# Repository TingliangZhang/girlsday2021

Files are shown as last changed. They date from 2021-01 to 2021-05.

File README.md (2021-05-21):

# Girl's Day of 2021 Presents Design
2021年交叉班女生节礼物——名片 设计

智能名片交互hhh

赛博朋克区块链

## 功能

Tagmo - 制作自己的Amiibo

[Popl - Your digital business card](https://popl.co/)

卡里面只有一个ID和我们服务器网址信息，具体这张名片能传达多少社交信息就由用户在网页端或者客户端配置了。以及最好加密一下，防止被轻易拿去干别的，比如友商出个教程，我们的卡就都变成他们的了

[The Blue Smart Card](https://blue.social/) - Reinventing the Name Tag. Create your virtual identity and be social again.

[Mobilo - The Smart Business Card](https://www.mobilocard.com/)

[Fuze Card, 0.84mm innovative electronic card technology.](https://fuzecard.com/)

KickStarter页面 [Fuze Card](https://www.indiegogo.com/projects/fuze-card-your-whole-wallet-in-one-card--3#/): Your Whole Wallet in One Card

[Unbox Therapy](https://www.youtube.com/channel/UCsTcErHg8oDvUnTzoqsYeNw)评测视频：[Your Whole Wallet In One Card](https://www.youtube.com/watch?v=7SPOVJi3H6g)

[Find Your Keys, Wallet & Phone with Tile's App and Bluetooth](https://www.thetileapp.com/en-us/)

[2.13寸 无源NFC 墨水屏 e-paper ESL电子货架标签 无线供电/刷新](https://item.taobao.com/item.htm?id=613699970326)

微雪NFC墨水屏标签

[小米碰碰贴2](https://item.jd.com/100014996634.html) nfc感应开关 全能投屏音乐接力碰触连网一碰连接米家智能场景

## 可参考项目

[PCB Business Card With NFC](https://www.instructables.com/PCB-Business-Card-With-NFC/) - 能存网址的名片

[THE NFC KEY](https://n-o-d-e.net/nfckey.html) - 存储密钥的带物理按键NFC

[Digital Business Card With NFC](https://www.instructables.com/Digital-Business-Card-With-NFC/) - 只是把NFCTag扔进两张纸之间去了。

[StyloCard](https://mitxela.com/projects/stylocard) - 乐器名片

[L-ink_Card](https://github.com/peng-zhihui/L-ink_Card) - 带墨水屏的NFC Tag

## 问题

手机的NFC功能可能默认关闭，而且NFC线圈位置不固定：苹果在正面顶部，安卓手机大多在背面。

## 进度追踪

2020/12 提出想法，女生节送智能名片

2021/1/27 开始设计

2021/1/28-29 元件选型和天线参数计算

2021/1/30-2/2 天线python脚本生成编写

2021/2/2 第一版测试板交付嘉立创打样，同时采购了元件，同时着手买NFC和RFID读取器

2021/2/4 V2交付打样，使用白色阻焊，尝试效果

2021/2/7 V1V2打样完成，焊接测试完成，功能完好

2021/2/8 开始规划网站服务，并学习React框架

2021/2/9 M24LR-discovery到货，验证了M24能用3.3V驱动STM32L系列单片机和一个液晶数位屏

2021/2/10 诚驰大哥加入，换用VUE框架，小菜鸡我同步开始学Vue

2021/2/11 除夕，依然干活，微雪的2.7inch NFC e-paper到货，测试尝试复现，并用电纸屏送上新年祝福

2021/2/12 大年初一，选取UX和UI设计工具，开始学习Figma

2021/2/13 开工画UX，画了一上午画出来一个登录界面，UX设计师真不容易，决定先用iPad的Procreate来画草图。

2021/2/15 用户体验设计碰头会，根据建议大改了交互流程，继续画了卡片管理界面，同时注册域名

2021/2/16 交给诚驰写网站，开始头大的Ruby和Jekyll开发环境配置

2021/2/17 搞网站备案，头大，Ruby和Jekyll开发环境还是没配好

2021/2/18 为了拿备案服务号，购买了阿里云一年的主机，并且配置Ubuntu环境和VS Code网页版，终于提交管局审核。把一大箱硬件开发的东西寄回清华。

2021/2/19 把Ruby和Jekyll开发环境配置好，其实就放弃了动态构建，只用build吧，研究Jekyll主题的使用

2021/2/20 返校，使用Ubuntu环境跑Jekyll

2021/2/21 - 22 组装服务器并给服务器装系统，走了很多弯路

2021/2/23 装好了Debian KDE 图形化系统，开始探索如何装虚拟化环境、网站部署

2021/2/24 开始部署Proxmox VE虚拟化服务，遇到了网关和DNS一系列问题

2021/2/25 两网站备案成功，但是服务器还是没跑起来，考虑回退回Debian Buster单系统，继续部署网站。

2021/2/26 开始第二个版本的PCB，准备采用黑色Silkskin，银色Paste，背面参考PCB尺子的设计。同时写社交模式。

2021年2月26日22点前后，人生中第一台自己搭出来的服务器和虚拟化子系统开始运行，快乐！

2021/2/27 确定正反面的形式，找到PCB Ruler参考

2021/2/28 传媒研究，定义碰一碰陌生人社交

2021/3/1 绘制V3样板

2021/3/2 交付打样，一共18个订单

2021/3/3 - 3/7 等待到货，同时在阿里云上部署服务，已部署主页和博客俩服务

2021/3/8 在女生节后一天，卡片到货了总共用了一周，嘉立创产能emmm。开始写文档梳理整件事情

2021/3/9 - 10 继续写

2021/3/11-12 要做发布会视频，24h速成blender

2021/3/13 焊芯片+做发布会PPT+建模

## To Do List

- [x] 云服务器配置
- [x] 本地服务器搭建（Dell R720）
- [x] 域名注册
- [x] 域名备案
- [x] SSL证书（上https）
- [x] 网站搭建
- [x] PCB外观设计
- [x] 自动生成PCB脚本编写（集成bitmap2component）
- [x] 硬件原理调试
- [x] UX和UI设计
- [x] 用户体验测试（大雾）
- [x] SD卡大小Tag设计和测试，特别是V槽拼版
- [ ] 加入墨水屏

## 工具

[KiCAD](http://www.kicad.org/)及其插件

[Interactive HTML BOM plugin for KiCad](https://github.com/openscopeproject/InteractiveHtmlBom)

[AutoCAD](https://www.autodesk.com/products/autocad/overview) 2021 Edu Edition

Linux下软件：

[Krita | Digital Painting. Creative Freedom.](https://krita.org/) 绘画软件

[Draw Freely | Inkscape](https://inkscape.org/) 矢量图编辑器

## 外形设计Outline

依据身份证等使用的ISO 7810-2003国际标准中的ID-1：ID-1的规定尺寸为85.60×53.98毫米（3.370×2.125英寸），常用于身份证、银行卡（如提款卡、信用卡）、驾照、个人名片，以及商店发出的忠实顾客卡等。其长宽比与黄金分割（1.618:1）接近。

ISO 7813规范ID-1塑胶银行卡的附加特性，包括0.76毫米厚度，及3.18毫米半径的圆角。

所以设计为

85.60×53.98毫米

3.18毫米半径的圆角

0.76毫米厚度（做0.8mmPCB板）

横向排版

或者用ID-3画成小的钥匙链

## Tile大小版本设计

Tile Pro：42mm x 42mm x 6.5mm  孔7mm直径

Tile Mate：35mm x 35mm x 6.2mm 孔6.5mm

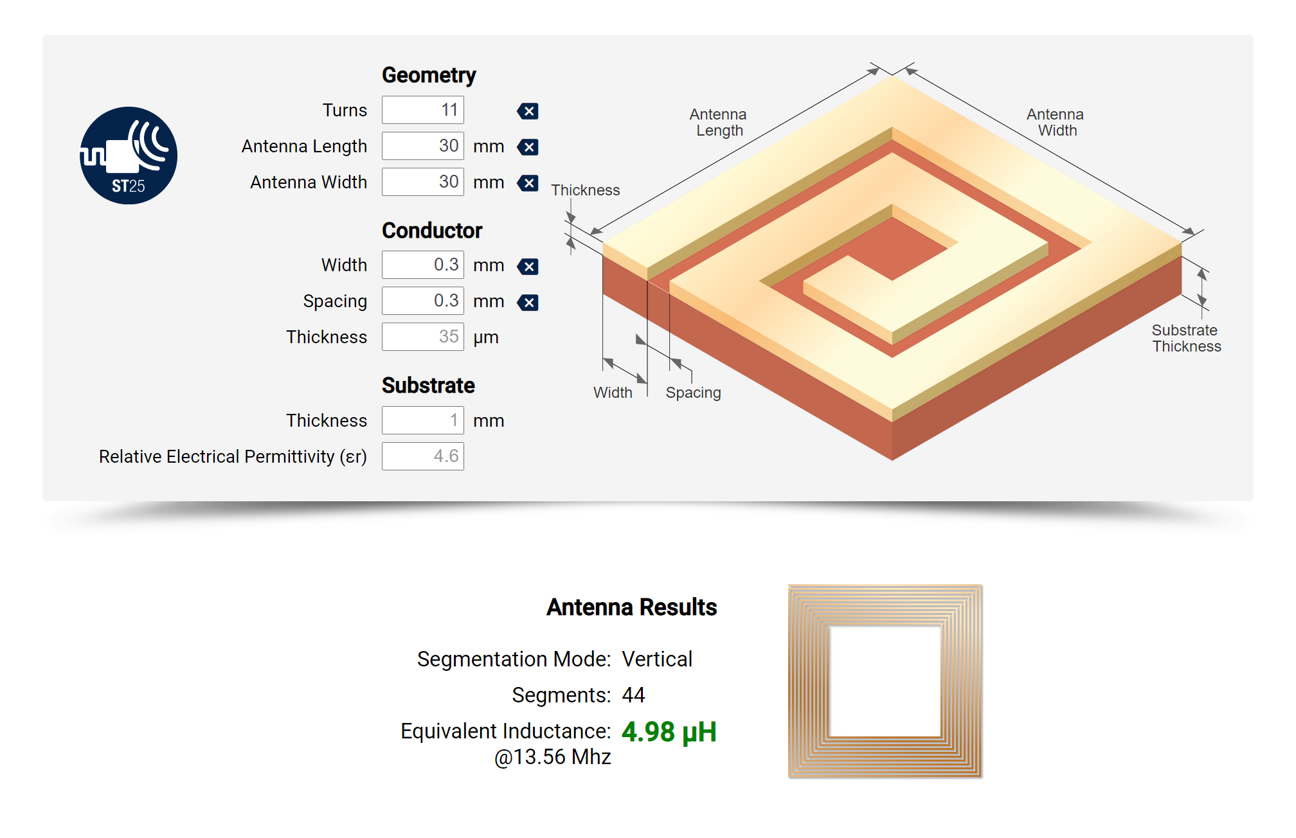
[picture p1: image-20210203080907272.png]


初步设计为 40mm x 40mm x 1.6mm 孔6mm直径 倒角5mm直径圆

天线尺寸为30x30mm 0.3x0.3mm 11圈，电感4.98uH(@13.56Mhz)

天线封装焊盘为 0.3 x 0.5mm圆形通孔（嘉立创双面板最小过孔内径0.3mm,最小外径0.5mm）和 0.3 x 0.5mm矩形贴片焊盘

[嘉立创教学系列之：各软件拼板作业指引](http://club.szlcsc.com/article/details_468_1.html)

嘉立创拼版V割出货：走线和焊盘距板边距离≥0.4mm，否则可能涉及到板内的线路及焊盘，如果是拼版，则线离边必须要有0.4mm间距，否则v割会伤到线路。如果是单片出货，则需要帮≥0.2mm的间距。

VCUT(V割)板边离线的距离不小于0.4MM，CNC（锣边）正常是版边离线的距离不小于0.3MM，内槽离走线离线的最小距离不得小于0.3MM

V-CUT（V割工艺）：

（1）V割的拼板，板与板相连处不留间隙，也就是两块板外形线重叠放置，但是要注意，板子内的导线离V割线距离不小于0.4mm，以免切割时伤到走线。

（2）一般V割后残留的深度为1/3板厚，产品手动掰开后由于玻璃纤维丝有被拉松的现象，尺寸会略有超差，个别产品会偏大以上。

（3）V-CUT刀只能走直线，不能走曲线和折线。

（4）拼板尺寸在8cm以上才能做V-CUT工艺。

拼版设计：

可以考虑30cm x 30cm 九块边缘倒角板子拼起来，横排中间留2mm锣边，纵排无间距V割，纵排两侧有5mm工艺边和2.0mm定位孔及1.0mm的Mark点（一个焊盘）。

全部画在EdgeCut里面就好，嘉立创OEM会帮忙加V割或者锣边，如果版式一样，可以只画一个电路。在复制EdgeCut层的时候，可以在右边隐藏别的层。

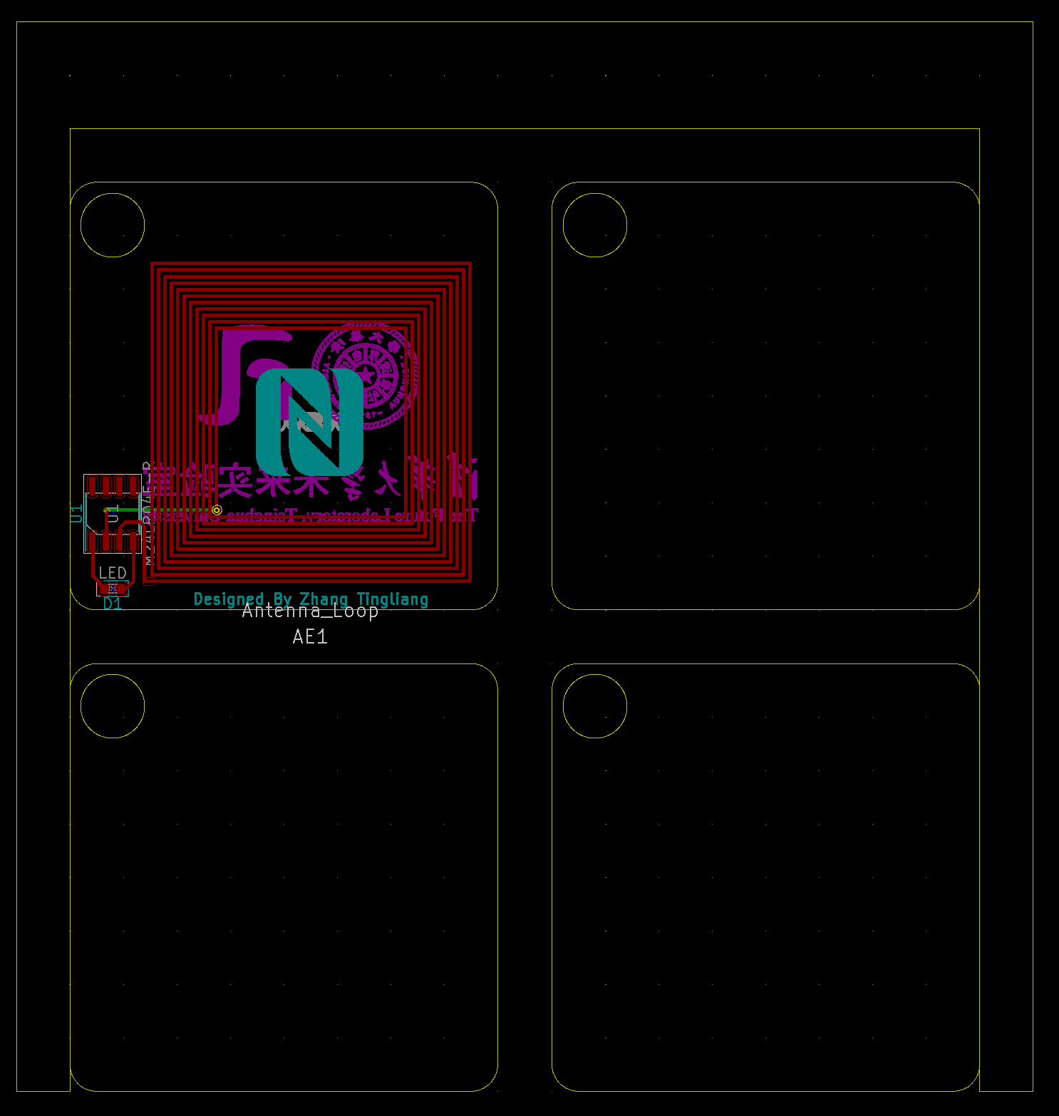
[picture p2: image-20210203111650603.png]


由于强度问题，拼版V割的话还是要紧密连接，不能像上面这种设计。必须要加支撑才行。

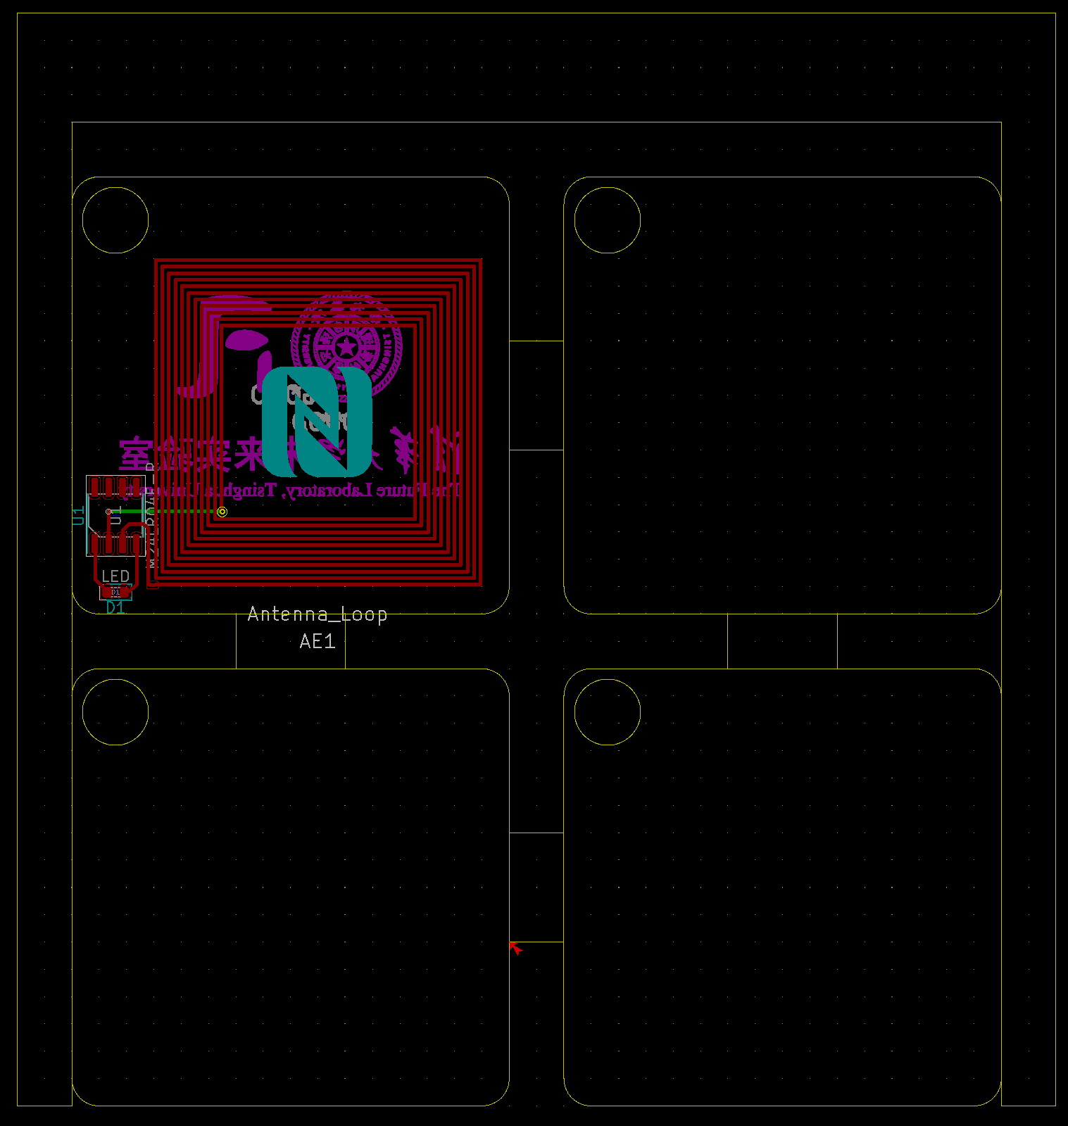
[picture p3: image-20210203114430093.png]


但是拼版订单要多加钱。

所以还是先打单板吧。

## 简笔画头像生成

CV算法生成简笔画头像

[ArtLine](https://github.com/vijishmadhavan/ArtLine)

运行环境：[Colab](https://colab.research.google.com/github/vijishmadhavan/Light-Up/blob/master/ArtLine.ipynb)

CoLab中图片拖到根目录去上传，之后导入：

```python
img = PIL.Image.open("cai.jpg").convert("RGB")
```

[U-2-Net](https://github.com/NathanUA/U-2-Net)还有其前身[APDrawingGAN](https://github.com/yiranran/APDrawingGAN)

## 芯片选型

NXP NTAG

https://www.themobileknowledge.com/wp-content/uploads/2018/07/02-Webinar-slies-Antenna-design-for-NTAG-I2C-plus.pdf

ST25 Dynamic NFC Tags

https://www.st.com/en/nfc/st25-dynamic-nfc-tags.html

ST25DV04K

https://www.st.com/en/nfc/m24lr04e-r.html#overview

[M24LR04E-RMN6T/2](https://item.szlcsc.com/168717.html)[射频卡芯片](https://list.szlcsc.com/catalog/981.html)

测试板：

[M24LR-DISCOVERY](https://www.st.com/en/evaluation-tools/m24lr-discovery.html)

[X-NUCLEO-NFC02A1](https://www.st.com/en/ecosystems/x-nucleo-nfc02a1.html)

## NFC线圈设计

NFC Antenna Generator

https://kbeckmann.github.io/2016/06/19/NFC-Antenna-Generator/

[NFC Antenna Design | RF Design | eDesignSuite](https://eds.st.com/antenna/)

电路中天线电感计算计算：

主要参考AN2866 -  Antenna design procedure

Internal tuning capacitor in ST25DV04K SO8N(f = 13.56 MHz) $C_{TUN} = 28.5 pF$

计算公式：
$$
L_{A} C_{S} \omega^{2}=1
$$
具体推导：
$$
L_{A}=\frac{1}{4 \pi^{2} f^{2} C_{S}}
$$

$$
L_{A}=\frac{1}{4*3.14^{2}*13.56^{2}*28.5}=4.84uH
$$

谐振理论：

At low frequencies $\left(f<f_{\text {self res }} / 10\right),$ the stray capacitance $C_{\text {ant }}$ is negligible, $L_{A}=L_{\text {ant }}$ and the antenna reactance is given by $X_{A}=j L_{\text {ant }} \omega$.
At $13.56 \mathrm{MHz}, \mathrm{C}_{\text {ant }}$ value gets in the range of some $\mathrm{pF}$ and $\mathrm{L}_{\mathrm{A}}>\mathrm{L}_{\text {ant }}$.

The antenna impedance is $Z_{\text {ant }}=R_{A}+j L_{A} \omega$.

The NFC / RFID chip impedance is $Z_{S}=R_{s}+j / C_{S} \omega$.

For the equivalent RLC circuit, the total impedance is $Z_{\text {tot }}=Z_{\text {ant }}+Z_{s}$ and the resonant frequency is given by the condition $L_{A} C_{S} \omega^{2}=1$.
Optimum antenna tuning

At resonant frequency the total impedance reaches its minimum value $Z_{\text {tot }}=R_{A}+R_{S}$. The current in the antenna and the voltage delivered to the NFC / RFID chip are maximized, as the energy transferred to the device.

物理天线电感

嘉立创PCB成品外层铜厚1oz~2oz(35um~70um)选择35um

单片出货，走线和焊盘距板边距离≥0.2mm，否则可能涉及到板内的线路及焊盘。

直接留3.18mm边缘。

最小线隙，多层板3.5mil 单双面板5mil (1mil=1/1000inch=0.0254mm)

Antenna Length =  85.60 - 3.18x2 = 79.24 mm

Antenna Width = 53.98 - 3.18x2 = 47.62 mm

Turns = 6

Equivalent Inductance@13.56 Mhz = 4.98 µH

考虑到布线过程中的寄生电容等，接近4.84 µH，可以接受这一设计。

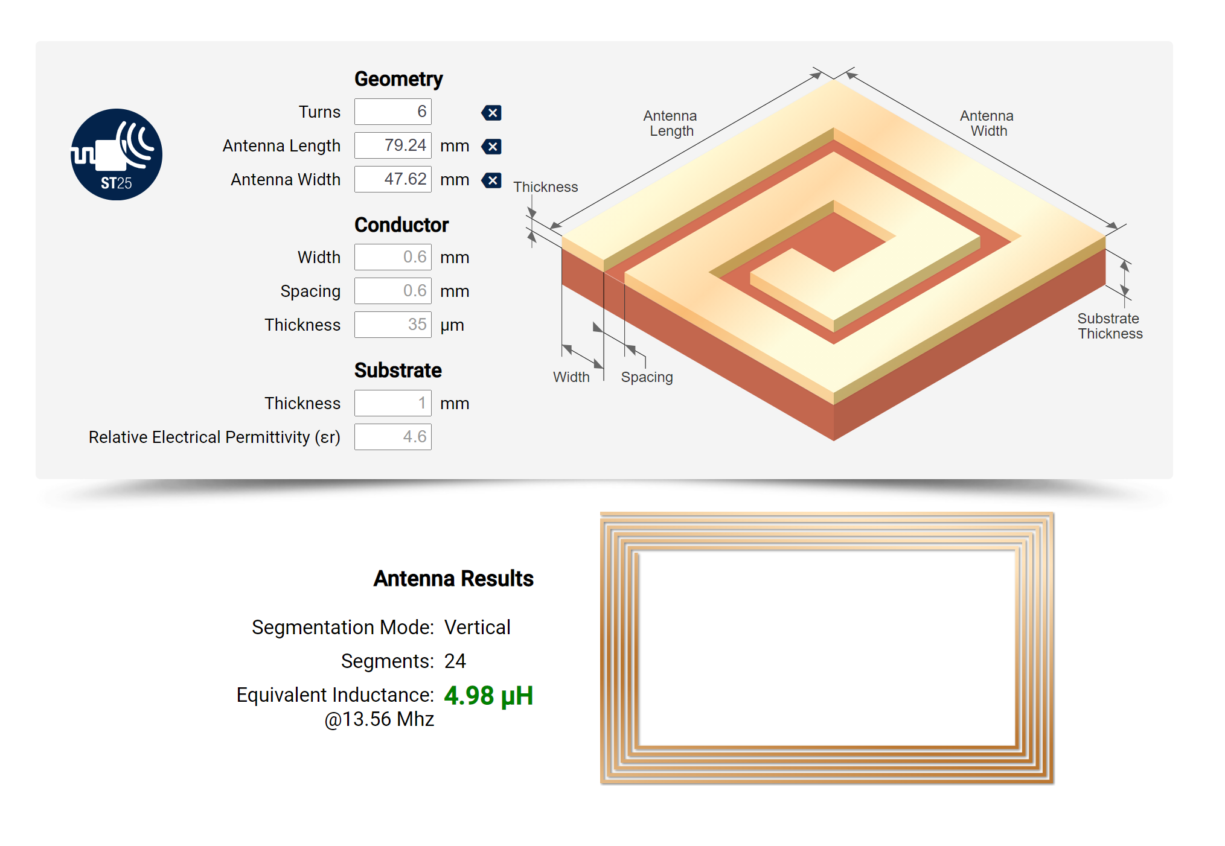
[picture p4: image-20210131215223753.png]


动态NFC天线计算主要参考 AN2972 How to design an antenna for dynamic NFC tags 

封装库画六圈螺线太难了，准备用dxf导入，先使用Adobe Illustrate绘制，依然太麻烦放弃。

还是写py脚本向导吧。

## NFC Antenna创建向导编写

参考官方示例

https://docs.kicad.org/5.1/en/pcbnew/pcbnew.html#Footprint_Wizards

[KiCad Scripting Examples](https://kicad.mmccoo.com/?page_id=83)

参考C:\Program Files\KiCad\share\kicad\scripting\plugins中的脚本。

C:\Users\Zhang\AppData\Roaming\kicad\scripting\plugins

[KiCad](https://github.com/KiCad)/**[kicad-footprint-wizards](https://github.com/KiCad/kicad-footprint-wizards)**

Defining Parameters

Footprint wizards are written in Python and are simple to develop. Each footprint wizard defines a number of footprint parameters, which are organised into categories called "Pages". [Read further on footprint parameters](https://github.com/KiCad/Footprint_Wizards/wiki/Footprint-Parameters)

主要参考microMatch_connectors.py，焊盘直接用SMD的长方形焊盘

To greatly simplify development of custom footprint wizards, the FootprintWizard base class is provided, and only a handful of simple functions need to be written for each wizards. [Read further on minimum wizard requirements](https://github.com/KiCad/Footprint_Wizards/wiki/Minimum-Wizard-Requirements)

先画一个最简单的练手

注意每次更改需要重启KiCAD新脚本才能生效，DeBug的时候因为这个浪费了不少时间。如果加载脚本失败，可以看到报错信息。

通过self.AddParam("Conductor", "spacing", self.uMM, 0.6)传递进来的 self.uMM 其实是已经转化成nm为单位的整型变量了，不需要再用pcbnew.FromMM(1.0)转换为nm。

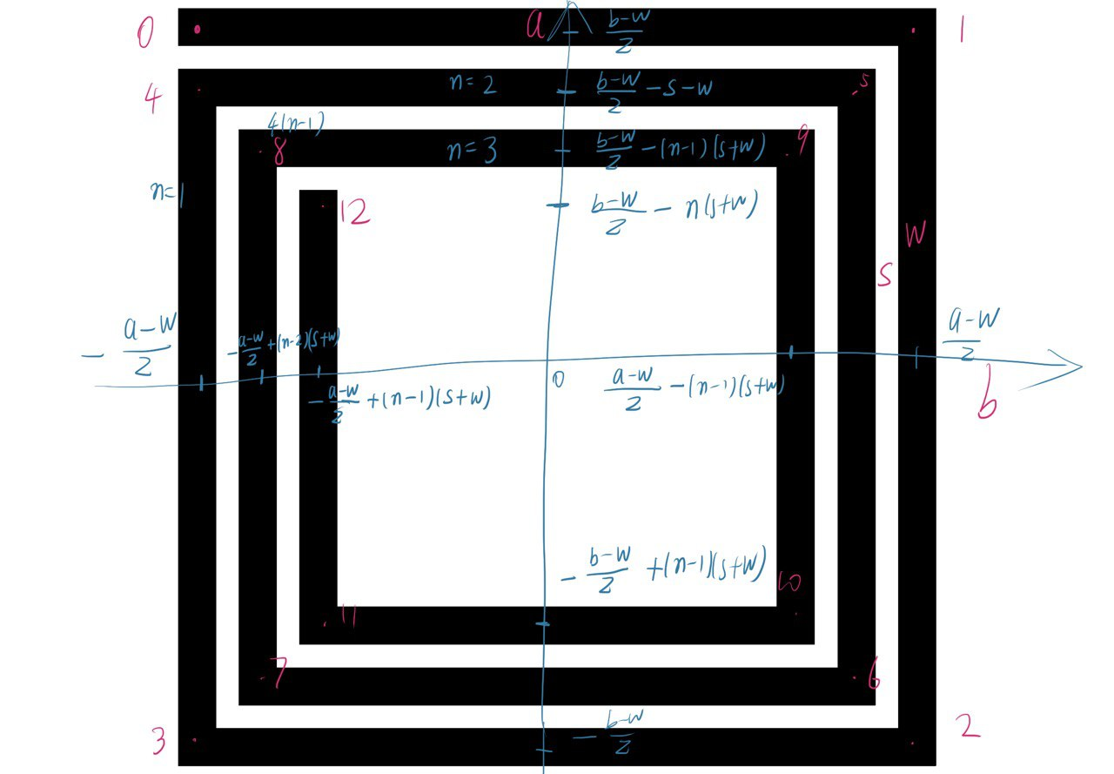
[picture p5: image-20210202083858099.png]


算法可参考HTML的脚本，but我选择自己写hhh

二维数组需要初始化，测试py文件单独编写测试，VScode在安装Python插件后可以在Debug标签页查看变量。

之后手动添加焊盘，嘉立创双面板最小过孔内径0.3mm,最小外径0.5mm，一号焊盘用0.6x1.524mm矩形贴片，注意取消勾选F.Paste和F.Mask工艺层以令外观美观，二号焊盘用圆形通孔0.8x0.5mm，注意取消勾选F.Mask和B.Mask工艺层以令外观美观

左下角：（100，100）

右上角：（185.6，46.02）

中心定位点：（142.8，73.01）

## 信息填写

QR Code Wizard使用丝印层而非铜层

> Use SilkS layer: True
> Use Cu layer: False

字符：

最小字符：线宽6mil 字符高40mil，参数为极限值，尽量大于此参数

故字符采用0.2mm线宽 1mm字符高度

目前仅支持英文字符，KiCAD 6.0 将支持中文字符输入

## 矢量图导入

使用KiCAD主页 位图转换为元件 工具进行转换，直接可以导出kicad_mod文件，注意选择顶层丝印。

调黑白阈值还是很丑的，可以考虑通过Artline生成简笔画。

调整尺寸需要通过调分辨率实现，DPI越高图片越小。注意名片尺寸为85.60×53.98毫米，合适的头像应当为30mm x 30mm

同学们的头像参数调节

| Who | DPI  | 尺寸 | 黑白阈值 |
| --- | ---- | --- | --- |
| NFC Logo | 4000 | 10 x 10mm | 30 |
| cai | 600  | 26 x 26mm | 80 |
| luna | 700  | 30 x 30mm | 70 |
| danni | 300  | 37.3 | 30 |

[Artistic PCB Design for Terrified Beginners](https://wiki.hope.net/index.php?title=Artistic_PCB_Design_for_Terrified_Beginners_workshop)

## NFC + 墨水屏

[实用新型] 一种无源NFC电子墨水屏显示系统 申请号：2020204091829

微雪e-Paper相关资料

https://www.waveshare.net/wiki/Main_Page#Display-e-Paper

特别是驱动板如[e-Paper Driver HAT](https://www.waveshare.net/wiki/E-Paper_Driver_HAT)等

但是屏线多数是SPI，所以估计需要一个STM32转接一下，其实之后的按键等外围设备也需要一个单片机来做。

NFC墨水屏模块

https://www.waveshare.net/wiki/2.7inch_NFC-Powered_e-Paper_Module

NFC烧写器开发板

https://www.waveshare.net/wiki/ST25R3911B_NFC_Board

购买了以上两种产品，发现NFC墨水屏的主控芯片型号竟然被磨掉了。。。



通过SWD接口接入，读取到型号是[STM32L4P5/Q5](https://www.st.com/en/microcontrollers-microprocessors/stm32l4p5-q5.html)，不出所料，ultra‐low‐power系列。

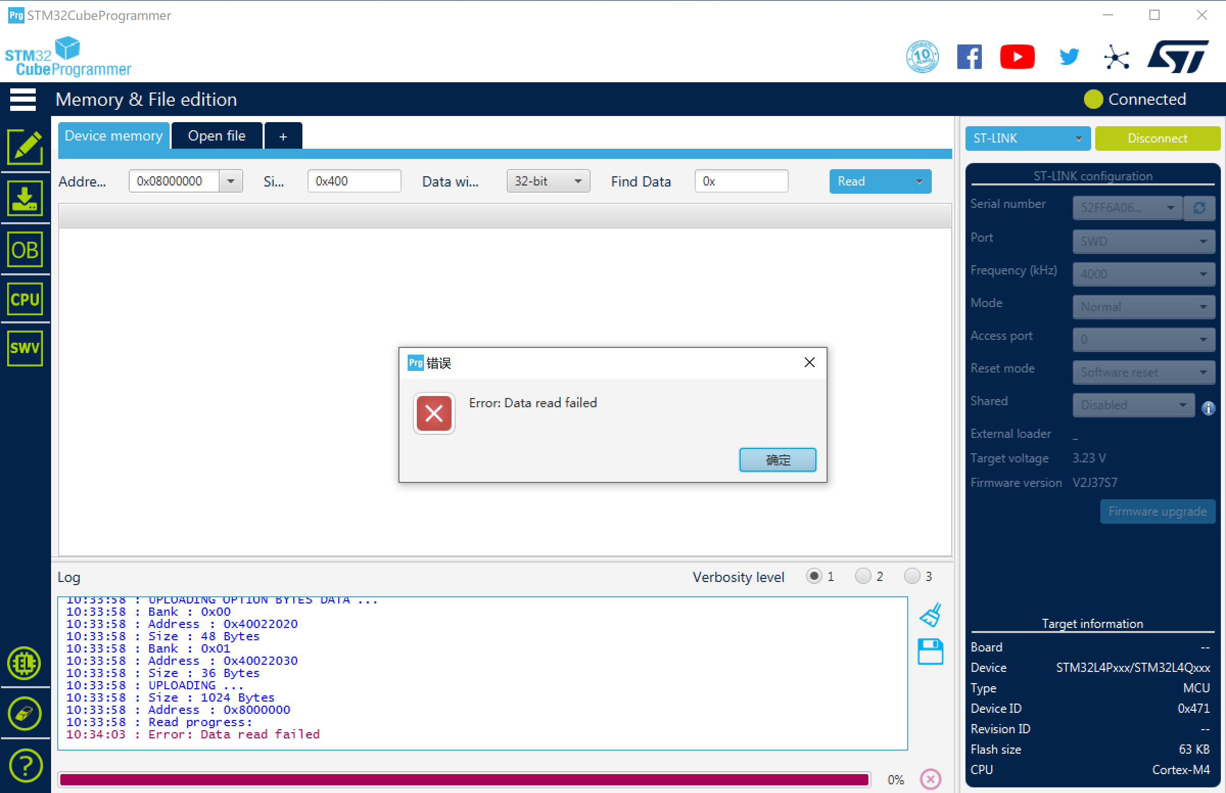
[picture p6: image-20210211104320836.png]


旁边的那个写着ofz 02f s20x的6pin芯片是 TPS62122，降压dcdc

NFC Tag估计是用STM32搞的，用NFC Tools Pro读取得到型号，是一个NXP MIFARE Ultralight

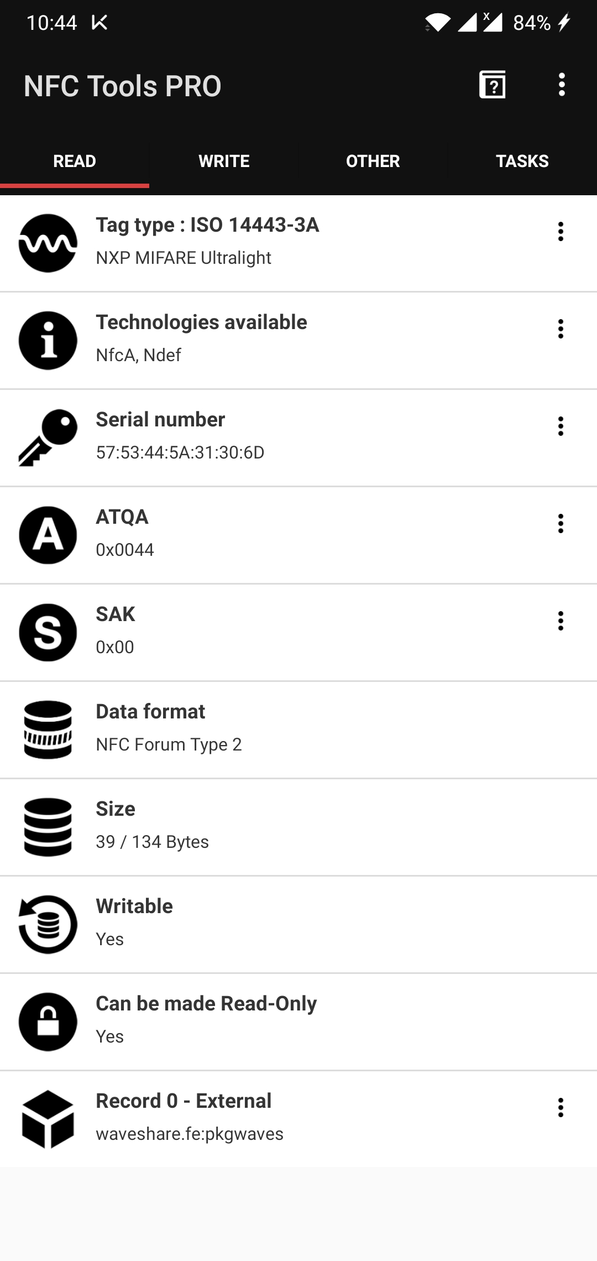
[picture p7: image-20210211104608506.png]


现在量一下电容充电曲线，7.5V，在识别和写图的时候充能，但是没有明显的充放电，应该就是个小电容。

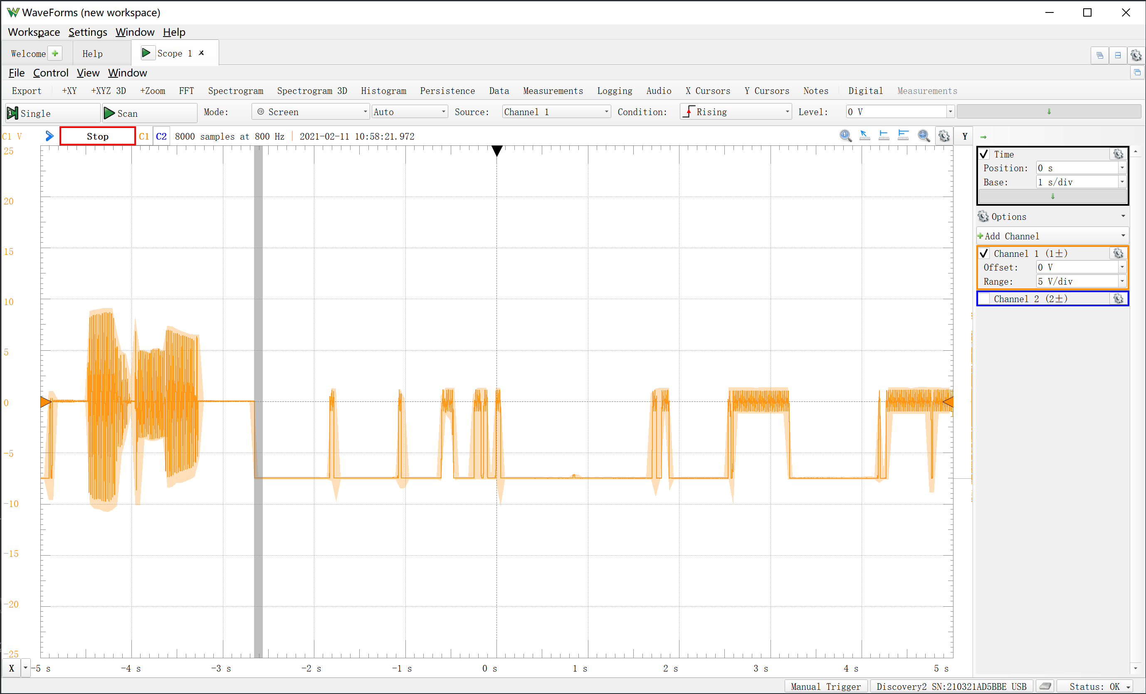
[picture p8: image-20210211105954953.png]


## V1V2焊接调试

注意ST24的marker是一边的斜边对应1号脚所在的位置，其实反色的ST标着对应的也是marker。



在不带载的情况下，EH输出大约为0.5V以下。暂时不上LED了，LED允许电压普遍在2.5V 20mA左右，可能会BOOM。下个版本加电阻吧。

## V3名片设计

增加LED限流电阻

在背面增加两个具有代表性的SMD芯片封装，贴片装饰LQFP-100和BGA-1mm-256

删除头像丝印，规范个人信息排版方式

删除中心定位焊盘

### V3.0 被抛弃的花里胡哨的PCB信仰尺风格设计

背面参考PCB尺子的设计

最典型的就是NVIDIA的尺子，但是可能找不到源文件，只能找类似的参考。

嘉立创PCB

https://lceda.cn/OSHWHubkai-yuan-ying-jian/li-chuangeda-chi-zi

Github and KiCAD

[PCBruler Github Repo](https://github.com/jbtronics/PCBruler)  [PCBrulerS Project Intro](https://hackaday.io/project/25482-pcbrulers) 准备主要参考这一个

[PCB Business Card Ruler With QR and NFC](https://www.instructables.com/PCB-Business-Card-Ruler-With-QR-and-NFC/)

Eagle 开源

[Adafruit-PCB-Ruler](https://github.com/adafruit/Adafruit-PCB-Ruler)

[SparkFun_PCB_Ruler](https://github.com/sparkfun/SparkFun_PCB_Ruler)

放张图纪念一下一晚上的工作

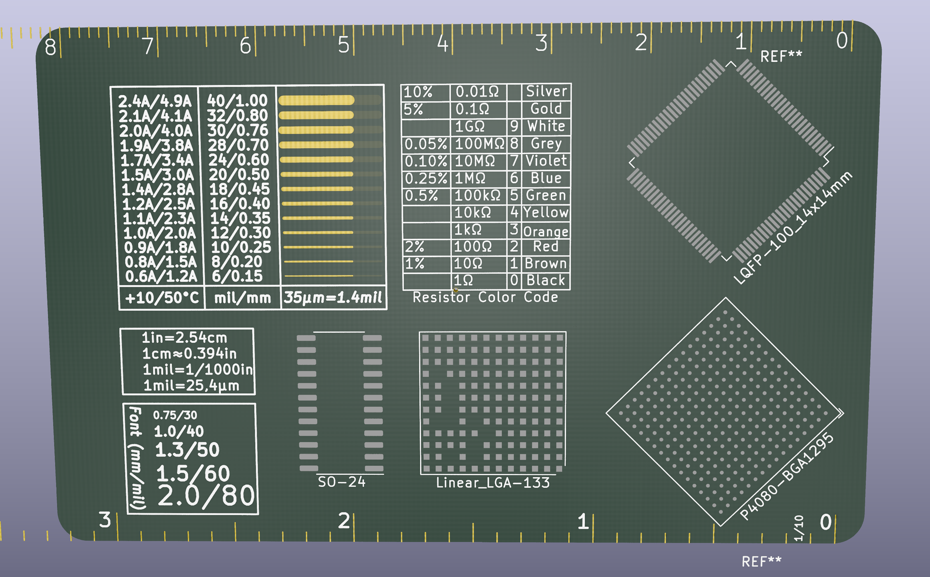
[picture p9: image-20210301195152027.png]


### V3.1版本 简约风设计

考虑电路在背面，个人信息在正面。

背面增加未来交互Logo，在铜层，加阻焊，闪闪发光其实不好看

25mm x 25mm 大小

有一个问题，Logo存在闭合曲线部分，可能电磁感应会有问题，特别是有一部分特别细，有冒烟隐患。

需要更改文件，切断最细部分的连线。由于没有Ai，我用画图3D加上了两个白色的直角三角形，从而断开了回路。

同时删除中心定位焊盘，加入辅助轴原点。

名片正面信息：

姓名

个人标签，如：

交互设计师，用户体验工程师，网页前端架构师，艺术家，嵌入式工程师

美术农民工，影视包工头，码农，极客

头像：30x30mm大小，线宽至少0.2mm

缩放按照1500DPI来，线宽能达到0.3mm，34.7mm正方形，有点大，得调整位置。

身份信息：

Tsinghua University

Info Art Design

Interdisciplinary Project ?

UID?

二维码决定先不做定制化，统一写为interact.cool网址，即跳转到网站登录或APP下载页面，登陆后双方互扫UID码即可。

Designed by Tingliang, Copyright © 2021 Tingliang Zhang CC BY-NC-ND

## V4钥匙链设计

缩小钥匙孔、线圈、整个的尺寸，到30x30cm，以便一个10x10的上面能打9个。

在正面印上未来交互的图案，背面印上二维码。和部分装饰性丝印，比如LQFP-64和BGA-100

天线重新生成一下：0.3mm线宽、0.2mm间距、25*25mm、13圈的线圈，自感4.97uH，接近4.84uH

0.8mm板厚，选择白色或黑色阻焊，3x3V-Cut拼板

## 服务器搭建

服务器选型

Dell R720 2U刀片服务器 3.5寸盘架x8  双路至强E5-2678V2 20核40线程处理器 16G内存 H710阵列卡 3T储存空间（后续可扩容） 750W电源 100Mbps带宽 公网IP

最好带有DELL IDRAC7 企业版授权

BUT 校内1024以下端口不开，而且会被学校查水表，不让校内建站。所以可能还是学生机更好。。。

使用阿里云学生机吧。。。

三丰云可以免费用，但是只用作测试，不能用为生产环境，因为每五天需要点一次延期，太过分了。

[PowerEdge R720](https://www.dell.com/support/home/zh-cn/product-support/product/poweredge-r720/overview)

服务编号(Service Tag)：C8L4Z42

操作系统选择Debian+KVM(Ubuntu+WinServer)

插上E5-2680v2，内存条，开机

第一次开机先清一下H710的默认值，可能之前的设置不对。

重启后按F2进入System Config，最后发现是盘没插好，2.5寸用3.5寸盘架还是有点问题，换成3.5寸就好了

F2-System Setup - Device Settings - H710 Raid setting - Create new virtual disk - Save and restart   就可以成功挂在硬盘到阵列卡上面了，当有 1 Virtual Device 的时候就说明成了。

但是又识别不到U盘了，可能是因为有阵列卡？也可能没断电插拔？重新烧写后按F10-BOOT setting 选择USB设备启动。

注意Debian Live KDE的安装界面锁屏默认密码为Live

总结：首先F2-System Setting - Device Setting - H710 - Create new virtual disk - Initialize - Fast Initialize 

替代办法：https://jingyan.baidu.com/article/4b52d702b7d396fc5d774b49.html 直接ctrl + R进入Raid设置

在BIOS Setting 确认SATA setting是Raid

重启，没有直接引导，需要按F11选择C：-- USB 启动即可

安装的时候BUG无法分区...搜了一下，是因为2T+硬盘要切换成UEFI

[Dell R720上的系统安装问题的解决办法](https://www.cnblogs.com/wgp13x/p/3750957.html)

可以使用[Microsoft Windows and Office ISO Download Tool](https://www.heidoc.net/joomla/technology-science/microsoft/67-microsoft-windows-and-office-iso-download-tool)下载Windows系统，但是好像没有Windows Server 2019

先安Debian：[Debian 64 位 PC（amd64）的安装手册](https://www.debian.org/releases/stable/amd64/)

去tuna下载[Debian 10.8.0 (amd64, DVD installer (Part 1))](https://mirrors.tuna.tsinghua.edu.cn/debian-cd/current/amd64/iso-dvd/debian-10.8.0-amd64-DVD-1.iso)

先安Ubuntu吧qwq

[Installation instructions for Ubuntu Server ](https://ubuntu.com/tutorials/tutorial-install-ubuntu-server)

按照[Create a bootable USB stick on Windows](https://ubuntu.com/tutorials/create-a-usb-stick-on-windows)使用[Rufus](https://rufus.ie/)烧写U盘

最后还是决定用Debian了。。。在Debian里在搞虚拟化主机KVM安Windows之类的

TFTP网络配置需要认真看看。

操作系统选择方面，先使用VirtualBox尝试安装，比如Debian Live之类的。

Debian的各种桌面环境参考：https://www.eet-china.com/mp/a10976.html

[Debian 10.8.0 (amd64, Live CD with gnome and non-free firmware)](https://mirrors.tuna.tsinghua.edu.cn/debian-nonfree/images-including-firmware/current-live/amd64/iso-hybrid/debian-live-10.8.0-amd64-gnome+nonfree.iso)

总结如下：

1. 建立Raid
- 开机，按ctrl+R进行Raid配置
- 选择Raid卡，按F2，清除现有Raid
- 光标选择到Raid卡，按F2，create new VD，将6个HD全做Raid5（或Raid6）
- 按F2，init VD （初始化VD）
- 配置完成后重启
2. 开机按F2进行BIOS设置 （如果总硬盘小于2T此步略去）进入BIOS，将启动模式选择成UEFI
3. 开机按F11进行UEFI启动（如果总硬盘小于2T此步略去）
4. 进入Boot Manager，选择UEFI Boot Menu（如果总硬盘小于2T，选择Bios Boot Menu）
5. 选光驱（插入系统盘）
6. Press any key to install OS

后续高分屏问题解决：尝试使用Quadro K2200专业卡，使用DP输出，但是后面板挡住了DP线，需要一个扁平一点的DP。

服务器后台运行在后面加 & 即可

如果有输出，ssh断开后程序也可能会停止运行，所以在前面加上 nohup

Debian10第一次安装ssh：

```bash
sudo apt-get install ssh
sudo systemctl restart ssh
```

之后可以配置公钥

## 域名备案相关

总的来说：麻烦到爆炸

在购买域名的代理商处进行域名实名认证，在购买云服务器的运营商拿备案服务号，并走备案网站流程。

首先域名实名认证，三天后同步到管局，进行网站备案

在阿里[备案入口](https://beian.aliyun.com/)上传一大堆资料和无数次验证码之后，提交初审，一个工作日后会给你打电话确认，把你的资料改一遍，个人申请不能涉及团队，之后提交管局。

工信部会给你发个短信再次查验身份。

阿里云管局审核最快也得一周以后，基本上通过都是两周以后

备案成功后，会给你的手机，邮箱发送一个备案密码，以及备案号，备案密码一定要好好保管，备案密码是以后变更备案信息的重要依据。

我今天（2021年2月18日）提交的管局审核，女生节前希望能批下来。

## 阿里云服务器相关

纠结好久，最后选择购买阿里云的[轻量应用服务器](https://www.aliyun.com/product/swas)，首先有学生价，其次可以安装Ubuntu，比腾讯云的轻量应用服务器要好。

最主要的是，[网站备案](https://beian.aliyun.com/)需要的[备案服务号](https://help.aliyun.com/document_detail/36938.html)轻量应用服务器实例可以提供5个（参见[支持备案的云服务及备案网站数量](https://help.aliyun.com/document_detail/36891.html)）

我选择安装Ubuntu20.04，进去之后好快啊，通过输入“sudo su root”切换至root账号

可选[用VNC搭建Ubuntu VNC可视化界面](https://help.aliyun.com/knowledge_detail/59330.html)

vnc4server还没出Ubuntu20.04版本的，啊这。。。

我还是用[code-server](https://github.com/cdr/code-server)吧。

### Code-Server安装

> If you choose to use the install script, you can preview what occurs during the install process:
>
> ```sh
> curl -fsSL https://code-server.dev/install.sh | sh -s -- --dry-run
> ```
>
> To install, run:
>
> ```sh
> curl -fsSL https://code-server.dev/install.sh | sh
> ```

### Code-Server SSH forwarding

首先在阿里云设置ssh密码，其实就是root账户的密码。

注意一开始的sed命令要使用admin而非root，而最后本地的user阿里云设置的密码是root密码。

> First, ssh into your instance and edit your `code-server` config file to disable password authentication.
>
> ```sh
> # Replaces "auth: password" with "auth: none" in the code-server config.
> sed -i.bak 's/auth: password/auth: none/' ~/.config/code-server/config.yaml
> ```
>
> Restart `code-server` with (assuming you followed the guide):
>
> ```sh
> sudo systemctl restart code-server@$USER
> ```
>
> Now forward local port 8080 to `127.0.0.1:8080` on the remote instance by running the following command on your local machine.
>
> Recommended reading: https://help.ubuntu.com/community/SSH/OpenSSH/PortForwarding.
>
> ```sh
> # -N disables executing a remote shell
> ssh -N -L 8080:127.0.0.1:8080 [user]@<instance-ip>
> ```
>
> Now if you access [http://127.0.0.1:8080](http://127.0.0.1:8080/) locally, you should see `code-server`!

总结：SSH到云端执行的

```sh
sed -i.bak 's/auth: password/auth: none/' ~/.config/code-server/config.yaml
sudo systemctl restart code-server@admin
```

在本地执行

```sh
ssh -N -L 8080:127.0.0.1:8080 root@47.94.150.220
```

用chrome打开 [http://127.0.0.1:8080](http://127.0.0.1:8080/) 即可访问网页端VScode。

所以每次都得在WSL的Ubuntu里面执行一下再打开浏览器

## 网站搭建

- [ ] 班级主页
- [ ] 个人主页
- [ ] 博客
- [ ] E-mail系统
- [ ] iTag系统
- [ ] 私信系统

### 备案相关注意事项

[【备案】关于网站主页下方标明备案编号的通知（2020年12月28日）](https://help.aliyun.com/noticelist/articleid/1060773630.html)

候选框架：

[Hexo](https://hexo.io/zh-cn/)

[Jekyll](https://jekyllrb.com/)

The world’s fastest framework for building websites | [Hugo](https://gohugo.io/)

[Dreamwaver](https://www.adobe.com/products/dreamweaver.html)自带Bootstrap模板

班级主页

博客

参考网站： [Harry Chen's Blog](https://harrychen.xyz/)

Jekyll主题

https://jamstackthemes.dev/

[beautiful-jekyll](https://github.com/daattali/beautiful-jekyll)

https://jekyllrb.com/docs/

## [Minimal Mistakes Jekyll theme](https://mmistakes.github.io/minimal-mistakes/)

首先安装[Jekyll](https://jekyllrb.com/)，Windows测试选择使用WSL安装

https://jekyllrb.com/docs/installation/windows/

WSL安装：在 程序和功能 中使能 适用于 Linux 的 Windows 子系统，之后在Windows应用商店安装Ubuntu，之后可以通过shift+右键打开bash，也可以在powershell里面输bash激活。

[Install WSL & update to WSL 2](https://docs.microsoft.com/en-us/windows/wsl/install-win10)

Before installing WSL 2, you must enable the **Virtual Machine Platform** optional feature. Your machine will require [virtualization capabilities](https://docs.microsoft.com/en-us/windows/wsl/troubleshooting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) to use this feature.

一开始我以为是bash和虚拟机冲突导致闪退，结果是我没安应用商店的Ubuntu。。。

2021/2/17早上6点更新：WSL还是太麻烦了，在`gem update`卡住了，还是换成[RubyInstaller](https://rubyinstaller.org/) for Windows.

[RubyInstaller](https://rubyinstaller.org/) for Windows 还是挺人性化的，跟着引导安就好。

> 1. Download and install a **Ruby+Devkit** version from [RubyInstaller Downloads](https://rubyinstaller.org/downloads/). Use default options for installation.
> 2. Run the `ridk install` step on the last stage of the installation wizard. This is needed for installing gems with native extensions. You can find additional information regarding this in the [RubyInstaller Documentation](https://github.com/oneclick/rubyinstaller2#using-the-installer-on-a-target-system)
> 3. Open a new command prompt window from the start menu, so that changes to the `PATH` environment variable becomes effective. Install Jekyll and Bundler using `gem install jekyll bundler`
> 4. Check if Jekyll has been installed properly: `jekyll -v`

新建一个 `index.html` 

```html
<!DOCTYPE html>
<html>
  <head>
    <meta charset="utf-8">
    <title>Home</title>
  </head>
  <body>
    <h1>Hello World!</h1>
  </body>
</html>
```

之后使用`jekyll build` 编译，`jekyll serve --livereload`暂时没跑通，有bug

注意在Gemfile里面要使用[Bundler](https://bundler.io/) command才能顺利安装各种gem包

用`jekyll serve --livereload`直接动态编译依然报错，原因应该是 EventMachine 还没支持 Ruby 3.0，算了暂时只build看看吧。

气，卸了换成Ruby 2.7.2

还是报错，不过我终于找到了解决方案：

https://github.com/oneclick/rubyinstaller2/issues/96#issuecomment-679206413

> For Ruby 2.5 and later, try:
>
> ```sh
> gem uninstall eventmachine
> ridk exec pacman -Sy openssl
> gem install eventmachine --platform=ruby
> 
> # 最后运行一下，以解决 Could not find eventmachine-1.2.7-x64-mingw32 in any of the sources 的bundle错误
> bundle update
> ```
>
> `ridk exec pacman -Sy openssl` updates MSYS2 and installs the MSYS2 openssl package. This may take a little while...
>
> `gem install eventmachine --platform=ruby` installs EventMachine but forces compiling the gem
>
> EventMachine's current x64-mingw32 gem is not compatible with Ruby 2.6 and later, and it was accidentally built without that information in the gemspec.

重新编译时间长，完事还是会报错

> If you are using windows
>
> Go to this folder `C:\Ruby24-x64\lib\ruby\gems\{version of ruby}\gems\eventmachine-1.2.5-x64-mingw32\lib`
>
> open this file `eventmachine.rb`
>
> write this `require 'em/pure_ruby'` in the first line of code in the file
> this will make it work with no issues.

这次不报`Unable to load the EventMachine C extension; To use the pure-ruby reactor, require 'em/pure_ruby'`错了，报了`pure_ruby.rb:559:in `close': Bad file descriptor (Errno::EBADF)`

看各种stack overflow貌似是端口占用？

放弃。。。Ruby真不友好。。。

先尝试示例吧，在test下面

```sh
cd ./test
bundle update
jekyll server
jekyll server --livereload
```

woc，竟然直接成了。。。程序样例赛高~ さいこう

但是如果打开livereload会发现如下信息

```sh
This port only serves livereload.js over HTTP.
```

也就是说还需要别的才能实时。

## VirtualBox + Ubuntu20.04

为了给Ruby提供测试环境，安一个Ubuntu虚拟机，预计之后的云服务器和本地自建服务器生产环境都是Ubuntu20.04。

设置root密码

```sh
$ sudo passwd
[sudo] grace 的密码:        #输入grace账号的密码
新的 密码:                  #定义root密码
重新输入新的 密码:           #确认root密码
password: 已成功更新密码     #成功提示
$ su                       #su验证登录
```

安装增强功能

```sh
$ su #切换root账号
$ apt-get update   #更新源
$ sudo apt-get install build-essential gcc make perl dkms  #安装依赖
$ reboot  #重启系统
```

直接 设备 -> 安装增强功能 -> 运行 -> 重启系统 是不行的，需要先安依赖。参考[VirtualBox Guest Additions installation problem ](https://askubuntu.com/questions/1035030/virtualbox-guest-additions-installation-problem)

```sh
# 如果没弹窗，可以手动运行.run文件
sudo ./VBoxLinuxAdditions.run
```

安gcc的时候报错：E: Unable to correct problems, you have held broken packages.

https://blog.csdn.net/xpy870663266/article/details/94742491

尝试修复：

```sh
$ sudo dpkg --configure -a
$ sudo apt-get update
$ sudo apt-get autoremove
$ sudo apt-get -f install
```

没用，手动安装指定的包吧。

尝试使用aptitude而不是apt-get

```sh
apt install aptitude
aptitude install build-essential gcc make perl dkms
```

还是没解决。

常见的疑难杂症：

[Unable to lock the administration directory (/var/lib/dpkg/) is another process using it?](https://askubuntu.com/questions/15433/unable-to-lock-the-administration-directory-var-lib-dpkg-is-another-process)  其实跟有可能你没sudo哈哈哈

不锁屏设置：System Settings-Privacy-Screen Lock-Automatic Screen Lock-Off

改镜像源：

Ubuntu 的软件源配置文件是 `/etc/apt/sources.list`。将系统自带的该文件做个备份，将该文件替换为下面内容，即可使用 TUNA 的软件源镜像。

```shell
# 默认注释了源码镜像以提高 apt update 速度，如有需要可自行取消注释
deb https://mirrors.tuna.tsinghua.edu.cn/ubuntu/ focal main restricted universe multiverse
# deb-src https://mirrors.tuna.tsinghua.edu.cn/ubuntu/ focal main restricted universe multiverse
deb https://mirrors.tuna.tsinghua.edu.cn/ubuntu/ focal-updates main restricted universe multiverse
# deb-src https://mirrors.tuna.tsinghua.edu.cn/ubuntu/ focal-updates main restricted universe multiverse
deb https://mirrors.tuna.tsinghua.edu.cn/ubuntu/ focal-backports main restricted universe multiverse
# deb-src https://mirrors.tuna.tsinghua.edu.cn/ubuntu/ focal-backports main restricted universe multiverse
deb https://mirrors.tuna.tsinghua.edu.cn/ubuntu/ focal-security main restricted universe multiverse
# deb-src https://mirrors.tuna.tsinghua.edu.cn/ubuntu/ focal-security main restricted universe multiverse

# 预发布软件源，不建议启用
# deb https://mirrors.tuna.tsinghua.edu.cn/ubuntu/ focal-proposed main restricted universe multiverse
# deb-src https://mirrors.tuna.tsinghua.edu.cn/ubuntu/ focal-proposed main restricted universe multiverse
```

具体先备份后用vi编辑后 :wq

```sh
cp /etc/apt/sources.list /etc/apt/sources.list.bak
rm /etc/apt/sources.list
vi /etc/apt/sources.list
```

不改的话会慢到龟速。。。当然阿里云就不用了，默认镜像源是阿里源，贼快。

Chromium以及VScode直接用应用商店安就好了。

完事可以尝试安装Ruby运行环境和

## 虚拟化操作系统搭建

KVM虚拟机选择

先在本地尝试，需要一个测试用电脑，我大一用的老笔记本挺合适的。2021/2/23晚重新启用老电脑

https://www.proxmox.com/en/

[Proxmox VE Wiki](https://pve.proxmox.com/wiki/Main_Page)

教程：基于Debian10搭建ProxmoxVE 6虚拟化环境 https://www.jianshu.com/p/411e66dba2b2

下载ISO镜像，可以选择清华TUNA源[proxmox-ve_6.3-1.iso](https://mirrors.tuna.tsinghua.edu.cn/proxmox/iso/proxmox-ve_6.3-1.iso)

[proxmox | 镜像站使用帮助 | 清华大学开源软件镜像站](https://mirrors.tuna.tsinghua.edu.cn/help/proxmox/)

烧写镜像

> Using Etcher
>
> Etcher works out of the box. Download Etcher from [https://etcher.io](https://etcher.io/). It will guide you through the process of selecting the ISO and your USB Drive.
>
> Using Rufus
>
> Rufus is a more lightweight alternative, but you need to use the **DD mode** to make it work. Download Rufus from https://rufus.ie/. Either install it or use the portable version. Select the destination drive and the Proxmox VE ISO file.
>
> Once you *Start* you have to click *No* on the dialog asking to download a different version of GRUB. In the next dialog select the *DD* mode.

插上去安装，按照提示安就好，最后通过https:// IP :8006 访问控制台。

在Debian之上安装PVE

[Install Proxmox VE on Debian Buster](https://pve.proxmox.com/wiki/Install_Proxmox_VE_on_Debian_Buster)

先尝试一下这个

Proxmox 镜像使用帮助

新建 `/etc/apt/sources.list.d/pve-no-subscription.list`，内容为：（Debian 10）

```
deb https://mirrors.tuna.tsinghua.edu.cn/proxmox/debian buster pve-no-subscription
```

ISO安装文件下载：https://mirrors.tuna.tsinghua.edu.cn/proxmox/iso/

R720上Proxmox的问题

貌似Proxmox识别到的IP段不对，是`192.168.100.2`，不是接入的网口的IP `192.168.50.xxx`，所以从其他电脑无法访问，而且会让router无法工作。

https://forum.proxmox.com/threads/fresh-install-sees-network-but-not-internet.83670/

改一下`/etc/network/interfaces`中对应网口的IP，改为对应的IP段，想要的IP，比如`192.168.50.233:22`，网关也改成对应的，比如`192.168.50.1`，Router就会自动给服务器分配一个静态IP。

注意编辑前cp一下备份。VI编辑器，I进入插入模式后，不要动前后左右键。ESC推出到命令模式。X删除当前字符。结合着来，:q!不保存强制退出，:qw保存并退出。

结果从服务器上ping路由器网关`192.168.50.1`，不通，搞了半天发现我网线插到了2号网卡上面，刚刚我配置的是1号卡。。。

https://192.168.50.233:8006/

在局域网下其他计算机浏览器中访问此页面即可进入管理页面，注意是HTTPS！

Default login is "root" (realm *PAM*) and the root password is defined during the installation process.

现在问题有俩，一个是DNS有毒，另一个是无法挂载exFAT格式的移动硬盘拷子系统镜像。

ping百度的IP能ping通，说明连上了公网，但是`apt-get update`全不行，说明DNS有问题。

编辑`/etc/resolv.conf`换用tuna的DNS：`101.6.6.6`

之后

```sh
service networking restart #重启网络
```

终于可以`apt-get update`了！

Debian10尝试重启没啥问题，不过Debian8和9貌似直接编辑`/etc/resolv.conf`重启后会重置，Debian 永久修改 DNS需要安装resolvconf包

```shell
apt-get install resolvconf -y
nano /etc/resolvconf/resolv.conf.d/head
prepend nameserver 101.6.6.6 #或者直接加一行
reboot #重启
```

首先，移动硬盘应该是exFAT格式，在Windows上先格式化好。其次需要挂载才能访问，挂载是到特定的文件夹中。

应该是把需要的iso文件放到`/var/lib/vz/image`中，即PVE的Storage-Directory-local，创建VM时会在这个文件夹下面去找，应该可以直接把移动硬盘挂载到这个路径里面，但是我还是cp一下，以备之后使用。具体操作如下：参考https://blog.csdn.net/u010334295/article/details/82592472

```sh
fdisk -l
cd ~
mkdir PortableDisk
mount /dev/sdb1 PortableDisk
chmod 777 PortableDisk #可选，复制出来文件不需要，777是最高权限
cd PortableDisk
ls
cp ./debian-live-10.8.0-amd64-kde+nonfree.iso /var/lib/vz/image/debian-live-10.8.0-amd64-kde+nonfree.iso
```

但是u其实并不行，还是找不到iso，之后再说吧。哦，从Bug的GUI上传了之后能显示了。所以需要先上传再拷，同名文件覆盖，就能在VM创建界面看到了

草，其实双击Server View-interaction-Search-storage-local-ISOimage可以上传iso（可能需要多试几次才能蹦出来ISOimage），而且点interaction右上角的Shell-xterm.js或者左侧标签页的Shell还可以远程命令行。我跑来跑去真锻炼身体。。。

大草，甚至能在GUI下面改DNS。

！注意，PVE自带的GUI上传有问题，大于2G的iso会被只传1G不到，所以还是要直接cp。附带几个命令看是不是拷成功了。大坑之一

```sh
du -sh # 查看文件夹大小
du -sh * | sort -n # 统计当前文件夹(目录)大小，并按文件大小排序
```

开始创建VM，起名叫Debian，选择debian-live-10.8.0-amd64-kde+nonfree.iso镜像，硬盘给100G，CPU给两块各4核，内存给4G，其他默认就好。Start after create之后用noVNC连接就能有远程桌面啦！

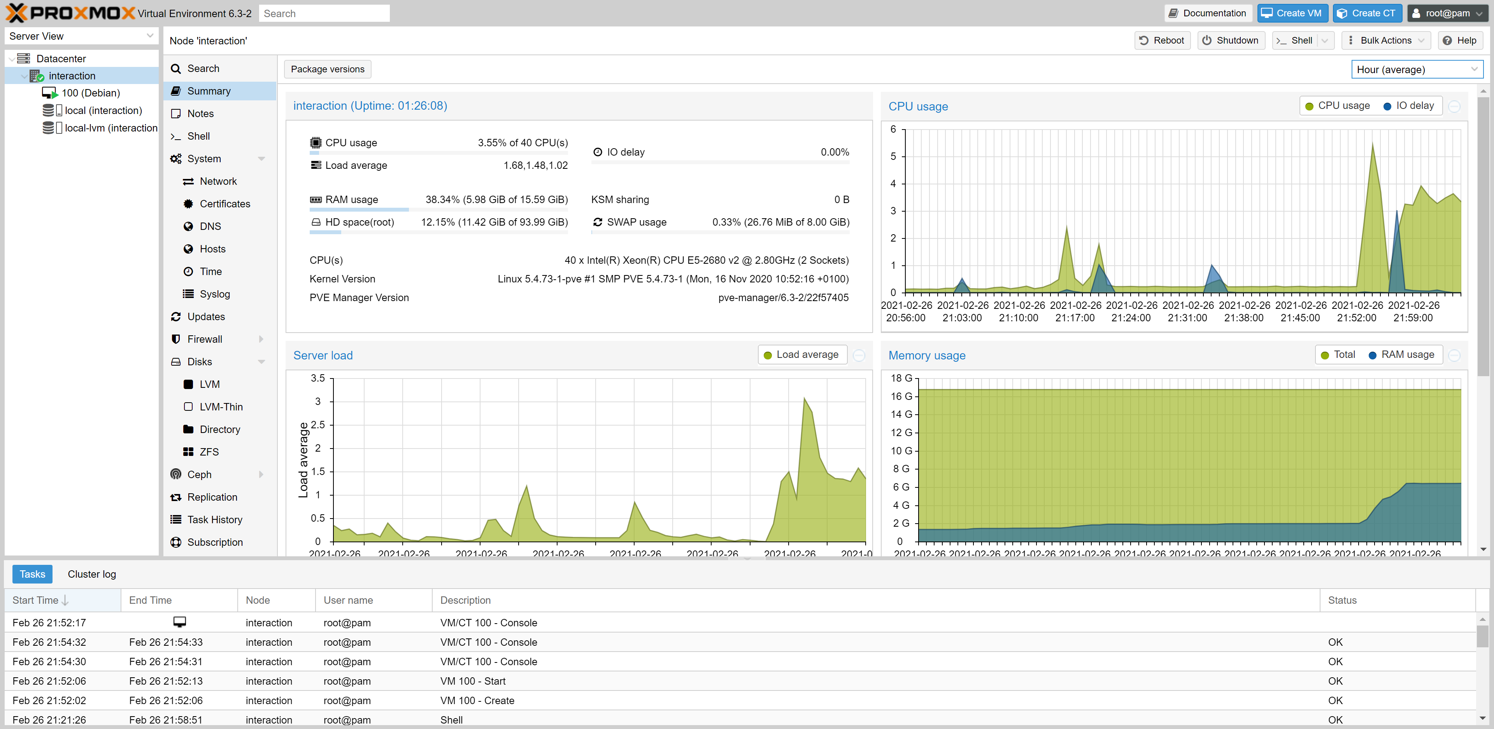
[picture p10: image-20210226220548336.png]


人生中第一台服务器和虚拟化的子系统，太快乐了！

使用Debian Live安装好之后重启，进到了tty1命令行而非KDE GUI，得想办法启动KDE桌面环境

可以使用

```sh
startx
```

命令，启动桌面化环境。

20210318折腾想把服务器直接挂到校园网下面，but PVE环境并不支持DHCP，放弃

分配账号需要用root账号在PVE命令行里面先useradd一下用户名，之后才能创建成功账号。

## Nano Pi

因为遇到校园网问题：(IP地址异常，请重新拿地址) E2833: Your IP address is not in the dhcp table. Maybe you need to renew the IP address.

配置OpenVPN到工场暂时用一段时间。

玩转NanoPi R2S

中文维基 [NanoPi R2S/zh](http://wiki.friendlyarm.com/wiki/index.php/NanoPi_R2S/zh)

英文维基 [NanoPi R2S](http://wiki.friendlyarm.com/wiki/index.php/NanoPi_R2S)

SD卡自带FriendlyCore

FriendlyARM   NanoPi R2S 的核心  Rockchip RK3328 是 armv8 架构，所有智能用Openwrt官方的snapshot，还是刷FriendlyWrt吧。

### 基本使用

在电脑浏览器上输入以下网址即可进入FriendlyWrt管理页面:

- http://friendlywrt/
- http://192.168.2.1/

升级所有的软件包（慎用）

```sh
opkg update
opkg list-upgradable | cut -f 1 -d ' ' | xargs opkg upgrade 
```

升级之后万年起不来，重新烧写固件qwq

[FriendlyCore](http://wiki.friendlyarm.com/wiki/index.php/FriendlyCore_(based_on_ubuntu-core_with_Qt)) (based on ubuntu-core with Qt)是开发用的核心，FriendlyWrt的使用基本上和Openwrt一致。

### 安全的关机操作

进入ttyd终端，输入poweroff命令敲回车，待led灯熄灭，再拔开电源。

### 建议的安全性设置

以下设置事项非常建议在将 NanoPi-R2S 接入互联网之前完成，因为在空密码或弱密码的状态下将NanoPi-R2S接入互联网，极易受到网络攻击。

- 设置一个安全的密码

进入 系统->管理权 界面设置密码。

- 禁止从wan访问ssh，更换端口

进入 系统->管理权->SSH访问，将接口限制为 lan，将端口设置为其他非常用端口，例如 23333。

- 只允许本地设备访问luci

编辑 /etc/config/uhttpd，将原来的0.0.0.0和[::]地址改为本地lan的地址，例如：

```
	# HTTP listen addresses, multiple allowed
	list listen_http	192.168.2.1:80
	list listen_http	[fd00:ab:cd::1]:80
 
	# HTTPS listen addresses, multiple allowed
	list listen_https	192.168.2.1:443
	list listen_https	[fd00:ab:cd::1]:443
```

完成后重启服务：

```
/etc/init.d/uhttpd restart
```

### OpenVPN client using LuCI

https://openwrt.org/docs/guide-user/services/vpn/openvpn/client-luci

Install [openvpn-openssl](https://openwrt.org/packages/pkgdata/openvpn-openssl) and [luci-app-openvpn](https://openwrt.org/packages/pkgdata/luci-app-openvpn) to be able to manage OpenVPN using web interface.

```sh
opkg update
opkg install openvpn-openssl
opkg install luci-app-openvpn
```

也完全可以用图形化界面来搞，搞完重启就好。

注意配置Auth

```shell
auth-user-pass /etc/openvpn/Skyworks.auth
```

另外注意用Ubuntu的那个配置文件，复制粘贴进去，才能跑。

但是一直AUTH_fail不知道为啥了

## Debian相关

安装OpenVPN和RSA

```shell
# 安装OpenVPN和RSA
sudo apt-get install openvpn
# 复制粘贴配置文件
sudo cp skyworks.conf
# 可选添加一个auth-user-pass文件，注意搞完全地址
auth-user-pass /etc/openvpn/Skyworks.auth
# 启动服务
sudo openvpn --config /etc/openvpn/skyworks.conf
```

## 成本估算

若使用NT2H1311G0DA8(Active)

[贸泽电子 Mouser](https://www.mouser.cn/) ¥0.97293 56,000+ ¥1.01135 28000+

[得捷电子 Digikey](https://www.digikey.cn/) ¥2.22699 28,000+

国产标签更便宜，具体不知道，淘宝成品国产213标签贴纸只要0.5元一个

https://detail.tmall.com/item.htm?id=558903918774&skuId=4662813582687

https://detail.tmall.com/item.htm?id=559010411708&skuId=4490394728367

## 可以用来扯的之后可能有用的东西

Ansys HFSS 适用于 RF 和无线设计的 3D 电磁场模拟器

https://www.ansys.com/zh-CN/products/electronics/ansys-hfss

参照NXP NTAG的 [应用说明](https://www.nxp.com.cn/docs/en/application-note/AN11276.zip) 进行HFSS仿真

## 发布会idea

乔布斯iPhone发布会三种产品复读机，不是三种而是一种产品。

更有豪华至尊暗黑版iTag Pro Max Carbon Plus庭梁签名特别版

良心价，9999 津巴布韦币（也就是0.99RMB）年轻人的第一张Tag，即日起开启线上线下预定封测。

## 供参考产品

国内平台太多了

https://www.zhihu.com/question/275443233

国外产品：

### Tinder

[Tinder Releases Face to Face Video](https://www.tinderpressroom.com/Tinder-Begins-Testing-Face-to-Face-Video) 交友软件都开始搞Video Date了，视频通话少不了啊，其实微信能替代就还好hhh

[Google Store](https://play.google.com/store/apps/details?id=com.tinder) 417w下载量，但是最近多半差评，Bug巨多，Liked没反馈也饱受诟病。

看脸左滑右滑有点草率

### Match

主页宣传：每5段恋爱关系中，就有1段从网路萌芽，其中更多始于Match。

[Match Dating](https://play.google.com/store/apps/details?id=com.match.android.matchmobile): Chat, Date & Meet Someone New 的 Google Store下载量才11w，但最近评价好坏参半

在Match.com，我们给会员提供各种自我陈述空间，让他们展示自我。会员的档案可最多包含26张照片，也可以根据他们要寻找的对象设定喜好。鼠标轻轻一点，会员就能立即看到自己所在地区单身人士的照片和资料。同时，Match.com也理解隐私权和真实性的重要。在Match.com上，所有会员之间的交流都是透过“匿名”电子邮件系统实现。我们所有会员的姓名和联系方式均保持保密状态，直到此会员自己决定向某位潜在匹配对象公开这些讯息。

### Hinge - The dating app designed to be deleted

https://hinge.co/

https://play.google.com/store/apps/details?id=co.hinge.app&hl=en&gl=US

https://www.pcmag.com/reviews/hinge

更详细的个人资料，人工智能匹配算法，稍少的Like限制（10个也太少了，20个一个月20刀太贵了）

约会前后发放调查问卷，进行行为学调查。收集用户数据，改善服务提供模式。还有个Lab俩人像模像样研究

约会前冥想服务。联名馊主意

估计已经凉凉了，盈利模式太显而易见，割韭菜让用户都差评了，一共不到15w用户。

## 网页端

### 框架选择

[React – A JavaScript library for building user interfaces](https://reactjs.org/)

[Vue.js](https://cn.vuejs.org/index.html)

[Angular](https://angular.io/)

[Django](https://www.djangoproject.com/) - The Web framework for perfectionists with deadlines

### 数据库选择

SQL(Relational Database) or NoSQL(Non-Relational Database)

[What is a database in under 4 minutes](https://www.youtube.com/watch?v=Tk1t3WKK-ZY)

#### NoSQL

[MongoDB](https://www.mongodb.com)

[Apache CouchDB](http://couchdb.apache.org/)

[Amazon DynamoDB | NoSQL Key-Value Database](https://aws.amazon.com/dynamodb/)

#### SQL

[PostgreSQL: The World's Most Advanced Open Source Relational Database](https://www.postgresql.org/)

[SQL Server 2019 | Microsoft](https://www.microsoft.com/en-us/sql-server/sql-server-2019)

[MySQL](https://www.mysql.com/)

### React入门

[Tutorial: Intro to React](https://reactjs.org/tutorial/tutorial.html)

If you need to review JavaScript, we recommend reading [this guide](https://developer.mozilla.org/en-US/docs/Web/JavaScript/A_re-introduction_to_JavaScript).

[Next.js](https://nextjs.org/) is a popular and lightweight framework for **static and server‑rendered applications** built with React. It includes **styling and routing solutions** out of the box, and assumes that you’re using [Node.js](https://nodejs.org/) as the server environment.

Learn Next.js from [its official guide](https://nextjs.org/learn/).

### 傻瓜式操作

[Free Website Builder | Create a Free Website | Wix.com](https://www.wix.com/)

[WordPress.com: Create a Free Website or Blog](https://wordpress.com/)

### 需求

实现

用户新Tag拿到手时候扫描Tag，数据库查询UID是否被注册用户绑定，并结合密钥验真。弹出注册或登录页面，如果已经登陆使用Cookie登录。

登陆后用户可以填写自己的个人信息，组织并选择这个名片能访问的个人信息，生成类似于个人主页门户的页面，预览并确认后，数据库记录数据和顺序。

收到Tag的另一用户自行NFC读取到特定网址+ID+密钥的时候，能弹出社交信息分享页面。

如果是可复用的，可以设置页面有效期，在一段时间后密钥更换，使用原链接和密钥地址无法访问或只能访问原先定义的信息。

如果是扫码，逻辑基本一致，针对手机太老没有NFC功能的提供二维码分享功能，但是是阉割版，无法更改二维码的信息，故编辑信息不具有保密性，需要在第一次编辑的时候提醒用户。微信扫码提示按右上角由浏览器打开。

准备包含的社交软件有：

1. 微信
2. QQ
3. TIM
4. Telegram
5. 微博
6. Linkedin
7. Instagram
8. 钉钉
9. 飞书
10. 哔哩哔哩
11. 个人网站
12. 斗鱼直播
13. Steam
14. Skype
15. Facebook
16. Twitter
17. Github
18. Slack
19. Snapchat
20. Reddit
21. Twitch
22. Google+
23. Pinterest
24. Dribbble
25. Flickr
26. Tumblr
27. 作品集网站叫啥我忘记了

## UI和UX设计 Using Figma

https://developer.apple.com/design/resources/

Adobe XD

[Figma: the collaborative interface design tool.](https://www.figma.com/)

Figma有教育版，免费用。在申请教育版的时候可以把申请年限填到最长，edu邮箱自动审核。

[FigmaChina：Figma 中文网](https://figmachina.com/)

Figma有些挺好的模板可以用

[UI Prep: The Best Design System UI Kit for Figma](https://www.uiprep.com)

系统字体在里面。Microsoft Yahei就好

### NFC

https://developer.apple.com/design/human-interface-guidelines/ios/user-interaction/near-field-communication/

### 参考项目示例

[(Variants) iOS & iPadOS 14 UI Kit for Figma](https://www.figma.com/community/file/858143367356468985/(Variants)-iOS-%26-iPadOS-14-UI-Kit-for-Figma)

Prototyping in Figma (Offical Tutorial)

[coolicons | Free Iconset](https://www.figma.com/community/file/800815864899415771/coolicons-%7C-Free-Iconset)

[Figma Charts Infographics UI kit](https://www.figma.com/community/file/855517047816771255/Figma-Charts-Infographics-UI-kit)

[Simple Profile Icebreaker Activity](https://www.figma.com/community/file/798962767266141877/Simple-Profile-Icebreaker-Activity)

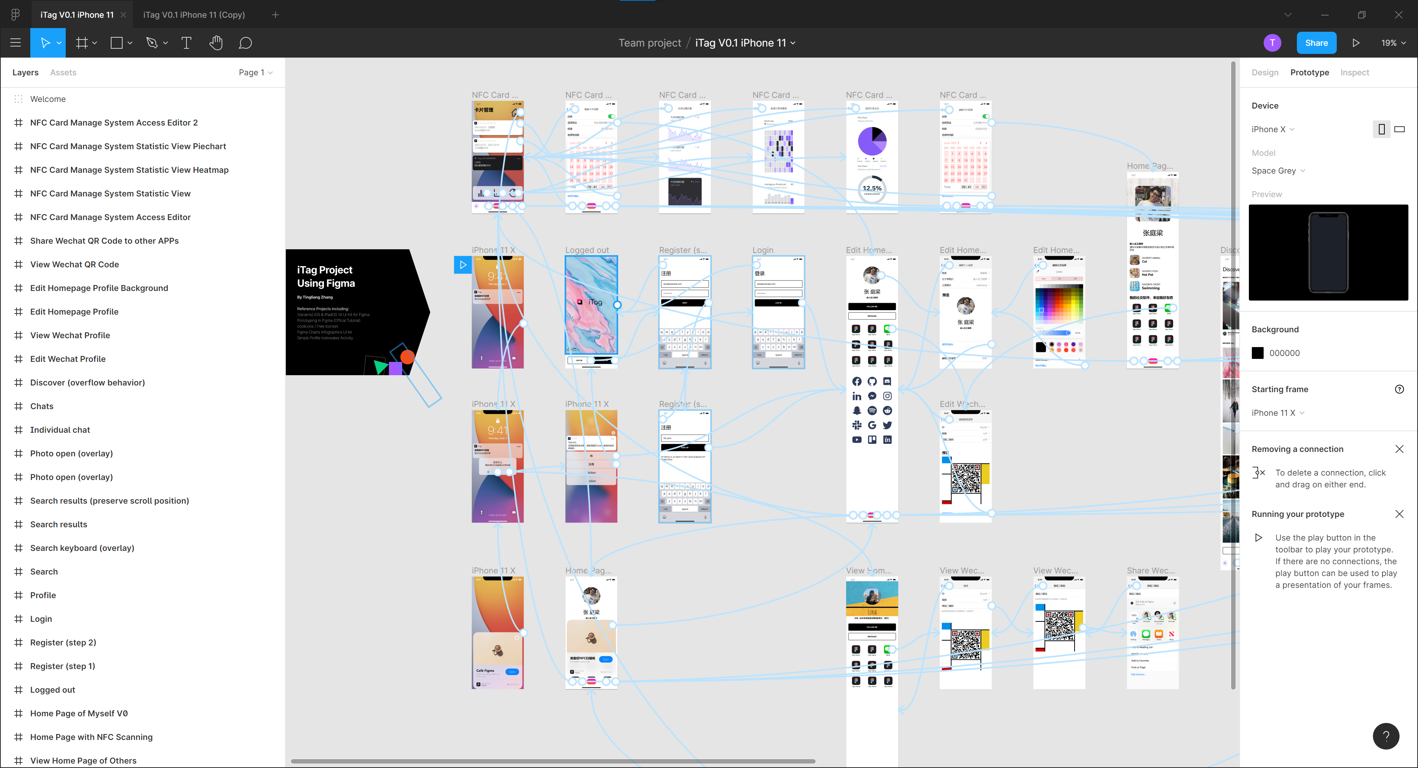
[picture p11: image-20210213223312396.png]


### 20210214交互流程会议纪要

新用户引导流程——姓名\默认有个照片（可以是灰色固定也可以是random版的）

新加小预设，比如添加新的社交软件： 选择社交软件 => 微信选择预设或新建预设

卡片管理-不同预设，包括工作用、社交用等区别，以及可以禁用和启用某卡片

预设模块化

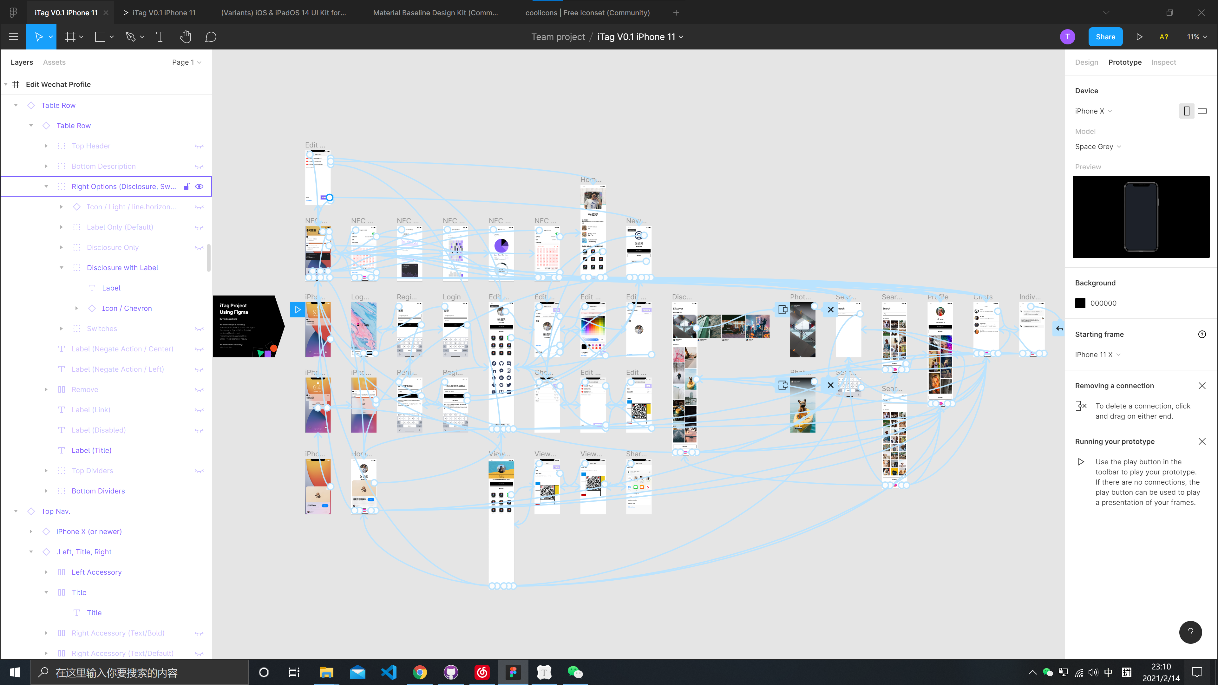
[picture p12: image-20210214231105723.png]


## Nginx

https://nginx.org/

```sh
# 安装Nginx
sudo apt-get install nginx
```

[Beginner’s Guide](https://nginx.org/en/docs/beginners_guide.html)

Ubuntu的配置文件在 `/etc/nginx/nginx.conf`，默认网页在`/var/www/html/`下面，可以修改配置文件改默认网页目录

https://blog.csdn.net/a15005784320/article/details/103437776

主页放在`/home/admin/girlsday2021/WebsiteHome/`

Blog模块放在`/home/admin/girlsday2021/Blog/_site/index.html`可以直接用`bundle exec jekyll build`生成。其实最好用`bundle exec jekyll server`启动服务，之后用转发 http://127.0.0.1:4000/blog/

为了后台运行，使用`bundle exec jekyll server --detach`启动服务：

```sh
Server detached with pid '49146'. Run `pkill -f jekyll' or `kill -9 49146' to stop the server.
```

> To apply the new configuration, start nginx if it is not yet started or send the `reload` signal to the nginx’s master process, by executing:
>
> > ```
> > nginx -s reload
> > ```
>
> > In case something does not work as expected, you may try to find out the reason in `access.log` and `error.log` files in the directory `/usr/local/nginx/logs` or `/var/log/nginx`.

目前的配置文件参考`/etc/nginx/nginx.conf`

```python
user www-data;
worker_processes auto;
pid /run/nginx.pid;
include /etc/nginx/modules-enabled/*.conf;

events {
	worker_connections 768;
	# multi_accept on;
}

http {

	##
	# Basic Settings
	##

	sendfile on;
	tcp_nopush on;
	tcp_nodelay on;
	keepalive_timeout 65;
	types_hash_max_size 2048;
	# server_tokens off;

	# server_names_hash_bucket_size 64;
	# server_name_in_redirect off;

	include /etc/nginx/mime.types;
	default_type application/octet-stream;

	##
	# SSL Settings
	##

	ssl_protocols TLSv1 TLSv1.1 TLSv1.2 TLSv1.3; # Dropping SSLv3, ref: POODLE
	ssl_prefer_server_ciphers on;

	##
	# Logging Settings
	##

	access_log /var/log/nginx/access.log;
	error_log /var/log/nginx/error.log;

	##
	# Gzip Settings
	##

	gzip on;

	# gzip_vary on;
	# gzip_proxied any;
	# gzip_comp_level 6;
	# gzip_buffers 16 8k;
	# gzip_http_version 1.1;
	# gzip_types text/plain text/css application/json application/javascript text/xml application/xml application/xml+rss text/javascript;

	##
	# Virtual Host Configs
	##

	include /etc/nginx/conf.d/*.conf;
	include /etc/nginx/sites-enabled/*;
  
  #以下属性中，以ssl开头的属性表示与证书配置有关。
  server {
      listen 443 ssl;
      #配置HTTPS的默认访问端口为443。
      #如果未在此处配置HTTPS的默认访问端口，可能会造成Nginx无法启动。
      #如果您使用Nginx 1.15.0及以上版本，请使用listen 443 ssl代替listen 443和ssl on。
      server_name interact.cool; #需要将yourdomain.com替换成证书绑定的域名。
      root html;
      index index.html index.htm;
      ssl_certificate cert/5265802_interact.cool.pem;  #需要将cert-file-name.pem替换成已上传的证书文件的名称。
      ssl_certificate_key cert/5265802_interact.cool.key; #需要将cert-file-name.key替换成已上传的证书密钥文件的名称。
      ssl_session_timeout 5m;
      ssl_ciphers ECDHE-RSA-AES128-GCM-SHA256:ECDHE:ECDH:AES:HIGH:!NULL:!aNULL:!MD5:!ADH:!RC4;
      #表示使用的加密套件的类型。
      ssl_protocols TLSv1 TLSv1.1 TLSv1.2; #表示使用的TLS协议的类型。
      ssl_prefer_server_ciphers on;
      location / {
          root /home/admin/girlsday2021/WebsiteHome/;
          # root html;  #站点目录。
          # index index.html index.htm;
      }
      location /blog/ {
          #root /home/admin/girlsday2021/Blog/_site/;  #博客目录。但是没有修饰
          proxy_pass http://127.0.0.1:4000/blog/;
      }
  }
  
  # 设置HTTP请求自动跳转HTTPS
  server {
    listen 80;
    server_name interact.cool; #需要将yourdomain.com替换成证书绑定的域名。
    rewrite ^(.*)$ https://$host$1; #将所有HTTP请求通过rewrite指令重定向到HTTPS。
    location / {
        index index.html index.htm;
    }
  }
}

#mail {
#	# See sample authentication script at:
#	# http://wiki.nginx.org/ImapAuthenticateWithApachePhpScript
# 
#	# auth_http localhost/auth.php;
#	# pop3_capabilities "TOP" "USER";
#	# imap_capabilities "IMAP4rev1" "UIDPLUS";
# 
#	server {
#		listen     localhost:110;
#		protocol   pop3;
#		proxy      on;
#	}
# 
#	server {
#		listen     localhost:143;
#		protocol   imap;
#		proxy      on;
#	}
#}

```

## SSL证书

[申请免费DV证书](https://help.aliyun.com/document_detail/156645.html)

[在Nginx（或Tengine）服务器上安装证书](https://help.aliyun.com/document_detail/98728.html?spm=a2c4g.11186623.6.631.15b783b5Dhx56s)

阿里云的主机是独立服务器，请参见[步骤2：（可选）在Nginx独立服务器上安装证书](https://help.aliyun.com/document_detail/98728.html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)

在Nginx安装目录（/etc/nginx/）下创建一个用于存放证书的目录（命名为cert）	

将本地证书文件和密钥文件上传到Nginx服务器的证书目录，即.key和.pem文件

编辑Nginx配置文件（nginx.conf），修改与证书相关的配置内容。

在配置文件中定位到HTTP协议代码片段（`http{}`），并在HTTP协议代码里面添加以下server配置（如果server配置已存在，按照以下注释内容修改相应配置即可）。

```python
  #以下属性中，以ssl开头的属性表示与证书配置有关。
  server {
      listen 443 ssl;
      #配置HTTPS的默认访问端口为443。
      #如果未在此处配置HTTPS的默认访问端口，可能会造成Nginx无法启动。
      #如果您使用Nginx 1.15.0及以上版本，请使用listen 443 ssl代替listen 443和ssl on。
      server_name interact.cool; #需要将yourdomain.com替换成证书绑定的域名。
      root html;
      index index.html index.htm;
      ssl_certificate cert/5265802_interact.cool.pem;  #需要将cert-file-name.pem替换成已上传的证书文件的名称。
      ssl_certificate_key cert/5265802_interact.cool.key; #需要将cert-file-name.key替换成已上传的证书密钥文件的名称。
      ssl_session_timeout 5m;
      ssl_ciphers ECDHE-RSA-AES128-GCM-SHA256:ECDHE:ECDH:AES:HIGH:!NULL:!aNULL:!MD5:!ADH:!RC4;
      #表示使用的加密套件的类型。
      ssl_protocols TLSv1 TLSv1.1 TLSv1.2; #表示使用的TLS协议的类型。
      ssl_prefer_server_ciphers on;
      location / {
          root html;  #站点目录。
          index index.html index.htm;
      }
  }
  
  # 设置HTTP请求自动跳转HTTPS
  server {
    listen 80;
    server_name yourdomain.com; #需要将yourdomain.com替换成证书绑定的域名。
    rewrite ^(.*)$ https://$host$1; #将所有HTTP请求通过rewrite指令重定向到HTTPS。
    location / {
        index index.html index.htm;
    }
  }
```

保存后重启Nginx服务

Changes made in the configuration file will not be applied until the command to reload configuration is sent to nginx or it is restarted. To reload configuration, execute:

```sh
nginx -s reload
```

## Jekyll on Ubuntu

首先安装[Jekyll](https://jekyllrb.com/)

> Install Ruby and other [prerequisites](https://jekyllrb.com/docs/installation/#requirements):
>
> ```sh
> sudo apt-get install ruby-full build-essential
> ```
>
> Avoid installing RubyGems packages (called gems) as the root user. Instead, set up a gem installation directory for your user account. The following commands will add environment variables to your `~/.bashrc` file to configure the gem installation path:
>
> ```sh
> echo '# Install Ruby Gems to ~/gems' >> ~/.bashrc
> echo 'export GEM_HOME="$HOME/gems"' >> ~/.bashrc
> echo 'export PATH="$HOME/gems/bin:$PATH"' >> ~/.bashrc
> source ~/.bashrc
> ```
>
> Finally, install Jekyll and Bundler:
>
> ```sh
> gem install jekyll bundler
> ```
>
> That’s it! You’re ready to start using Jekyll.

一定注意不要用root账号直接配置bashrc和gem install，不然会报错

[Minimal Mistakes Jekyll theme](https://mmistakes.github.io/minimal-mistakes/)

直接clone Github repo并且用他自带的`_config.yml`和`Gemfile`

```sh
sudo apt-get install git
git clone https://github.com/mmistakes/minimal-mistakes.git
bundle
bundle exec jekyll server
```

## Jekyll On Windows

https://jekyllrb.com/docs/installation/windows/

Installation via RubyInstaller 首先去 https://rubyinstaller.org/downloads/ 下载  [Ruby+Devkit 2.7.2-1 (x64)](https://github.com/oneclick/rubyinstaller2/releases/download/RubyInstaller-2.7.2-1/rubyinstaller-devkit-2.7.2-1-x64.exe)

> 1. Download and install a **Ruby+Devkit** version from [RubyInstaller Downloads](https://rubyinstaller.org/downloads/). Use default options for installation.
>
> 2. Run the `ridk install` step on the last stage of the installation wizard. This is needed for installing gems with native extensions. You can find additional information regarding this in the [RubyInstaller Documentation](https://github.com/oneclick/rubyinstaller2#using-the-installer-on-a-target-system)
>
> 3. Open a new command prompt window from the start menu, so that changes to the `PATH` environment variable becomes effective. Install Jekyll and Bundler using `gem install jekyll bundler`
>
> 4. Check if Jekyll has been installed properly: `jekyll -v`
>
> You may receive an error when checking if Jekyll has been installed properly. Reboot your system and run `jekyll -v` again. If the error persists, please open a [RubyInstaller issue](https://github.com/oneclick/rubyinstaller2/issues/new).

有报错，安不上Jekyll，https://github.com/jekyll/jekyll/issues/7000#issuecomment-617482425 但是默认就是没空格的啊老哥

> Ruby 2.7.x worked for me after I moved the install location to a folder without spaces (D:\Program Files\Ruby -> D:\Ruby) and updated the relevant PATH

https://segmentfault.com/q/1010000013418668/a-1020000013529937

**我选择放弃Windows，直接虚拟机测试吧qwq**

之后在VS Code 路径下 Powershell里面运行即可启动服务器

```sh
sudo apt-get install git
git clone https://github.com/mmistakes/minimal-mistakes.git
bundle
bundle exec jekyll server
```

## Minimal Mistakes 部署和修改

如上按步骤在Linux系统中安装好Jekyll之后，测试编译一下Test正常与否

直接在git上下载整个Repo：https://github.com/mmistakes/minimal-mistakes

可以选择删掉不必要的内容，比如`/docs`和`/test`文件夹

> Remove the Unnecessary[Permalink](https://mmistakes.github.io/minimal-mistakes/docs/quick-start-guide/#remove-the-unnecessary)
>
> If you forked or downloaded the `minimal-mistakes-jekyll` repo you can safely remove the following folders and files:
>
> - `.editorconfig`
> - `.gitattributes`
> - `.github`
> - `/docs`
> - `/test`
> - `CHANGELOG.md`
> - `minimal-mistakes-jekyll.gemspec`
> - `README.md`
> - `screenshot-layouts.png`
> - `screenshot.png`

开始按照[Configuration](https://mmistakes.github.io/minimal-mistakes/docs/configuration/)的详细说明修改`_config.yml`文件，做网站全局的设定，之后可以尽可能少的改这个文件。

新建一些文件夹，放Post的Readme文件，并在`_config.yml`文件中设置

Comment应用选择开源的[staticman](https://staticman.net/)或者[Facebook](https://developers.facebook.com/docs/plugins/comments)，放弃，太困难了。

部署到网易云运行bundle的时候如果遇到如下权限错误：

There was an error while trying to write to`/home/admin/girlsday2021/Blog/Gemfile.lock`. It is likely that you need to
grant write permissions for that path.

可以新建一个Gemfile.lock文件并且把它权限设置为777即可。

之后遇到的`.jekyll-cache (Errno::EACCES)`和`_site`文件夹的权限也同理，直接新建文件夹并给777权限即可。

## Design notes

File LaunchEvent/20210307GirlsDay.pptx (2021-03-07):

## Girlsday Special Event

## 祝小仙女们女生节快乐！

## Girlsday Special Event

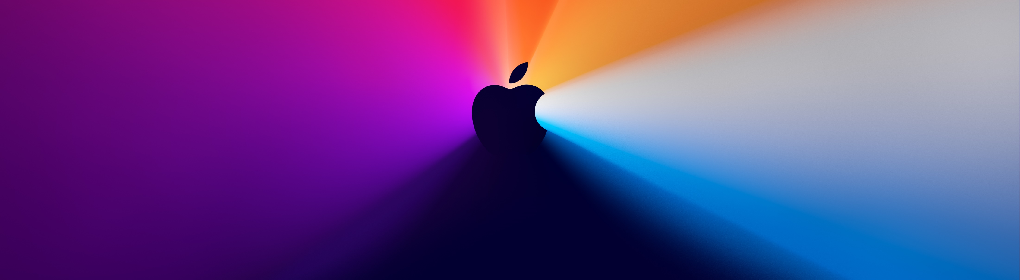
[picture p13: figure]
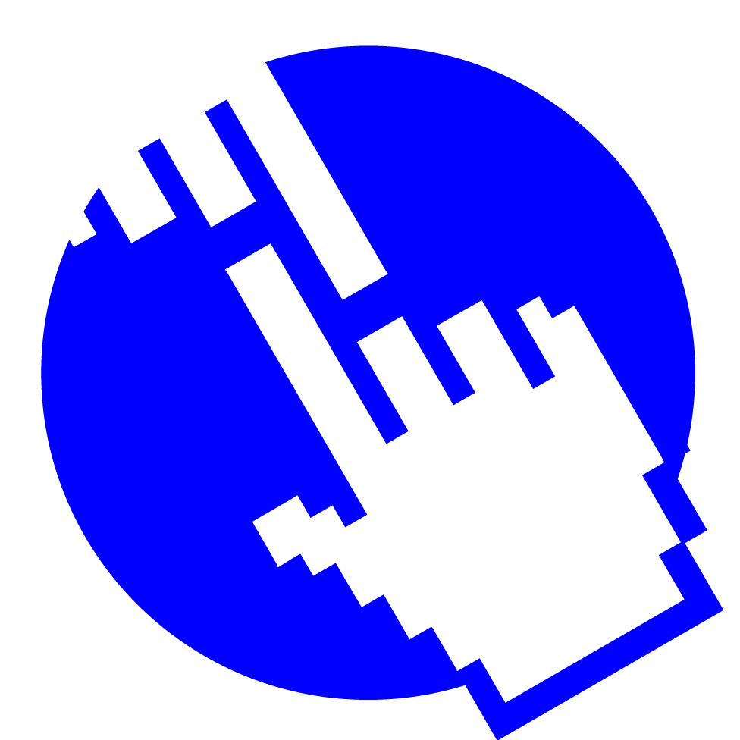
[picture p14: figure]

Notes: Opps, 放错PPT了，这个是下周的PPT，首先给大家道歉，由于代工厂产能问题，本来2天的工期硬是拖了一周，今天下午才发货，所以我们的女生节礼物得推迟下发布，大家可以期待下下周的女生节礼物特别活动，我对不起大家。

## 一夜狼人、UNO、扑克

## VR、玩PS4、玩电脑游戏、Switch

## 看电影

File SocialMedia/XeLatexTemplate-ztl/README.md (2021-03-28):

# XeLatexTemplate-ztl
我个人的XeLetex模板

使用如下命令

```
latexmk -xelatex --shell-escape ThesisTemplate.tex
```

好用的工具：  https://mathpix.com/

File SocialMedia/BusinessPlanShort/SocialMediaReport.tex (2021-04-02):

% Compile with latex+dvipdfmx, pdflatex, xelatex or lualatex
% XeLaTeX is recommanded

\documentclass[UTF8]{ctexart}
\usepackage[T1]{fontenc}
\usepackage[colorlinks,
linkcolor=red,
anchorcolor=blue,
citecolor=green
]{hyperref}
\usepackage{tcolorbox}
\tcbuselibrary{breakable}
% 如果框内的内容多于一页需要设置自动断页[breakable]但是要注意先使用breakable库

\usepackage{graphicx} % support the \includegraphics command and options
\graphicspath {{fig/}} % 设置图片目录
\usepackage{subfigure} %插入多图时用子图显示的宏包

\title{iTag-从线下开始的微微熟社交生态}
\author{张庭梁}
\date{\today}

\begin{document}

\maketitle

\section{摘要}

iTag是一套从线下开始的微微熟社交生态，希望为用户提供一个安全自然的扩展社交圈子的方式。iTag包括三个部分：一个可定制的NFC电子名片和卡包、一款可持续发展的兴趣交友软件、一款有趣的AR游戏平台。我们创造性的提出了使用NFC电子名片碰一碰加好友的社交方式，一次性分享预设的多样化社交信息。旨在打破陌生人社交软件社交资本单一和不安全不自然的困境，为用户提供多角度展示自己的机会。我们制作了多种不同形态、功能、定位的NFC Tag。同时还有一款类似Ingress的虚拟实境游戏，为这一过程提供更多的趣味性。

\section{现有产品研究}
本章从探探的发展出发，延伸探讨广义上的陌生人社交软件的发展和存在的问题，最后探讨现有软件的问题成因和可能的解决方案。

\subsection{陌生人社交定义}

\begin{tcolorbox}
    互联网语境下的社交是用户间的信息交流和互动，最典型的社交产品是早期的微信和QQ，但现在微信和QQ已不仅仅是社交产品，更是生活方式。

    在社交的分类中，按用户关系距离来分，可分为熟人社交（QQ、微信）和陌生人社交（探探、陌陌、Soul、她说等婚恋交友软件）。

    从社交的定义可以得到陌生人社交指陌生用户间的信息交流和互动，社交整体过程归纳总结起来就是以下两点：关系的建立+关系的沉淀（维系和发展）。而陌生人社交的重点会更偏关系的建立，特点是：它是对现实的补充，具有很大的虚拟性。\cite{StrangerDefine}
\end{tcolorbox}

其实建立关系只是第一步，更重要的是关系的沉淀。我们希望开发的是一款提供相识机会，但更注重引导关系发展的社交应用。

\subsection{陌生人社交软件发展-以探探为例}
本章以探探为例，简单梳理陌生人社交软件发展。

探探是中国大陆一款基于地理位置的社交应用程序，由王宇和潘滢创立，于2014年上线，其目标人群定位在20岁至26岁的用户。使用上，探探被认为模仿了同类应用程序Tinder，双方只有互相喜欢，才能开始聊天,因此得名“约炮神器”。探探亦上线了“擦肩而过”和“匿名表白”功能，并做了一系列尝试来规范用户行为。探探推出后在85后到90后的用户群中较为热门，但其“匿名表白”功能曾引发侵权争议，其安全性也遭到过质疑。

2018年2月23日陌陌斥资7.71亿美元收购探探科技（北京）有限公司。交易成功后，探探团队继续独立运营产品和品牌。\cite{MoMoHistory}

探探被认为模仿了美国同类应用程序Tinder，其主要基于地理位置和大数据平台，向用户提供个性化推荐。其在交互方式上采用了简单的动作设置：如果喜欢某一对象，就往右滑，不喜欢则往左滑。之后，系统自动进行配对，如果双方互相喜欢，系统会明确告知给两个用户，双方才能开始聊天，否则彼此不会收到任何消息。

此外，探探亦上线了“擦肩而过”和“匿名表白”功能，“擦肩而过”是探探开发的一项基于GPS系统的服务，如果有喜欢的人从附近经过，探探会进行提示并显示距离。“匿名表白”是探探基于手机通信录的一种匿名表达爱慕之情的功能，使用该功能，用户可以对通信录的好友匿名表白，并邀请该位好友加入成为探探用户。在使用“匿名表白”功能时，如果被表白的一方尚未注册探探账户，系统会自动发送暗恋短信到被表白一方的手机上，此举引发了侵权争议，存在违法嫌疑。

信息安全性方面，企业家拉里·萨利布拉使用Xcode对软件进行逆向工程时发现该软件缺乏加密措施，因此，稍有技术的黑客即可获取用户的用户名、密码、电话号码，甚至对话。

2019年06月28日，国家网信办发布，其会同有关部门，针对网络音频乱象启动专项整治行动。根据群众举报线索，经核查取证，首批依法依规对吱呀、Soul、语玩、一说FM等26款传播历史虚无主义、淫秽色情内容的违法违规音频平台，分别采取了约谈、下架、关停服务等阶梯处罚，对音频行业进行全面集中整治。有关负责人表示，此次专项整治不仅要坚决有效遏制行业乱象，也要积极规范行业发展，促进网络生态持续向好。\cite{Audio}

根据《关于开展App违法违规收集使用个人信息专项治理的公告》，受中央网信办、工信部、公安部、市场监管总局委托，全国信息安全标准化技术委员会、中国消费者协会、中国互联网协会、中国网络空间安全协会成立App专项治理工作组，对用户数量大、与民众生活密切相关的App隐私政策和个人信息收集使用情况进行评估。2019年7月12日，包括探探等在内的30款App因违反《网络安全法》关于收集使用个人信息的相关规定，被通报30日内完成整改。\cite{Privacy}

探探部分用户协议摘录如下：

\begin{tcolorbox}
    3.1 为了能使用本服务，您需要注册探探帐号，应当使用手机号码绑定注册，请用户使用尚未与“探探”帐号绑定的手机号码，以及未被探探文化封禁的手机号码注册“探探”帐号。根据法律法规的要求，探探文化可以根据用户需求或产品需要对帐号注册和绑定的方式进行变更，您应在法律法规的要求下予以配合。

    3.2 “探探”系基于地理位置的移动社交产品，用户注册时应当授权探探文化公开及使用其地理位置信息方可成功注册“探探”帐号。故用户完成注册即表明用户同意探探文化提取、公开及使用用户的地理位置信息。

    3.3 鉴于探探帐号的注册方式，且为了保护您账号的安全，您同意探探文化在注册时使用您提供的手机号码及/或自动提取您的手机号码及您的手机设备识别码等信息用于注册。同时如果您可以选择开启使用某些功能，您同意探探文化取得您的手机通讯录信息以使这些功能可以实现。

    3.4 在用户注册及使用本服务时，探探文化需要搜集能识别用户身份的个人信息以便探探文化可以在必要时联系用户，或为用户提供更好的使用体验。探探文化搜集的信息包括但不限于用户的姓名、性别、年龄、出生日期、身份证号、地址、学校情况、公司情况、所属行业、兴趣爱好、常出没的地方、个人说明；探探文化同意对这些信息的使用将受限于个人隐私信息相关法律和探探隐私政策的约束。\cite{MoMoAgreement}
\end{tcolorbox}

其实和国内很多软件一样，在安装时索取了远超自己APP需要的权限，当然这和隐私保护的乱象有关，同样的应用在苹果商店就老实很多，比安卓商店索取的权限要少很多。

\subsection{陌生人社交平台分类}
我将陌生人社交平台分为三类：LBS(Location Based Services,基于位置的服务)社交应用、婚恋市场、兴趣交友。

LBS社交包括Tinder、探探和陌陌、微信附近的人等，主打短期关系和荷尔蒙社交，颜值基本上就是其中唯一的社交资本。

婚恋市场主要玩家为世纪佳缘、百合网，社交资本稍多元，包括收入、职业、户口等，但婚恋市场更加功利，用户普遍为30-40岁，有更高的收入，追求相亲的效率，VIP服务收费较高，从几万到几十万不等。

兴趣交友类包括Soul、Summer等，本意是兴趣交友，社交资本更为多元，有助于寻找到共同话题。Summer主打高校市场：分享校园欢乐日常、大学生专属身份认证、面向全国高校开放、答题交友。Soul则主打匿名性的轻松感，不用上传头像、视频露脸或者实名。但是这些应用经过一年多的发展，鱼龙混杂的用户涌入，渐渐和探探等同质化。

Tinder的核心是左滑跳过右滑Like的配对机制，只有双方互相Like之后才能开始进一步聊天，后续Tinder还推出了和Facebook Instagram等社交软件的联动，付费版本可以Like更多的人甚至在Like之前看这个人有没有Like你，在2020年因为安全方面的考量，Tinder也推出了一键SOS报警功能。\cite{WikiTinderFeatures}
在信息安全方面，Tinder也曾爆出不少漏洞，每次打开和进行匹配的精确地理位置甚至聊天视频内容的泄露漏洞，以及卫报记者单人长达800页的用户数据历史，包括时间、地点、个人喜好、受众人群、每个照片浏览时间。一旦这些十分隐私的详尽数据泄露，后果不堪设想。\cite{WikiTinderFeatures}

探探应用中存在大量虚假信息、骗子、甚至聊天机器人。打擦边球构筑的不健康的商业模式。用户粘性有限，商业潜力有限。软件缺乏加密措施，因此，稍有技术的黑客即可获取用户的用户名、密码、电话号码，甚至对话。\cite{WikiTantan}
陌陌类应用其实依靠的是打擦边球构筑的不健康的商业模式，用户粘性和商业潜力有限。其中大量虚假信息、骗子、甚至聊天机器人，进一步增加了用户对其不信任感。\cite{MoMoWhy}

以世纪佳缘、百合网等交友软件为代表的婚恋市场婚恋市场则更加功利，用户普遍为30-40岁，有更高的收入，追求相亲的效率。
但是婚恋网站上面信息不实，婚介和外包由于资源不足合伙骗人，甚至还有金融理财诈骗、传销组织奔现等陷阱，这些因素让婚恋市场的信誉不断受损。\cite{CheatTheLiving}
知乎上也有大量的关于平台或代理商请的托恶意骗钱行为的例子，比如\url{https://www.zhihu.com/question/37751869}
婚恋平台上存在大量不实个人信息但是过于严格的筛查审核机制会劝退很多用户，用户不愿意一次性上传过多真实个人信息和照片，如学位证身份证等。\cite{WikiJiayuan}
盈利主要靠VIP或一对一红娘收费，收费普遍极高，条件差距大的收费更高，甚至于几十万的天价中介费。盈利方式不健康。

SOUL这一兴趣交友网站开始的模式很吸引人，类似树洞的匿名，个人信息的自由，和探探等yp应用区分开了。但是没有树洞的自由，屏蔽词恶心用户。匿名下的乱象丛生令这个平台鱼龙混杂，广场变为寻求满足感的匿名微博式平台。\cite{Soul}
Summer类似Soul但是主打高校市场，核心功能包括分享校园欢乐日常、大学生专属身份认证、面向全国高校开放、答题交友趣味刷题。但近些年发展也不算很快。

\section{产品立意}
通过上文的讨论，我们总结了一下目前现有产品的一些痛点如下：

\begin{itemize}
    \item 信息安全问题：LBS应用普遍存在的问题，海量个人信息（特别是位置信息）泄露的可能性
    \item 用户人身安全问题
    \item 荷尔蒙导向应用的不可持续性和用户留存率低
    \item 很多人不愿意不希望自己的真实照片被公开，被挑选。
    \item 关键词审核过于严格，实名信息审查过于敷衍了事
    \item 大量虚假用户和骗子，平台鱼龙混杂
    \item 平台收费过高，线下分店通过和代理商和托儿一起蒙骗客户盈利
    \item 流量中心化：少数用户获得多数资源——社交资本太单一，基本就只以颜值为主
\end{itemize}

为了避开这些问题，我们的产品要做到如下要求：

\begin{itemize}
    \item 不再要求用户提供位置权限
    \item 用户不必向公网公布个人信息，也不必给平台提供任何信息
    \item 提倡长期关系，而非荷尔蒙驱动关系
    \item 多元的社交资本，避免流量中心化
    \item 安全的兴趣广场
    \item 可持续发展，高的用户留存度
    \item 全免费平台，无广告环境
\end{itemize}

我们的iTag是一套从线下开始的微微熟社交生态，iTag具有以下亮点：

\begin{itemize}
    \item NFC卡片加持，只有刷卡才能加好友哦
    \item 自定义主页预设，可当场选择想给TA看的信息，真正做到千人千面
    \item 和不同社交软件联动，在其他软件里面展示自己不同角度的闪光点吧
    \item 组织线下主题兴趣小聚，给有共同兴趣话题的人提供机会
    \item 定制联名款卡片，你就是人群中最亮的崽
    \item 好友Follow系统，查看Follower共享给你的TA的信息吧~
    \item 免费提供服务，无广告
    \item 去中心化区块链加密存储，保证用户隐私安全。
    \item 有趣的虚拟现实游戏，拓宽推广渠道并能增强用户粘性。
\end{itemize}

类似于但又不完全是NFC电子名片：比如我在聚会中、上课时甚至路上，想要和旁边的人建立社交关系，可以拿出自己的NFC卡片，让对方用手机碰一碰。NFC Tag里面存储的是一个带有加密后UID的网址，对方手机会打开我提前选择好的预设页面，上面有我的简单介绍和一些社交软件信息，比如微信、B站、Ins等。对方除了可以加微信好友和关注我外，还可以选择加入这一生态，注册并下载我们的APP，follow邀请者。

我们想颠覆的是微信的线上熟人社交垄断，和探探等陌生人社交软件的不自然不安全。NFC能有效避免需要双方打开微信扫一扫和二维码这一过程的冗长和尴尬。而相较于社交资本单一、几乎以颜值为唯一标准的陌生人社交软件，我们提供给用户多角度展示自己的机会。

内测阶段，我们和线下社群合作，推广我们的产品。在社团小聚、百团等场景扩展我们的业务。

同时我们会开发一款有趣的AR游戏，借鉴任天堂Ingress的占点模式，每一个玩家都是一个portal，随着游戏的推进会有异世界剧情逐渐解锁。以此鼓励大家走出自己的社交小圈子，去结识更多的朋友。

iTag包括三个部分：一个可定制的NFC电子名片和卡包、一款可持续发展的兴趣交友软件、一款有趣的AR游戏平台。

以下分硬件、软件、游戏三个部分展开叙述

\section{硬件}

目前硬件方面，经过五次迭代、仿真和测试，女生节礼物内测卡片使用的PCB基板，以及定制化的丝印和铜层设计。分为两种不同的尺寸：ISO 7813 规范 ID-1 85.60×53.98毫米 银行卡尺寸电子名片，和30x30cm的钥匙链设计。

我们通过计算线圈自感来设计PCB上的铜层线圈尺寸。我们也编写了自动生成NFC线圈的代码，给定线圈尺寸、线宽、线距等参数就可以生成相应线圈，如图~\ref{NFCAntennaGenerator}所示。

\begin{figure}[htbp]
    \centering
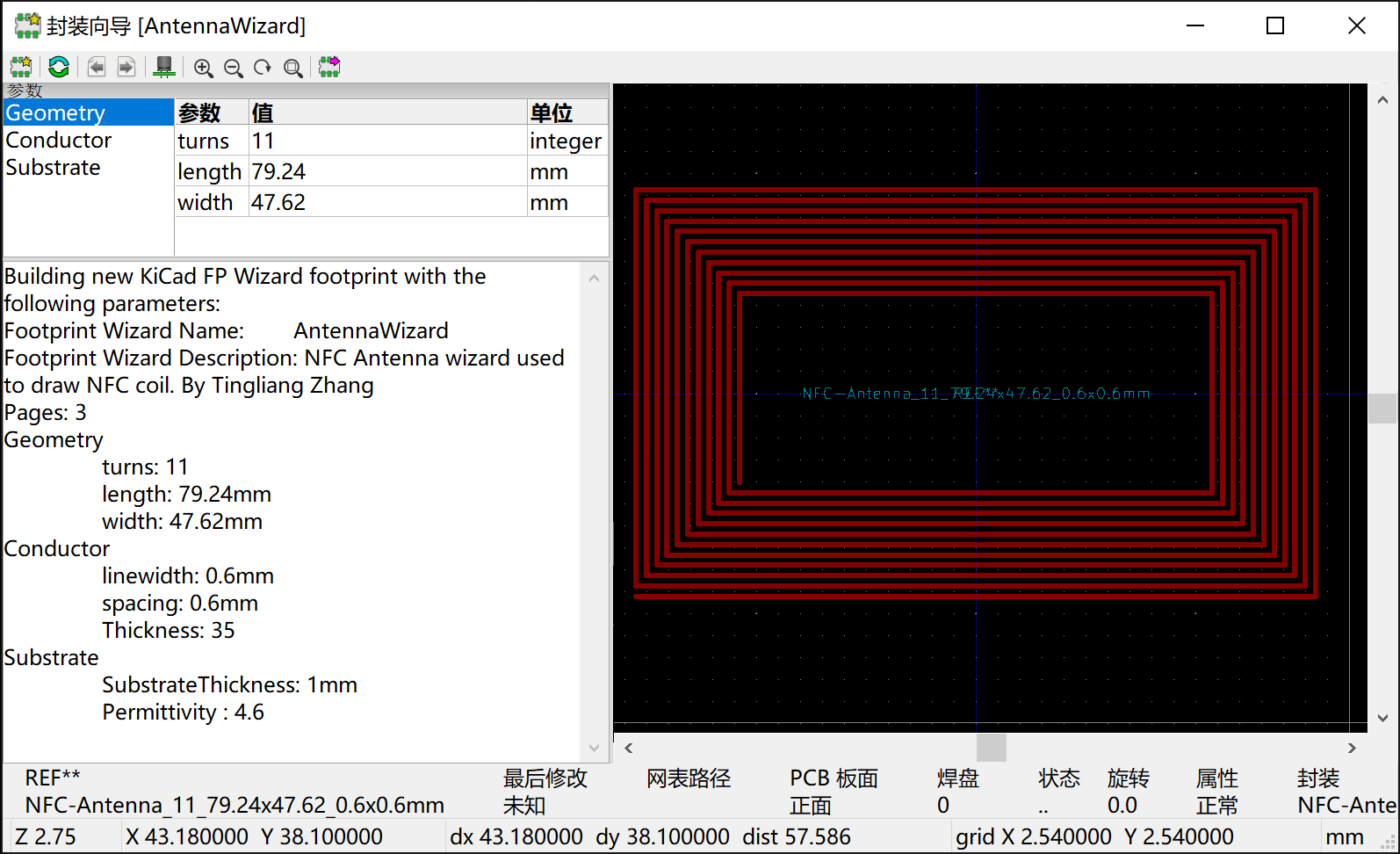
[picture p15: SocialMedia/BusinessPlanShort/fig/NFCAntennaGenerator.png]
    
    \caption{NFC Antenna Generator} 
    \label{NFCAntennaGenerator}
\end{figure}

PCB打样完成后，其上只需要SMT一片ST24 NFC Tag即可使用。

打样成本2元每片，芯片则是2元每个。如果是钥匙链设计，现在的小批量生产，可以拼版为每片9个的100x100mm V-Cut板，进一步降低小批量定制化生产的成本到0.2元每片。另外如果采用国产芯片，芯片成本能低至0.3元每片。

初版iTag于2021/03/07女生节作为班级女生的礼物预先发布，正式deliver和发布在03/14 Pi节。

除此之外，我们还有钥匙扣、名片、Cheatsheet等形式的卡片，如图~\ref{Card}所示。值得一提的是，手机壳或手机壳贴纸，以及Magsafe卡包，是很自然的产品形式。

\begin{figure}[htbp]
    \centering
    \subfigure[]
    {
         \begin{minipage}[b]{0.3\linewidth}
            \centering
            
        \end{minipage}
    }
    \subfigure[]
    {
        \begin{minipage}[b]{0.3\linewidth}
            \centering
            
        \end{minipage}
    }
    \subfigure[]
    {
         \begin{minipage}[b]{0.3\linewidth}
            \centering
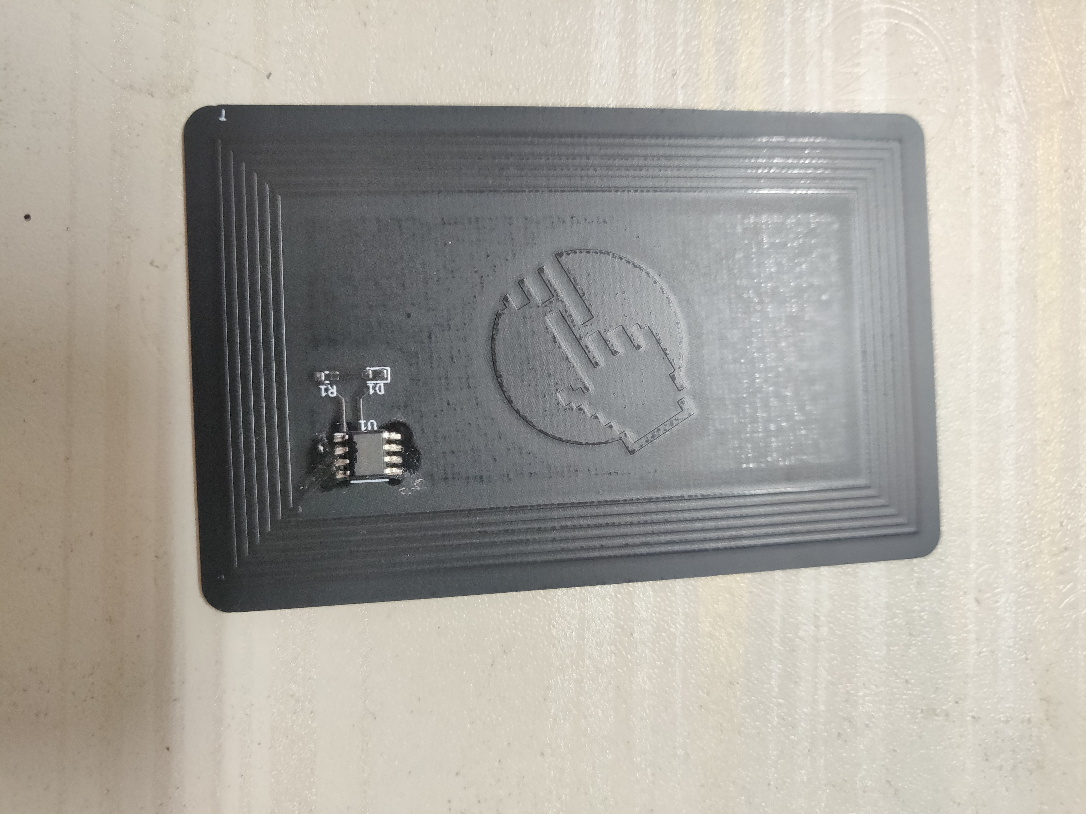
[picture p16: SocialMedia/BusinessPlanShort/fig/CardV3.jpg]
            
        \end{minipage}
    }
    \caption{不同形态的卡片样例}
    \label{Card}
\end{figure}

未来我们为了进一步降低成本，将使用国产白卡，即将NFC线圈和芯片封装到塑料或其他材质卡片中的成品。采购价格能低于0.1元每片。在上面可以打印统一的或者个性化的图案。

未来我们会推出类似Fuze的智能款卡片，带有电池、处理器、墨水屏和触摸按键，实现一张卡可切换多张卡，支持录入门卡、会员卡、储值卡等卡片，并且可以随时切换卡片。你的下一个卡包，何必是卡包。

游戏玩家专属卡和联名款卡片也将是未来的一个方向。

\section{软件}

目前内测阶段我们使用的是网页版，使用VUE.js框架编写，MongoDB数据库存储用户数据，Nginx轻量级Web服务器，阿里云轻量应用服务器转发，本地40线程16TB高性能PVE虚拟化服务器提供服务。顶级域名(interact.cool)已在中国大陆ICP备案，以提供更快更稳定的DNS解析。

UI界面和UX交互流程由用户体验设计师使用Figma设计，遵循自然交互原则，为用户提供自然的交互体验，软件如图~\ref{iTagAPP}所示。

\begin{figure}[htbp]
    \centering
    
    \caption{iTag软件} 
    \label{iTagAPP}
\end{figure}

当用户使用手机扫描NFC标签并读取到里面的网址时，安卓系统会弹出提示，选择对此网站的操作，选择用浏览器打开并勾选总是执行此操作，之后会自动在浏览器中打开链接；苹果系统则会弹出提示，点击即可用默认浏览器打开。如果安装了APP，会直接打开APP并将网址内的加密UID传递给APP。

当识别到是一个未绑定的卡片，会跳转到用户登录和注册页面，如果之前登录过，会直接使用浏览器中的cookie自动登录。这张卡片会绑定到你的账号里，可以在卡片管理页面设置卡片预设和权限以及到期日。如图~\ref{Login}所示。

\begin{figure}[htbp]
    \centering
    \subfigure[]
    {
         \begin{minipage}[b]{.3\linewidth}
            \centering
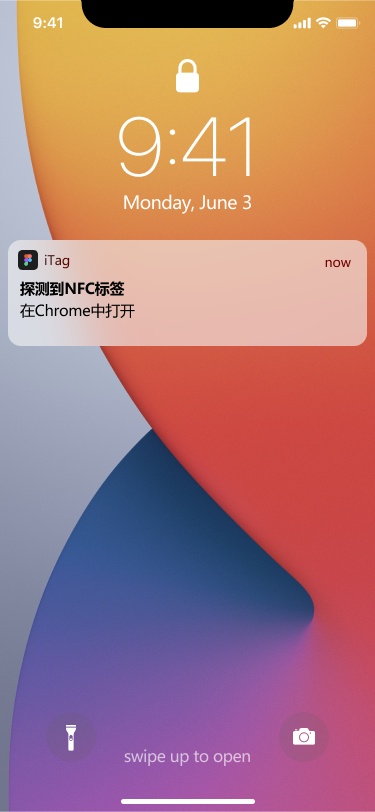
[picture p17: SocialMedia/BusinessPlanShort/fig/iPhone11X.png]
            
        \end{minipage}
    }
    \subfigure[]
    {
        \begin{minipage}[b]{.3\linewidth}
            \centering
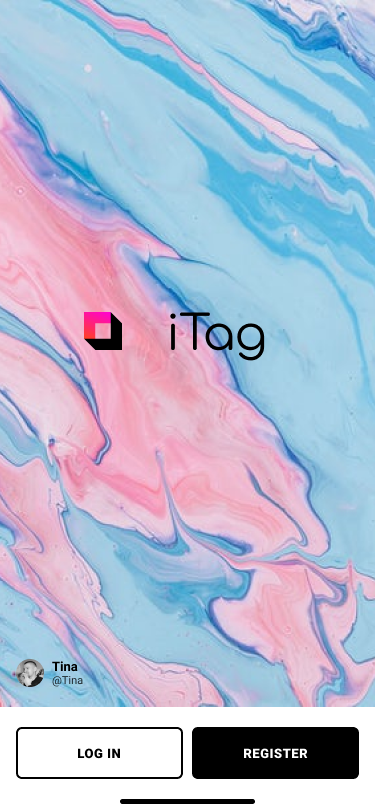
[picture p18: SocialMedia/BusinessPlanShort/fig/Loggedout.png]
            
        \end{minipage}
    }
    \subfigure[]
    {
         \begin{minipage}[b]{.3\linewidth}
            \centering
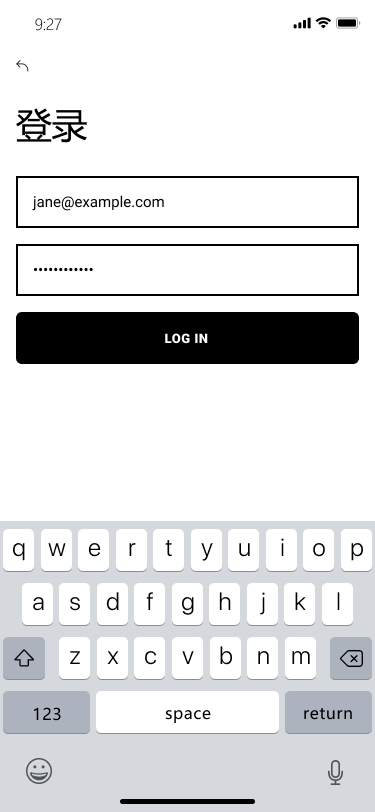
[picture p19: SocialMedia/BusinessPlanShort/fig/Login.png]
            
        \end{minipage}
    }
    \caption{NFC扫描后登陆}
    \label{Login}
\end{figure}

注册新账号的时候会引导填写姓名和上传头像，为了降低用户的心理负担，可以选择不填写真名，并使用默认的预设图片，如图~\ref{Register}所示。

\begin{figure}[htbp]
    \centering
    \subfigure[]
    {
        \begin{minipage}[b]{.3\linewidth}
            \centering
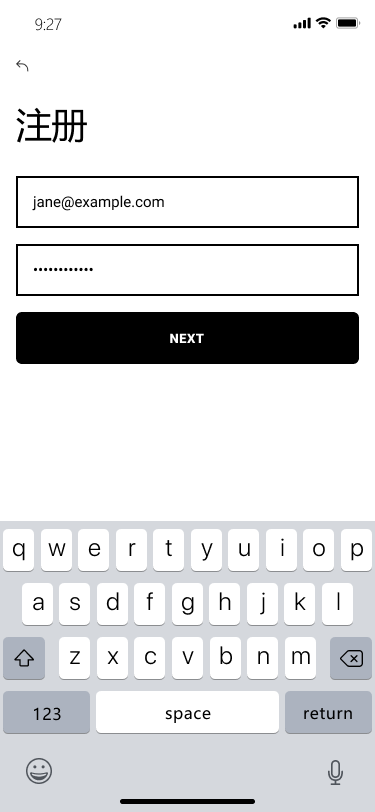
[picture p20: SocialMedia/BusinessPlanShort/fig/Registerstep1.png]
            
        \end{minipage}
    }
    \subfigure[]
    {
         \begin{minipage}[b]{.3\linewidth}
            \centering
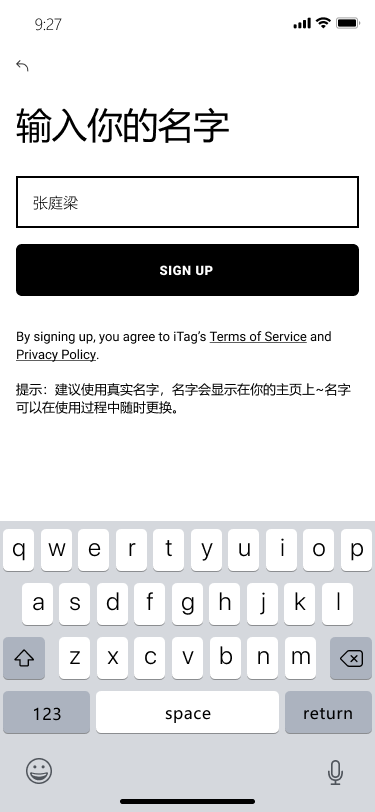
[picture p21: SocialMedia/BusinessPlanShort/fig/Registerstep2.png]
            
        \end{minipage}
    }
    \subfigure[]
    {
         \begin{minipage}[b]{.3\linewidth}
            \centering
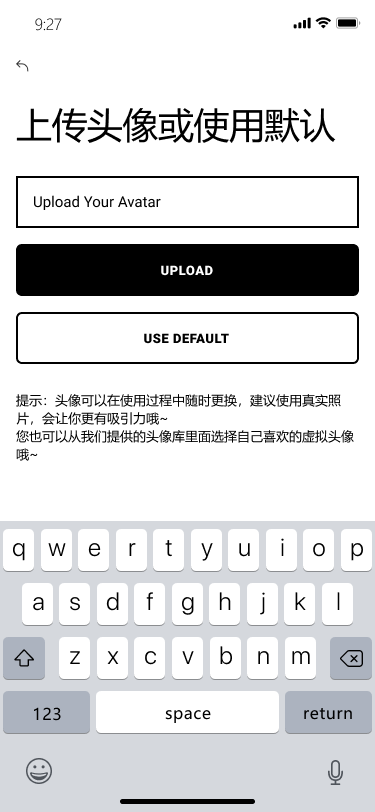
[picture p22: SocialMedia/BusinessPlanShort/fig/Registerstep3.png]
            
        \end{minipage}
    }
    \caption{注册流程}
    \label{Register}
\end{figure}

完成后可以生成一个默认的预设界面，可以在这个基础上去添加信息。比如编辑主页背景等。最重要的其实是添加社交软件，可以选择多样的社交软件添加，有完备的import wizard帮助你傻瓜式添加社交账号预设，如图~\ref{EditHomepage}所示。

\begin{figure}[htbp]
    \centering
    \subfigure[]
    {
         \begin{minipage}[b]{.3\linewidth}
            \centering
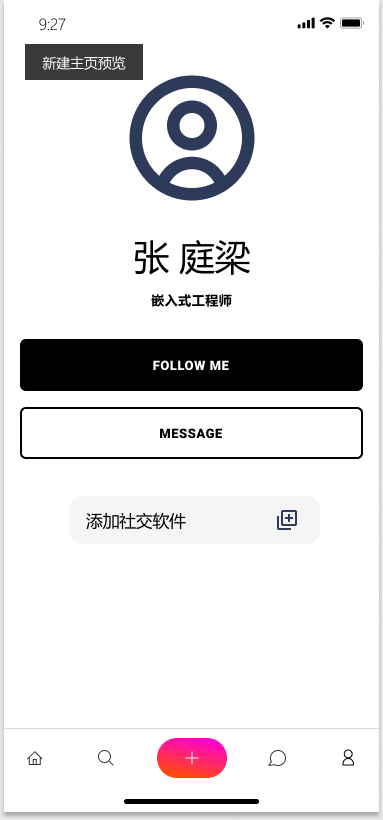
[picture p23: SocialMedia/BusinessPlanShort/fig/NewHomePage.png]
            
        \end{minipage}
    }
    \subfigure[]
    {
        \begin{minipage}[b]{.3\linewidth}
            \centering
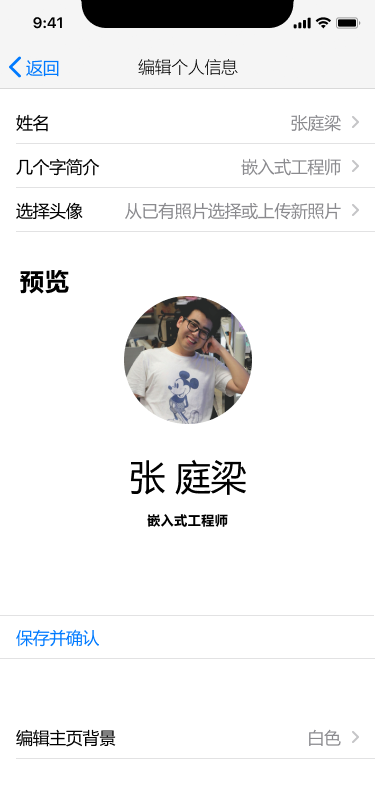
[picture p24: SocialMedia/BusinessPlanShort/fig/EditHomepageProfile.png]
            
        \end{minipage}
    }
    \subfigure[]
    {
         \begin{minipage}[b]{.3\linewidth}
            \centering
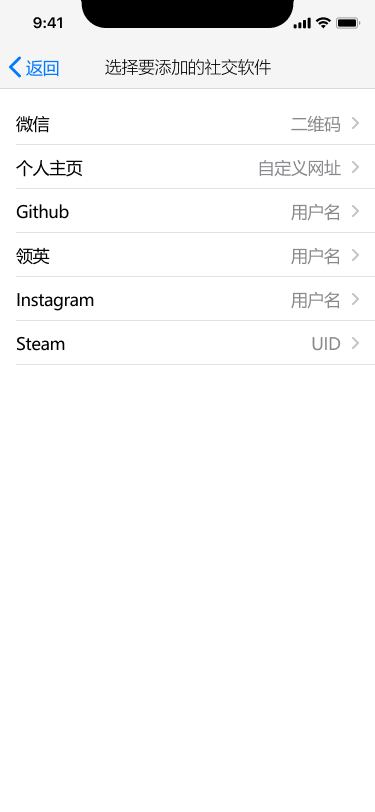
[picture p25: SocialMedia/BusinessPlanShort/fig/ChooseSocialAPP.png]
            
        \end{minipage}
    }
    \caption{编辑主页预设}
    \label{EditHomepage}
\end{figure}

一些主页预设样例如图~\ref{HomepageExample}所示，主页的预设自由度非常高，高级用户或者企业用户甚至可以编写更多功能的HTML+Javascript，部署到我们的系统中。

\begin{figure}[htbp]
    \centering
    \subfigure[]
    {
         \begin{minipage}[b]{.3\linewidth}
            \centering
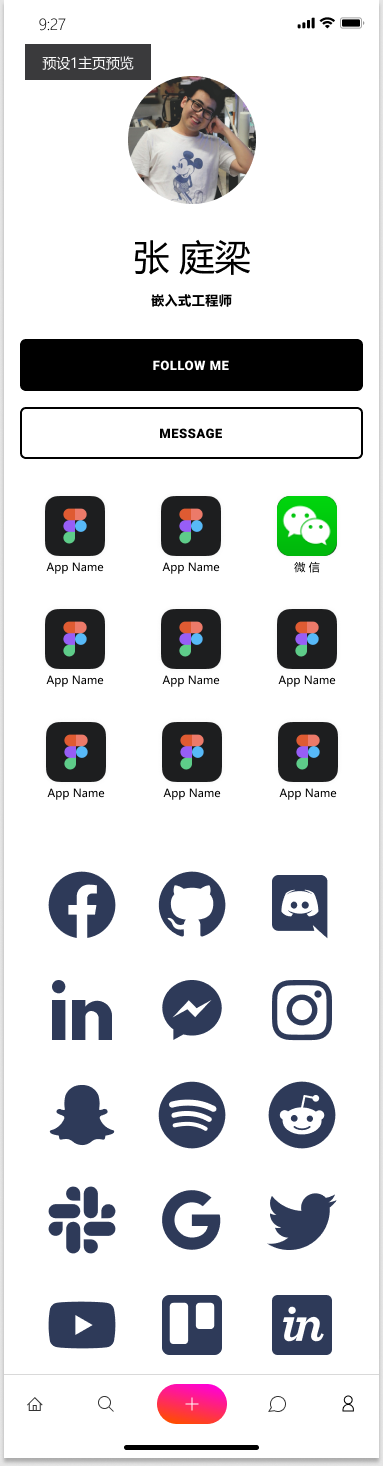
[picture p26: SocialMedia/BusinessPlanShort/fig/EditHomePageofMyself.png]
            
        \end{minipage}
    }
    \subfigure[]
    {
        \begin{minipage}[b]{.3\linewidth}
            \centering
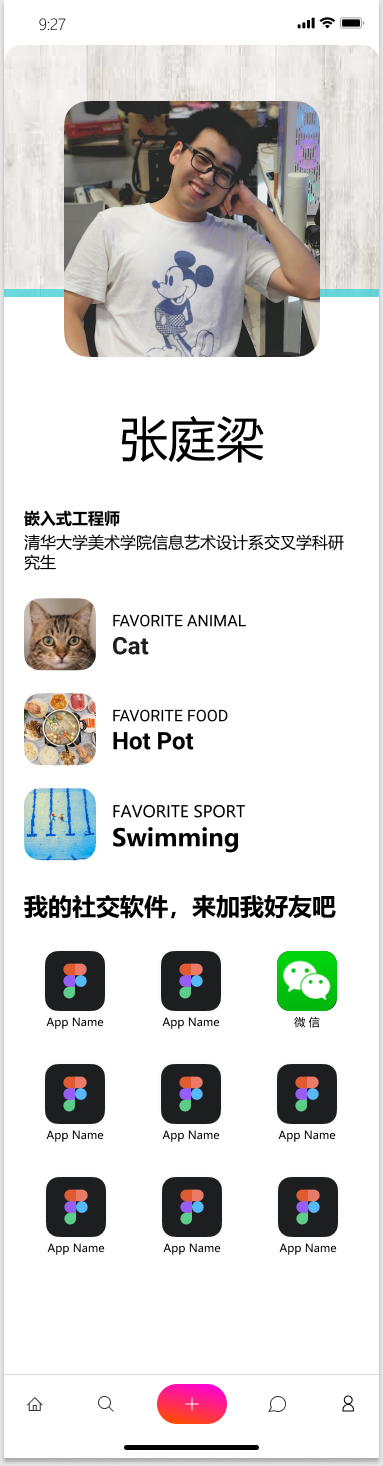
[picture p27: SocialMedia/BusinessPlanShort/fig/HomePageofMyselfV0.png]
            
        \end{minipage}
    }
    \subfigure[]
    {
         \begin{minipage}[b]{.3\linewidth}
            \centering
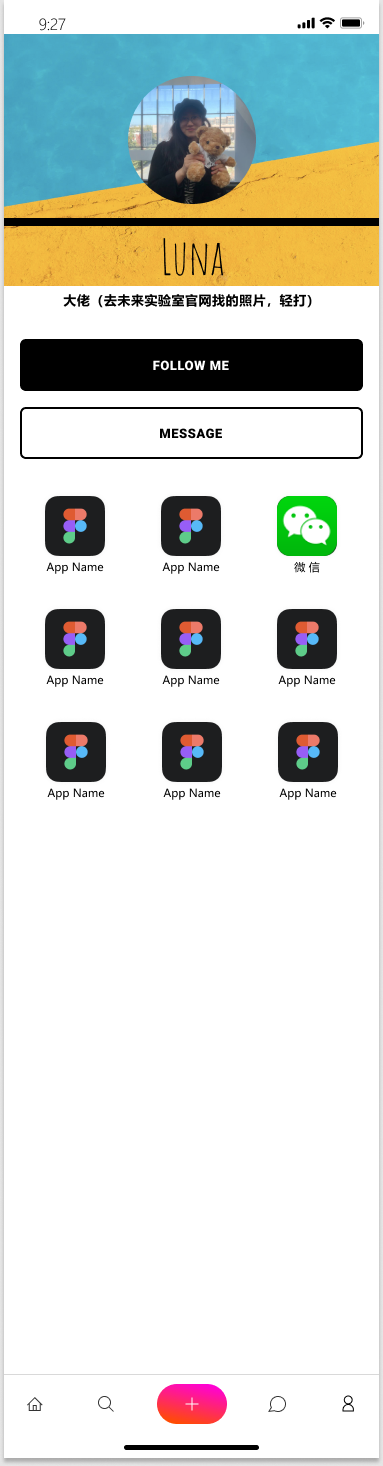
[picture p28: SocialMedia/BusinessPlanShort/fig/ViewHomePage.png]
            
        \end{minipage}
    }
    \caption{主页预设样例}
    \label{HomepageExample}
\end{figure}

卡片管理系统也是保护个人隐私重要的一环，在这里你可以看到拥有的所有卡片，方便改变卡片显示的内容（即实现定义好的预设），同时可以设置权限，即特定的用户可见，如图~\ref{CardManageSystem}所示。如果卡片丢失，可以在卡片管理页面一键禁用此卡片，以保证个人信息安全。

\begin{figure}[htbp]
    \centering
    \subfigure[]
    {
         \begin{minipage}[b]{.3\linewidth}
            \centering
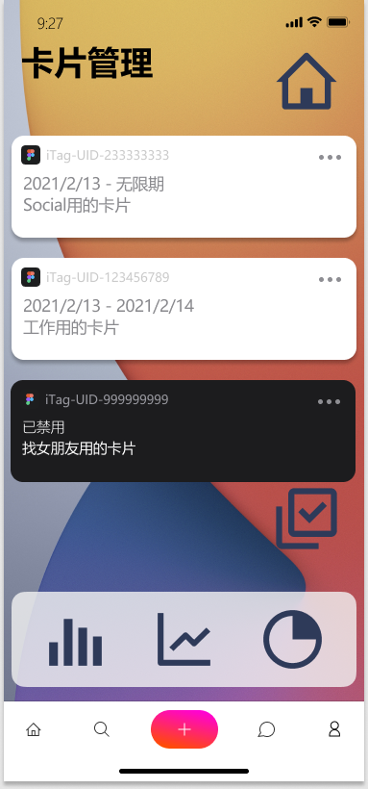
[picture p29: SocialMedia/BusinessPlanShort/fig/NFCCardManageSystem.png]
            
        \end{minipage}
    }
    \subfigure[]
    {
        \begin{minipage}[b]{.3\linewidth}
            \centering
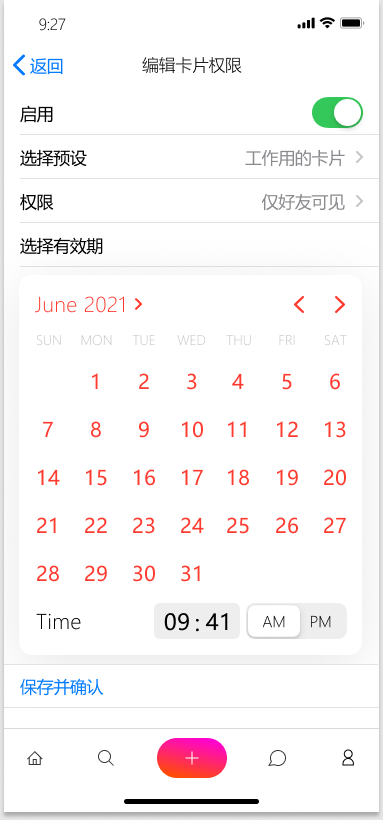
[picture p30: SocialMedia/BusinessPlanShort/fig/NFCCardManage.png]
            
        \end{minipage}
    }
    \subfigure[]
    {
         \begin{minipage}[b]{.3\linewidth}
            \centering
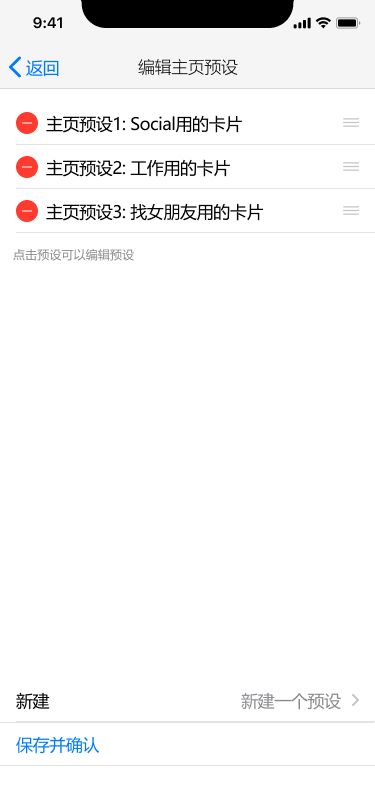
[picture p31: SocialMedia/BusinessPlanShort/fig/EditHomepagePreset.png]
            
        \end{minipage}
    }
    \caption{卡片管理系统}
    \label{CardManageSystem}
\end{figure}

简单设置好预设后，这张卡片的链接会自动绑定到你选择的预设页面，当碰一碰其他人的手机时，对方的手机将会提示打开这一页面。微信比较特别，一般时通过扫描二维码或者搜索微信号添加好友，所以会有详尽的引导（保存图片-扫一扫添加）。其他软件如Github、Instagram、Bilibili等都有直链网址，直接打开即可，如图~\ref{ScanProcedure}所示。

\begin{figure}[htbp]
    \centering
    \subfigure[]
    {
         \begin{minipage}[b]{.3\linewidth}
            \centering
            
        \end{minipage}
    }
    \subfigure[]
    {
        \begin{minipage}[b]{.3\linewidth}
            \centering
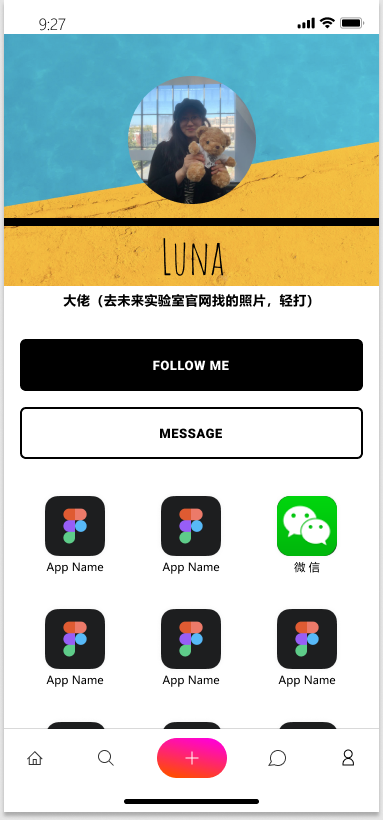
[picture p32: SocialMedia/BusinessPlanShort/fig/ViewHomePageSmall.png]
            
        \end{minipage}
    }
    \subfigure[]
    {
         \begin{minipage}[b]{.3\linewidth}
            \centering
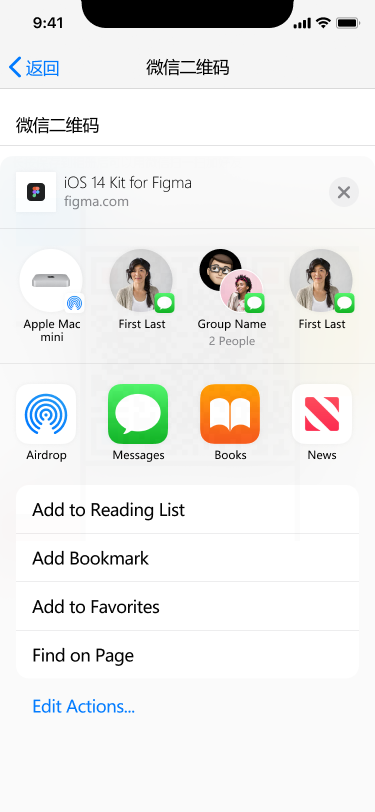
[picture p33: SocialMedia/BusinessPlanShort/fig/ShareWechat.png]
            
        \end{minipage}
    }
    \caption{对方扫描流程}
    \label{ScanProcedure}
\end{figure}

在软件部分的最后我们重提隐私安全问题：

如前所述，几乎每一个流行的陌生人社交软件都曾被网络攻击，发生用户隐私数据被窃取或倒卖事件。由于陌生人社交信息数据量大而且敏感，一旦被窃取，可能会用于诈骗甚至可以分析出每个人的偏好，如果公开可能会对用户造成极大的影响，甚至造成社会性死亡。

所以在iTag设计之初我们就很重视用户的隐私安全：

由于我们不要求用户提供位置信息和其他的真实个人信息，用户的心理负担更小。

NFC卡片中只有一个带有SHA256加密后的UID信息，链接到特定的自定义页面中。同时NFC芯片也自带硬件加密，KeyAB一定程度上保证破解器很难读写卡内信息。对于特别关注信息安全的用户，我们还特别设计CPU卡版本，从硬件层面提供信息安全保证。

同时我们使用去中心化的区块链保存用户提供的部分个人信息，隐私信息能够被妥善保存。

\section{游戏策划}

一款类Ingress的基于地理位置的大型多人侵入式虚拟现实游戏。

\begin{tcolorbox}[breakable]
    游戏的故事背景是一群欧洲科学家偶然发现某种神秘的能量XM（Exotic Matter），这一能量的来源和用途无人知晓，研究人员认为可以开发并善用这能量，但另一方面却担心这样的能量会影响人们的思考甚至被能量本身奴役。

    游戏中有两大主要阵营，这两大互相争夺主控权的全球性组织分别是“反抗军”和“启蒙军”。“启蒙军”（Enlightened，以绿色标示）阵营希望能接纳这股“神秘的能量XM”，并相信这股能量能赐予人类进步与改革，其追随者相信神秘的能量会催生影响重大的“启蒙运动”，使全人类进化。另一派“反抗军”（Resistance，以蓝色标示）阵营则奋力捍卫并守护仅存的人性，有些人认为他们对于变化或进步感到畏惧，但反抗军坚信这一切都是为了保护人类。游戏的玩家被称为特工（Agent），两个阵营互相角力，争夺控制真实世界中的地标性建筑或雕塑等Portal（译作“传送门”）。

    游戏内容和真实世界的地理状况结合，游戏会透过手持装置的GPS、AGPS以及Wi-Fi信息确认玩家的位置，而玩家可以透过游戏的扫描器（Scanner）界面看到自身周围的传送门、XM或物品。游戏地图上各处散落着白色亮点，代表XM所在的位置，玩家在接近XM时会自动收集，而对传送门进行任何操作均需耗用XM。传送门主要是各种建筑、雕塑、艺术品等，玩家需亲自持手机接近这些传送门，进行部署（Deploy）、入侵（Hack）、补充能量（Recharge）、发射XMP等动作。玩家在游戏中的目标是透过连接多个本阵营控制的传送门，建立控制场（Control Field），覆盖最多的“Mind Units（MUs）”。

    在游戏中，全球各处存在着大量传送门（Portal），可以在游戏软件中察看。传送门都与实际地标关联，并且位在可被公众探访且步行能抵达的地点，例如：雕塑、壁画、公共艺术、喷泉、艺术涂鸦、图书馆、教学楼、水塔、邮局、纪念馆、宗教建筑、地铁站；醒目的建筑和独特的当地企业；国家公园、露营地、主题公园的入口等。根据当前控制传送门的阵营不同，传送门会呈现出不同的颜色：启蒙军阵营控制时为绿色，反抗军阵营控制时为蓝色，无人控制时为灰色，双方的玩家都可以占领这些灰色的传送门。

    游戏的目的是争夺传送门并制造控制场（Control Field），以获取Mind Units。玩家可以使用炸弹（XMP）攻击敌方传送门，削弱目标据点共振器的能量值，要是一个共振器失去全部能量，它就被摧毁了。如果全部的共振器都被摧毁，传送门就会转为中性（Neutral），玩家接着可以放置最多八个共振器控制该传送门。另外，共振器的能量每天都会下降，而玩家可以替他充能（Recharge）以使其保持较高的能量，以免敌人轻易摧毁这些共振器。除了在传送门旁边直接替它充能，玩家若持有一条传送门的钥匙亦可在一定距离外替它充能，只是充能效益（Recharge Efficiency）会随玩家与传送门的距离有所衰减。

    当两个传送门都已摆满八个共振器，而玩家同时持有目标的钥匙、目标在所在传送门的覆盖范围之内、不在任何一个Field（该Portal作为顶点的情况除外）内、路径内没有其他的Link这几个条件全部达成，就可以在两个传送门间建立链接（Link）。如果玩家在游戏中使三个传送门连成三角形，就会产生一个控制场（Control Field）。控制场会让玩家的阵营获得Mind Units（MUs），MUs的数量与Field所覆盖范围的人口密度与Field大小有关，玩家在局势 （Intel）标签下可以查看两大阵营各自累积了多少MUs。

    当Portal因为被攻击/能量丧失等原因导致剩下3个以及3个以下的Resonator时，该Portal所连接的所有Link将会失效，同时以其为顶点的Field也会失效。且有几率掉落向外连接的Link的目标的Portal Key。

    由于三角形潜在的相互嵌套的几何性质，玩家可依照特定的连结顺序，建立多重控制场 ，在同一区域获取多倍的 AP 值。 玩家也能够利用情报地图（Intel Map）查看区域乃至世界的连结及控制场布局，规划战略。\cite{wiki:Ingress}
\end{tcolorbox}

未来我们官方及其社群为了加强玩家互动，会不定期组织一系列官方、半官方特别活动，以调动玩家的积极性。如图~\ref{Ingress}所示。

\begin{figure}[htbp]
    \centering
    \subfigure[]
    {
         \begin{minipage}[b]{.3\linewidth}
            \centering
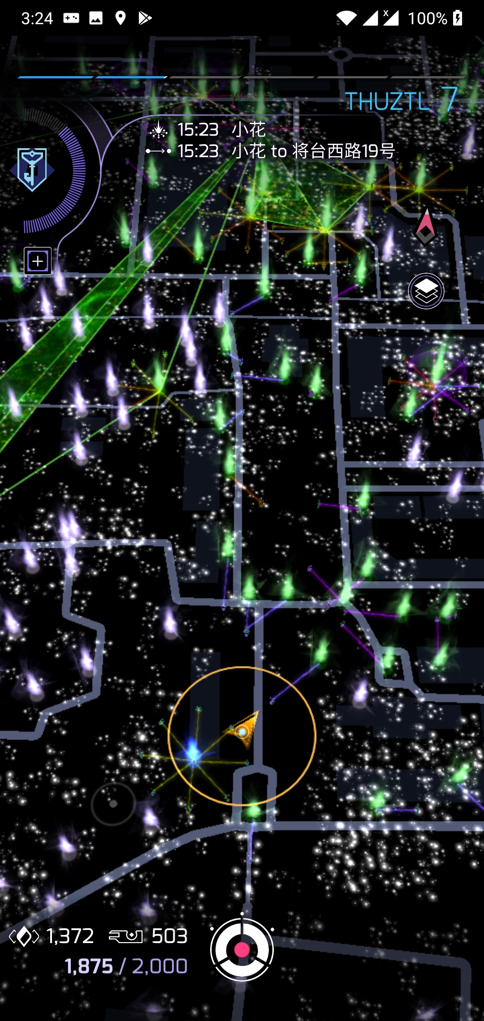
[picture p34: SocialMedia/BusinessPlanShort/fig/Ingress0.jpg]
            
        \end{minipage}
    }
    \subfigure[]
    {
        \begin{minipage}[b]{.3\linewidth}
            \centering
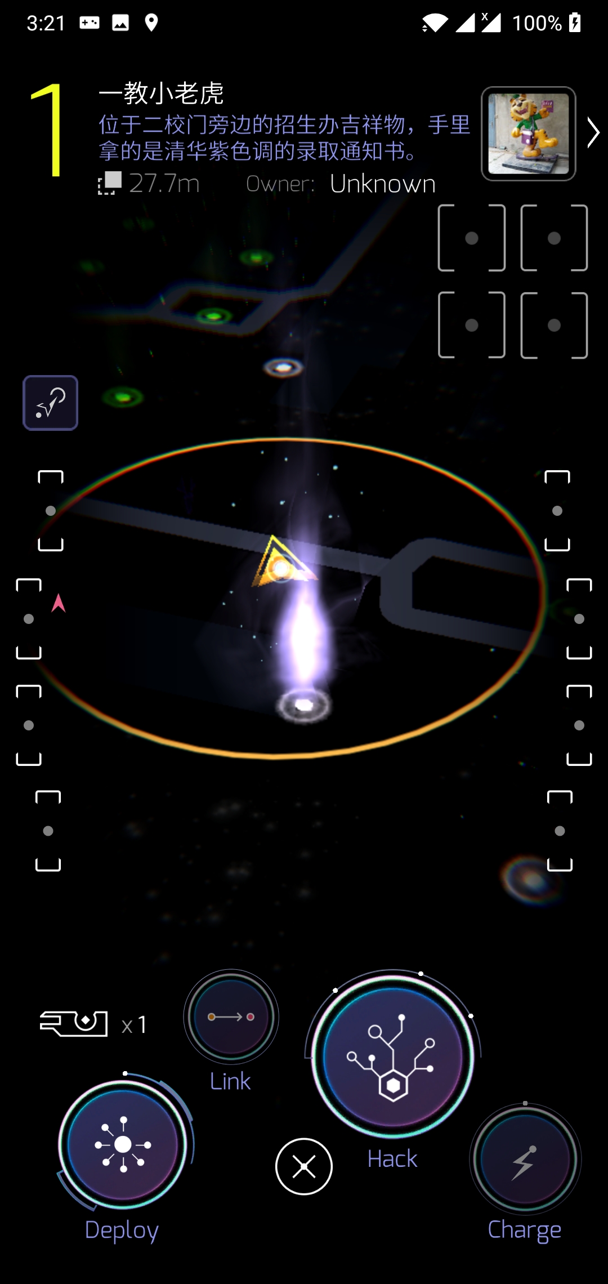
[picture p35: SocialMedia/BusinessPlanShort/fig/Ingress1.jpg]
            
        \end{minipage}
    }
    \subfigure[]
    {
         \begin{minipage}[b]{.3\linewidth}
            \centering
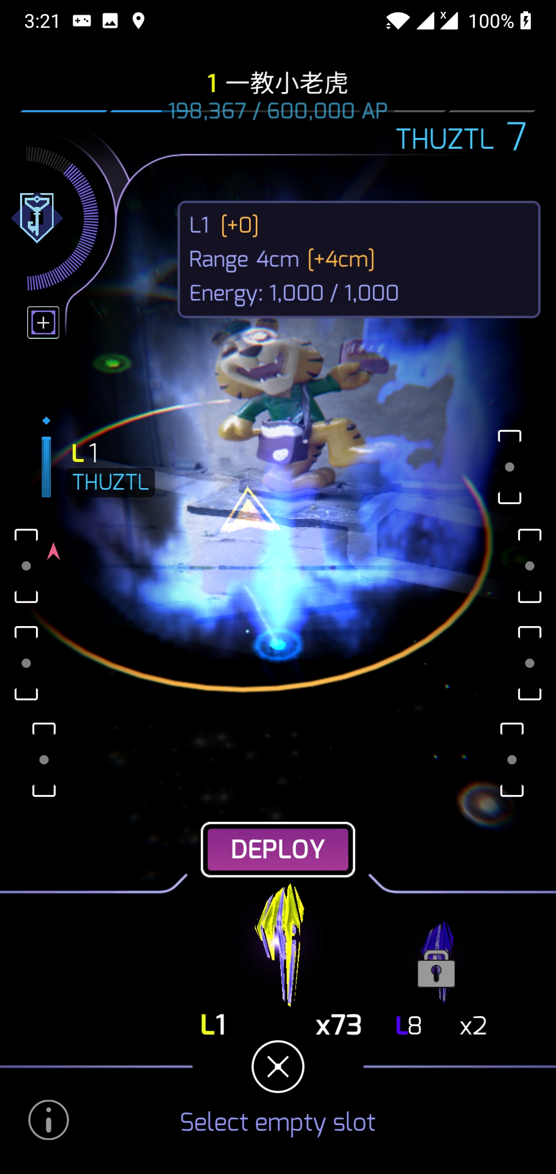
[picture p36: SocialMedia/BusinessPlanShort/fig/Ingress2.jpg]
            
        \end{minipage}
    }
    \caption{游戏机制示意}
    \label{Ingress}
\end{figure}

在定位技术细节方面，高德地图或Google Maps的授权费用过高，我们选择使用OpenStreetMap地图源。而且Google Maps在中国大陆境内不能正确显示地理位置，其原因为中国大陆以国家安全为由要求所有境内地图测绘单位使用国家自行定制的GCJ-02 坐标系统，该系统对GPS使用的WGS84坐标系统进行偏移，所以其地图与实际坐标有500米左右的偏移。而由于GPS坐标系统与OSM坐标系统使用的卫星坐标体系一致，因此坐标偏移问题得以解决。

\section{盈利模式}

内测阶段基本不盈利，运营成本由Kickstarter等众筹平台和内测版本iTag卡片出售盈利以及捐赠款支持。由于初期服务器使用单个本地服务器和低性能阿里云服务器结合的方式，iTag使用国产NFC tag半成品生产，成本约几毛钱一个，可以实现盈亏相抵。

用户量破万后，主要是联名款、定制款和智能款iTag出售盈利。

用户百万量级时（游戏系统上线），游戏内购可以作为一部分盈利来源，同时，引入赞助，赞助商家可以将门店设置为portal所在地，从而吸引玩家前来朝圣或聚集。比如餐厅、咖啡店、超市等，可以通过这一方式吸引顾客特别是游客。相当于一种隐性的广告。

经过慎重考虑，我们决定软件本体永久免费，而且社交主页永久没有广告，给用户做出这一承诺有助于吸引更多的用户。

在用户接近千万时，说明软件热度已经达到一个里程碑，我们将进一步发行游戏周边，以及联名款卡片。

\section{参考文献}

\bibliography{social}
\bibliographystyle{plain}

% \newpage
% \section{附录}

% \begin{figure}[htbp]
%     \centering
%     \includegraphics[width=\linewidth]{Login.png}
%     \caption{嘿嘿嘿} 
%     \label{1}
% \end{figure}

\end{document}

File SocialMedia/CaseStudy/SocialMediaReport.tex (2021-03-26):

% Compile with latex+dvipdfmx, pdflatex, xelatex or lualatex
% XeLaTeX is recommanded

\documentclass[UTF8]{ctexart}
\usepackage[T1]{fontenc}
\usepackage[colorlinks,
linkcolor=red,
anchorcolor=blue,
citecolor=green
]{hyperref}
\usepackage{tcolorbox}
\tcbuselibrary{breakable}
% 如果框内的内容多于一页需要设置自动断页[breakable]但是要注意先使用breakable库

\title{陌生人社交生态概述}
\author{张庭梁}
\date{\today}

\begin{document}

\maketitle

\section{摘要}

本文从探探的发展出发，延伸探讨广义上的陌生人社交软件的发展和存在的问题，最后探讨现有软件的问题成因和可能的解决方案。

\section{陌生人社交软件发展-以探探为例}
本章以探探为例，简单梳理陌生人社交软件发展。

探探是中国大陆一款基于地理位置的社交应用程序，由王宇和潘滢创立，于2014年上线，其目标人群定位在20岁至26岁的用户。使用上，探探被认为模仿了同类应用程序Tinder，双方只有互相喜欢，才能开始聊天,因此得名“约炮神器”。探探亦上线了“擦肩而过”和“匿名表白”功能，并做了一系列尝试来规范用户行为。探探推出后在85后到90后的用户群中较为热门，但其“匿名表白”功能曾引发侵权争议，其安全性也遭到过质疑。

2018年2月23日陌陌斥资7.71亿美元收购探探科技（北京）有限公司。交易成功后，探探团队继续独立运营产品和品牌。\cite{MoMoHistory}

探探被认为模仿了美国同类应用程序Tinder，其主要基于地理位置和大数据平台，向用户提供个性化推荐。其在交互方式上采用了简单的动作设置：如果喜欢某一对象，就往右滑，不喜欢则往左滑。之后，系统自动进行配对，如果双方互相喜欢，系统会明确告知给两个用户，双方才能开始聊天，否则彼此不会收到任何消息。

此外，探探亦上线了“擦肩而过”和“匿名表白”功能，“擦肩而过”是探探开发的一项基于GPS系统的服务，如果有喜欢的人从附近经过，探探会进行提示并显示距离。“匿名表白”是探探基于手机通信录的一种匿名表达爱慕之情的功能，使用该功能，用户可以对通信录的好友匿名表白，并邀请该位好友加入成为探探用户。在使用“匿名表白”功能时，如果被表白的一方尚未注册探探账户，系统会自动发送暗恋短信到被表白一方的手机上，此举引发了侵权争议，存在违法嫌疑。

信息安全性方面，企业家拉里·萨利布拉使用Xcode对软件进行逆向工程时发现该软件缺乏加密措施，因此，稍有技术的黑客即可获取用户的用户名、密码、电话号码，甚至对话。

2019年06月28日，国家网信办发布，其会同有关部门，针对网络音频乱象启动专项整治行动。根据群众举报线索，经核查取证，首批依法依规对吱呀、Soul、语玩、一说FM等26款传播历史虚无主义、淫秽色情内容的违法违规音频平台，分别采取了约谈、下架、关停服务等阶梯处罚，对音频行业进行全面集中整治。有关负责人表示，此次专项整治不仅要坚决有效遏制行业乱象，也要积极规范行业发展，促进网络生态持续向好。\cite{Audio}

根据《关于开展App违法违规收集使用个人信息专项治理的公告》，受中央网信办、工信部、公安部、市场监管总局委托，全国信息安全标准化技术委员会、中国消费者协会、中国互联网协会、中国网络空间安全协会成立App专项治理工作组，对用户数量大、与民众生活密切相关的App隐私政策和个人信息收集使用情况进行评估。2019年7月12日，包括探探等在内的30款App因违反《网络安全法》关于收集使用个人信息的相关规定，被通报30日内完成整改。\cite{Privacy}

探探部分用户协议摘录如下：

\begin{tcolorbox}
    3.1 为了能使用本服务，您需要注册探探帐号，应当使用手机号码绑定注册，请用户使用尚未与“探探”帐号绑定的手机号码，以及未被探探文化封禁的手机号码注册“探探”帐号。根据法律法规的要求，探探文化可以根据用户需求或产品需要对帐号注册和绑定的方式进行变更，您应在法律法规的要求下予以配合。

    3.2 “探探”系基于地理位置的移动社交产品，用户注册时应当授权探探文化公开及使用其地理位置信息方可成功注册“探探”帐号。故用户完成注册即表明用户同意探探文化提取、公开及使用用户的地理位置信息。

    3.3 鉴于探探帐号的注册方式，且为了保护您账号的安全，您同意探探文化在注册时使用您提供的手机号码及/或自动提取您的手机号码及您的手机设备识别码等信息用于注册。同时如果您可以选择开启使用某些功能，您同意探探文化取得您的手机通讯录信息以使这些功能可以实现。

    3.4 在用户注册及使用本服务时，探探文化需要搜集能识别用户身份的个人信息以便探探文化可以在必要时联系用户，或为用户提供更好的使用体验。探探文化搜集的信息包括但不限于用户的姓名、性别、年龄、出生日期、身份证号、地址、学校情况、公司情况、所属行业、兴趣爱好、常出没的地方、个人说明；探探文化同意对这些信息的使用将受限于个人隐私信息相关法律和探探隐私政策的约束。\cite{MoMoAgreement}
\end{tcolorbox}

其实和国内很多软件一样，在安装时索取了远超自己APP需要的权限，当然这和隐私保护的乱象有关，同样的应用在苹果商店就老实很多，比安卓商店索取的权限要少很多。

\section{现有产品研究}
本章我们研究现有的陌生人社交和部分典型的熟人社交软件。

\subsection{陌生人社交定义}

\begin{tcolorbox}
    互联网语境下的社交是用户间的信息交流和互动，最典型的社交产品是早期的微信和QQ，但现在微信和QQ已不仅仅是社交产品，更是生活方式。

    在社交的分类中，按用户关系距离来分，可分为熟人社交（QQ、微信）和陌生人社交（探探、陌陌、Soul、她说等婚恋交友软件）。

    从社交的定义可以得到陌生人社交指陌生用户间的信息交流和互动，社交整体过程归纳总结起来就是以下两点：关系的建立+关系的沉淀（维系和发展）。而陌生人社交的重点会更偏关系的建立，特点是：它是对现实的补充，具有很大的虚拟性。\cite{StrangerDefine}
\end{tcolorbox}

其实建立关系只是第一步，更重要的是关系的沉淀。我们希望开发的是一款提供相识机会，但更注重引导关系发展的社交应用。

\subsection{陌生人社交平台分类}
我将陌生人社交平台分为三类：LBS(Location Based Services,基于位置的服务)社交应用、婚恋市场、兴趣交友。

LBS社交包括Tinder、探探和陌陌、微信附近的人等，主打短期关系和荷尔蒙社交，颜值基本上就是其中唯一的社交资本。

婚恋市场主要玩家为世纪佳缘、百合网，社交资本稍多元，包括收入、职业、户口等，但婚恋市场更加功利，用户普遍为30-40岁，有更高的收入，追求相亲的效率，VIP服务收费较高，从几万到几十万不等。

兴趣交友类包括Soul、Summer等，本意是兴趣交友，社交资本更为多元，有助于寻找到共同话题。Summer主打高校市场：分享校园欢乐日常、大学生专属身份认证、面向全国高校开放、答题交友。Soul则主打匿名性的轻松感，不用上传头像、视频露脸或者实名。但是这些应用经过一年多的发展，鱼龙混杂的用户涌入，渐渐和探探等同质化。

Tinder的核心是左滑跳过右滑Like的配对机制，只有双方互相Like之后才能开始进一步聊天，后续Tinder还推出了和Facebook Instagram等社交软件的联动，付费版本可以Like更多的人甚至在Like之前看这个人有没有Like你，在2020年因为安全方面的考量，Tinder也推出了一键SOS报警功能。\cite{WikiTinderFeatures}
在信息安全方面，Tinder也曾爆出不少漏洞，每次打开和进行匹配的精确地理位置甚至聊天视频内容的泄露漏洞，以及卫报记者单人长达800页的用户数据历史，包括时间、地点、个人喜好、受众人群、每个照片浏览时间。一旦这些十分隐私的详尽数据泄露，后果不堪设想。\cite{WikiTinderFeatures}

探探应用中存在大量虚假信息、骗子、甚至聊天机器人。打擦边球构筑的不健康的商业模式。用户粘性有限，商业潜力有限。软件缺乏加密措施，因此，稍有技术的黑客即可获取用户的用户名、密码、电话号码，甚至对话。\cite{WikiTantan}
陌陌类应用其实依靠的是打擦边球构筑的不健康的商业模式，用户粘性和商业潜力有限。其中大量虚假信息、骗子、甚至聊天机器人，进一步增加了用户对其不信任感。\cite{MoMoWhy}

以世纪佳缘、百合网等交友软件为代表的婚恋市场婚恋市场则更加功利，用户普遍为30-40岁，有更高的收入，追求相亲的效率。
但是婚恋网站上面信息不实，婚介和外包由于资源不足合伙骗人，甚至还有金融理财诈骗、传销组织奔现等陷阱，这些因素让婚恋市场的信誉不断受损。\cite{CheatTheLiving}
知乎上也有大量的关于平台或代理商请的托恶意骗钱行为的例子，比如\url{https://www.zhihu.com/question/37751869}
婚恋平台上存在大量不实个人信息但是过于严格的筛查审核机制会劝退很多用户，用户不愿意一次性上传过多真实个人信息和照片，如学位证身份证等。\cite{WikiJiayuan}
盈利主要靠VIP或一对一红娘收费，收费普遍极高，条件差距大的收费更高，甚至于几十万的天价中介费。盈利方式不健康。

SOUL这一兴趣交友网站开始的模式很吸引人，类似树洞的匿名，个人信息的自由，和探探等yp应用区分开了。但是没有树洞的自由，屏蔽词恶心用户。匿名下的乱象丛生令这个平台鱼龙混杂，广场变为寻求满足感的匿名微博式平台。\cite{Soul}
Summer类似Soul但是主打高校市场，核心功能包括分享校园欢乐日常、大学生专属身份认证、面向全国高校开放、答题交友趣味刷题。但近些年发展也不算很快。

\section{总结与讨论}

广义上的陌生人社交软件包括如下问题：

\begin{itemize}
    \item 信息安全问题：LBS应用普遍存在的问题，海量个人信息（特别是位置信息）泄露的可能性
    \item 用户人身安全问题
    \item 荷尔蒙导向应用的不可持续性和用户留存率低
    \item 很多人不愿意不希望自己的真实照片被公开，被挑选。
    \item 关键词审核过于严格，实名信息审查过于敷衍了事
    \item 大量虚假用户和骗子，平台鱼龙混杂
    \item 平台收费过高，线下分店通过和代理商和托儿一起蒙骗客户盈利
    \item 流量中心化：少数用户获得多数资源——社交资本太单一，基本就只以颜值为主
\end{itemize}

可能的解决方案如下：

\begin{itemize}
    \item 不再要求用户提供位置权限
    \item 用户不必向公网公布个人信息，也不必给平台提供任何信息
    \item 提倡长期关系，而非荷尔蒙驱动关系
    \item 多元的社交资本，避免流量中心化
    \item 安全的兴趣广场
    \item 可持续发展，高的用户留存度
    \item 全免费平台，无广告环境
\end{itemize}

\section{参考文献}

\bibliography{social}
\bibliographystyle{plain}

\end{document}

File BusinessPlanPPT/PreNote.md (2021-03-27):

## 20210327清华校长杯Pre笔记

介绍团队成员：

我们的团队由清华大学信息艺术设计交叉学科的同学组成。我是张庭梁，去年拿了清华大学挑战杯特奖，也是星火计划十二期的成员，本科电机系，主要负责硬件和网站运维。高明月是计算机本科，之前是学生会主席，主要负责商业联络。我室友诚驰是信息奥林匹克金牌，我和他一起写网页和游戏的代码。

说清楚我们做的是什么：

一套从线下开始的微微熟社交生态，希望为用户提供一个安全自然的扩展社交圈子的方式。

NFC电子名片、游戏社交、线下认识

我们想颠覆的是微信的线上熟人社交垄断，和探探等陌生人社交软件的不自然不安全。NFC能有效避免需要双方打开微信扫一扫和二维码这一过程的冗长和尴尬。而相较于社交资本单一、几乎以颜值为唯一标准的陌生人社交软件，我们提供给用户多角度展示自己的机会。

内测阶段，我们和线下社群合作，推广我们的产品。在社团小聚、百团等场景扩展我们的业务。

商业模式和盈利模式再说。

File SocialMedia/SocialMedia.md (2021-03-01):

## 线上线下相结合的创新性社交媒体

本意是，抛开iTag的NFC硬件技术和婚恋市场的属性，iTag作为一款鼓励人们进行线下社交的软件，还剩下的部分及其价值。

## 重点

信息安全问题：LBS应用普遍存在的问题，海量个人信息（特别是位置信息）泄露的可能性

用户人身安全问题

荷尔蒙导向应用的不可持续性和用户留存率低

很多人不愿意不希望自己的真实照片被公开，被挑选。

关键词审核过于严格，实名信息审查过于敷衍了事

大量虚假用户和骗子，平台鱼龙混杂

平台收费过高，线下分店通过和代理商和托儿一起蒙骗客户盈利

流量中心化：少数用户获得多数资源——社交资本太单一，基本就只以颜值为主

## 解决方法

兴趣社交广场和版主审核制度或AI自动审核

## 陌生人社交定义

互联网语境下的社交是用户间的信息交流和互动，最典型的社交产品是早期的微信和QQ，但现在微信和QQ已不仅仅是社交产品，更是生活方式。

在社交的分类中，按用户关系距离来分，可分为熟人社交（QQ、微信）和陌生人社交（探探、陌陌、Soul、她说等婚恋交友软件）。

从社交的定义可以得到陌生人社交指陌生用户间的信息交流和互动，社交整体过程归纳总结起来就是以下两点：关系的建立+关系的沉淀（维系和发展）。而陌生人社交的重点会更偏关系的建立，特点是：它是对现实的补充，具有很大的虚拟性。

## 目标用户

青年，有深度社交需求的。

## 社交模式的定位

年轻人的社交距离感越来越严重，人与人之间的强连接更少了。

为了让人们能够更多的放下手机，和现实生活中的人交朋友

## 希望看到的效果

一二线城市的年轻人能使用这款软件，构建自己的小圈子。

## 准备采取的措施

采用广场和兴趣圈子，以兴趣和身份为导向，构建起初的话题。

融入语音和视频社交元素，强调实时社交。真实场景下的社交模式就是具有实时性的

鼓励线下见面，以线下见面为主导，甚至是开始。当你看到一个好看小哥哥的时候，会主动上前要微信。

基于位置、兴趣方向、身份、年龄的智能推荐

## 和其他社交模式的比较

微信

探探，还是陌陌来着

Clubhouse

QQ

Summer

## 其他的一些商业做法

先在清华校内内测，利用名人效应，"清华人的线下社交软件"

搞饥饿营销，每个人给两个邀请码，Clubhouse做法

每个社交软件最后基本上都变成了约炮或者带货平台。

最好的交友软件游戏。

## 新的社交礼仪的定义

合适的公开适当的信息，千人千面。

## Tinder系列（LBS交友sex without relationships为核心）

基于地理位置的LBS社交应用程序

陌陌（以及被其收购的探探）、Tinder、Summer

https://en.wikipedia.org/wiki/Tinder_(app)

### Tinder Features

- **Swipe** is central to Tinder's design. The app's algorithm provides users, swipe right to "like" potential matches and swipe left to continue on their search from the compatible matches.[[62\]](https://en.wikipedia.org/wiki/Tinder_(app)#cite_note-62)
- **Messaging** is also a heavily utilized feature. Once a user matches with another user, they're able to exchange text messages on the app.[[63\]](https://en.wikipedia.org/wiki/Tinder_(app)#cite_note-63)
- **[Instagram](https://en.wikipedia.org/wiki/Instagram) integration** enables users to access other users' Instagram profiles.[[64\]](https://en.wikipedia.org/wiki/Tinder_(app)#cite_note-Crook-64)
- **Common Connections** allows users to see whether they share a mutual Facebook friend with a match (a first-degree connection on Tinder) or when a user and their match have two separate friends who happen to be friends with each other (considered second-degree on Tinder).[[64\]](https://en.wikipedia.org/wiki/Tinder_(app)#cite_note-Crook-64)[[65\]](https://en.wikipedia.org/wiki/Tinder_(app)#cite_note-65)
- **Tinder Gold**, introduced worldwide in August 2017, is a premium subscription feature that allows the user to see those who have already liked them before swiping.[[66\]](https://en.wikipedia.org/wiki/Tinder_(app)#cite_note-66)
- **Panic button** is introduced in the US from January 2020. The feature will include emergency assistance, location tracking, and photo verification.[[67\]](https://en.wikipedia.org/wiki/Tinder_(app)#cite_note-67)

左滑右滑，配对机制，和Facebook Instagram等社交软件的联动，付费版本可以Like更多的人甚至在Like之前看这个人有没有Like你，SOS报警功能

### Tinder Safety issues

There are also [cybersecurity](https://en.wikipedia.org/wiki/Computer_security), [data privacy](https://en.wikipedia.org/wiki/Information_privacy), and [public health](https://en.wikipedia.org/wiki/Public_health) concerns about Tinder. Public health officials in [Rhode Island](https://en.wikipedia.org/wiki/Rhode_Island) and [Utah](https://en.wikipedia.org/wiki/Utah) have claimed that Tinder and similar apps are responsible for an uptick of some [STDs](https://en.wikipedia.org/wiki/Sexually_transmitted_infection).[[92\]](https://en.wikipedia.org/wiki/Tinder_(app)#cite_note-92) In February 2014, security researchers in New York found a flaw which made it possible to find users' precise locations for between 40 and 165 days. Tinder's spokesperson, Rosette Pambakian, said the issue was resolved within 48 hours. Tinder CEO Sean Rad said in a statement that shortly after being contacted, Tinder implemented specific measures to enhance location security and further obscure location data.[[93\]](https://en.wikipedia.org/wiki/Tinder_(app)#cite_note-93)

In August 2016, two engineers found another flaw that showed all users' matches' exact location. The location was updated every time a user logged into the app and it worked even for blocked matches. The issue was detected in March 2016, but it was not fixed until August 2016.[[94\]](https://en.wikipedia.org/wiki/Tinder_(app)#cite_note-94) In July 2017, a study published in *Advances in Intelligent Systems and Computing* found that Tinder users are excessively willing to disclose their personally identifiable information.[[95\]](https://en.wikipedia.org/wiki/Tinder_(app)#cite_note-95) In September 2017, *[The Guardian](https://en.wikipedia.org/wiki/The_Guardian)* published an article by a journalist who requested all data that the Tinder app had recorded about her from the company and found that Tinder stores all user messages, user locations and times, the characteristics of other users who interest a particular user, the characteristics of particular users of interest to other users, and the length of time users spend looking at particular pictures, which for the journalist amounted to 800 pages of detail.[[96\]](https://en.wikipedia.org/wiki/Tinder_(app)#cite_note-96)

每次打开和进行匹配的精确地理位置甚至聊天视频内容的泄露漏洞，卫报记者单人长达800页的用户数据历史，包括时间、地点、个人喜好、受众人群、每个照片浏览时间。

[探探维基百科](https://zh.wikipedia.org/wiki/%E6%8E%A2%E6%8E%A2)

> 探探新增：“擦肩而过”和“匿名表白”功能，“真心话问答”
>
> “擦肩而过”是探探开发的一项基于GPS系统的服务，如果有喜欢的人从附近经过，探探会进行提示并显示距离。“匿名表白”是探探基于手机通信录的一种匿名表达爱慕之情的功能，使用该功能，用户可以对通信录的好友匿名表白，并邀请该位好友加入成为探探用户。
>
> 2018年底，根据第三方平台监测数据显示，探探月活跃用户2000万远超以409.4万人排名第二的世纪佳缘，为中国大陆排名第一的婚恋交友类应用[[18\]](https://zh.wikipedia.org/wiki/探探#cite_note-jqr-18)。
>
> 企业家拉里·萨利布拉使用[Xcode](https://zh.wikipedia.org/wiki/Xcode)对软件进行[逆向工程](https://zh.wikipedia.org/wiki/逆向工程)时发现该软件缺乏加密措施，因此，稍有技术的黑客即可获取用户的用户名、密码、电话号码，甚至对话。[[10\]](https://zh.wikipedia.org/wiki/探探#cite_note-Quartz-10)
>
> 除此之外，一些不法分子会使用“探探引流脚本”，向匹配成功的用户发送私信，这种现象也形成了扫号、账号买卖的黑产链。同时，该平台的传播欺诈与色情信息问题也引发关注。据媒体报道，有多名用户通过探探结交了骗子，并深陷网络博彩、“卖茶美女”、股票投资等骗局，造成财产损失[[18\]](https://zh.wikipedia.org/wiki/探探#cite_note-jqr-18)。
>
> 2019年4月28日晚，有媒体报道称，应监管部门要求，探探因“传播污秽色情消息”为由，被中国大陆应用商店下架。对此探探就此事回应称“我们会积极配合有关部门的要求”[[9\]](https://zh.wikipedia.org/wiki/探探#cite_note-xjb-9)[[19\]](https://zh.wikipedia.org/wiki/探探#cite_note-19)

[陷入招嫖争议、市值跌去六成，陌陌到底怎么了？](https://www.jiemian.com/article/5703382.html)

> 2020年底，齐鲁晚报《“我们这都是通过陌陌招揽生意” 在陌陌“招嫖”明码标价》一文把陌陌推上舆论的风口浪尖，披露其平台上存在招嫖问题。该报记者在陌陌上找到“附近的人”这一栏，随机选取几个“美女”打招呼，收到“明码标价”——500元/2小时。
>
> 随后，新华社等多家媒体进行跟进报道，但陌陌官方并未予以回应。其实，这类招嫖模式，主要得益于陌陌LBS（基于地理位置的服务）功能，该功能也是陌陌早期破局的关键，助力其备受用户追捧。
>
> 要知道，用户在使用App过程中，需要给平台提供地理位置权限，使得聊天人群不再只是天各一方的网友，而是真实可以在线下碰面的人。有了LBS这一杀手锏，陌陌便在陌生人社交市场迅速站稳脚跟，积累不少活跃用户。
>
> 无论是陌陌还是被其收购的探探，它们能够迅速打开市场，对用户的吸引力不言而喻。说白了，这种打擦边球的做法在早期的确会起到刺激作用，但长此以往，陌陌构建的商业模式恐怕不健康。别看陌陌App下载量很高，但用户难以沉淀是一大硬伤。
>
> 或许是看到陌生人社交的局限性，一方面用户规模上不去，一旦陌生用户熟悉后，关系链很容易迁移到微信上，陌陌变相为微信打工，另一方面商业变现潜力也十分有限，因为陌生人之间聊骚带来的用户粘性难以持续。当2016年直播风口出现时，看到机会的陌陌迅速杀入，试图以秀场直播的形式继续玩转荷尔蒙经济。

大量虚假信息、骗子、甚至聊天机器人。打擦边球构筑的不健康的商业模式。用户粘性有限，商业潜力有限。软件缺乏加密措施，因此，稍有技术的黑客即可获取用户的用户名、密码、电话号码，甚至对话。

微信附近的人：基本凉了，骗子多https://www.zhihu.com/question/332890685

## 婚恋市场类（包含婚介）

[MarryU、世纪佳缘、珍爱网、Soul、探探、MOMO陌陌](https://zhuanlan.zhihu.com/p/67832782)

[像某缘，某合这些相亲网站靠谱吗？](https://www.zhihu.com/question/30901217/answer/929176711)

> 盐选专栏名：[《人间骗局：我曾在这里当骗子》](https://www.zhihu.com/xen/market/remix/paid_column/1174633181885509632)
>
> 作者：[@人间theLivings](https://www.zhihu.com/people/e5d6f7a90d20ec15b089d389d78b1689) 网易传媒旗下非虚构写作平台
>
> 网上征婚有一定的可靠性，最终能不能成，还是要看缘分。
>
> 我曾经被红娘半哄半骗着给一个婚介机构当过婚托，后来我才知道，稍微像点样的会员，红娘给他们安排的约会多得能飞起来，但就是不让轻易牵手，就算真看对眼了，也会想办法给搅黄。
>
> 毕竟对于婚介来说，资源是核心。一个婚介生意能不能红火，就看手头上有多少好资源。反正到了最后，只要能够完成合同约定的任务，他们的工作就算是做完了。

信息不实，婚介和外包合伙骗人，婚介收费按人来，越难的越贵，VIP费用一万起步，甚至有更贵的。金融理财诈骗、传销组织奔现

知乎上有大量的关于平台或代理商请的托恶意骗钱行为的例子，比如https://www.zhihu.com/question/37751869

[世纪佳缘维基百科](https://zh.wikipedia.org/wiki/%E4%B8%96%E7%BA%AA%E4%BD%B3%E7%BC%98)

> 2015年3月20日武汉晚报报导，有一名当地33岁男子小杰担任主管职位，[[4\]](https://zh.wikipedia.org/wiki/世纪佳缘#cite_note-4)分三次共缴纳45万元参加世纪佳缘高价上流专案征婚，其中多笔款项不开发票。之后两年与21位女孩见面但过程诡异。每次见面女孩无一例外要求高昂礼物，但之后又以失败收场，更荒唐是自己动用多名朋友追查还发现其中有当过妓女的失足女子。
>
> 2019年初[浙江电视台](https://zh.wikipedia.org/wiki/浙江电视台)打假节目《1818黄金眼》开始多集追踪一件吴先生的世纪佳缘相亲纠纷[[7\]](https://zh.wikipedia.org/wiki/世纪佳缘#cite_note-7)此案也导致世纪佳缘形象重创，事主在网站上注册后被介绍一名对象朱女，对方资料是北大毕业当老师同时父亲是大企业上市公司董事长，但该女子见面后却开始不断索要高价礼物，言行也不像大户人家教养，三天花近三万[人民币](https://zh.wikipedia.org/wiki/人民幣)然而后续蹊跷之处日多，查证过程世纪佳缘一再表示背景百分之百核实正确。
>
> 但记者媒体介入后全面追查，县教育局收到投诉一查发现，该女学历造假不是北大学士只是华东师范的远程函授中专学历，且四处欠债刚离婚并有两个小孩，其债主也以逃债向警方报案追逃朱女[[8\]](https://zh.wikipedia.org/wiki/世纪佳缘#cite_note-8)，她父亲也不是大公司董事长只是农民，学历造假事发后被杭州临平的私立学校快速开除。整个事件发酵过程世纪佳缘采回避与拖延态度，不肯正面出面面对媒体，只在电话中表示公司在处理中。之后世纪佳缘工作人员，在小吴不知情的情况下找到他家想协商，小吴并不想私下协商，报了警对方才离开。
>
> 之后电视台采取潜入搜查，[[9\]](https://zh.wikipedia.org/wiki/世纪佳缘#cite_note-9)一女记者冒充想要相亲的会员前往登记参加专案，出来接应的红娘老师所言云山雾罩，随意说出的男会员都是留学高富帅有车房，年薪四五十万人民币，全家都工程师等且又表明百分百核实。而要接触这些男人必须参加年费2.8万的专案，然而后续嫌贵之后又可讲价至半价甚至一万，还教导记者可以用“牵手后付”专案，相亲成功后要男方来付。整体过程随意性极高，话术荒谬，且女方资料[学历](https://zh.wikipedia.org/wiki/學歷)收入由记者随意填写，不必拿出任何证据，红娘老师就开始用此资料建档联络男子。
>
> 事件大规模扩散后开始有众多[[10\]](https://zh.wikipedia.org/wiki/世纪佳缘#cite_note-10)世纪佳缘前任加盟店的店长出来爆料，表示该公司经营混乱，收取高额加盟金后放任店家自生自灭与当初的入盟说明差距大，总公司从未能提供大量优质的会员数据库供店家运转，反而是一些少量劣质的资料，甚至前任[青岛](https://zh.wikipedia.org/wiki/青島)加盟商说一百笔资料中可信的不到两三笔，多数会员的背景家庭资料、学历、收入、犯罪前科都是随意假冒且未经核实就被挂上百分百真实的口号，加盟店自力下去核实后剃除不能用的假会员仅剩少少人数能运转介绍，尤其女少男多现象极为严重，[深圳](https://zh.wikipedia.org/wiki/深圳)与湖州前任加盟商都爆料此时总公司还明示他们找演员“婚托”出面假相亲后再说失败，以应付缴钱会员合约的介绍人数量承诺。

存在大量不实个人信息

过于严格的筛查审核机制会劝退很多用户，用户不愿意一次性上传过多真实个人信息和照片，如学位证身份证等

存在不少诈骗传销等

盈利主要靠VIP或一对一红娘收费，收费普遍极高，条件差距大的收费更高，甚至于几十万的天价中介费。

## 兴趣交友类

### Soul

https://www.soulapp.cn/

Soul App通过“智能匹配算法”一键推荐用户可能喜欢的人和内容，帮助用户随时随地和聊得来的朋友沟通交流，降低孤独感，提升每个人的生命质量，让个人更幸福，社会更加和谐美好。

灵魂匹配，属于你的灵魂伴侣。分享生活与热爱。AI 智能精准匹配，随时随地。与志趣相投的 Souler 开启会话，和尬聊说拜拜。匹配的依据是用户在上面做的测试结果，测试一共分为初中高三个阶段，测试结果会包括三观，感情，喜好，品位等多个维度。Soul会根据测试得出的个人特征，选择match率高的对象和用户聊天。

语音匹配 实时社交

开启视频脸基尼，趣味 AR 贴纸和脸基尼为你保护隐私，想要视频却不想露脸？

瞬间广场，分享类型丰富的瞬间，更不要吝惜你的点赞与评论。还有随机电台，精彩瞬间边听边刷。

推荐理由：不用看脸也能聊天。这款app主打灵魂社交的路线，匹配的方式是通过性格测试，甚至连头像都不能用自己的照片。可以当成匿名树洞使用

但是：[现在的soul让你感觉恶心吗？](https://www.zhihu.com/question/385963024/answer/1159129055)

类似树洞的匿名性也引出了人性的黑暗面hhh

> 一个灵魂交友的软件硬生生的变成了颜值交友，当然不仅仅如此，据说soul里面男生人均180+，女生人均170+，人均保时捷。在异性交友软件中，这也很正常。但是一张口就小哥哥，小姐姐的叫，交完后开始查户口，查完后又立马要照片，照片看了之后再决定是否继续聊下去是啥意思？还是灵魂交友吗？

> 广场上全是低质量的瞬间
>
> 人的恶心，是app的恶心变来的
>
> 和政治有关的不能发，随便沾点东西的就不能发，恶意语言不能发，带友商app链接的不能发
>
> 而且你的图片里带这些字的也不行，我真的吐了
>
> 如果微信的屏蔽等级是0，英雄联盟的屏蔽等级是5，那soul的屏蔽等级得是100
>
> 聊天功能我唯唯诺诺，屏蔽关键词我重拳出击

> 女生是高贵冷艳的灵魂选手
>
> 男生是癞蛤蟆想吃天鹅肉的迪奥丝

> 刚开始为了口碑，而且进来的人也都三观很正，互相学习，能够坦诚相待。后来为了流量，大量广告，导致鱼龙混杂，聊骚的、约p的啥的都有。低级趣味的人多了，有趣的灵魂也都受不了走了，所以质量大不如前。

总的来说，SOUL开始的模式很吸引人，类似树洞的匿名，个人信息的自由，和探探等yp应用区分开了。但是没有树洞的自由，屏蔽词恶心用户。匿名下的乱象丛生令这个平台鱼龙混杂，广场变为寻求满足感的匿名微博式平台。

Summer主打高校市场：分享校园欢乐日常、大学生专属身份认证、面向全国高校开放、答题交友 趣味刷题

[兴趣交友会成为引领社交app赛道的独角兽吗？](http://news.iresearch.cn/yx/2020/11/346289.shtml)柠檬畅聊-好玩的兴趣社交平‪台

## 聊天软件类

[你最讨厌 QQ 什么？](https://www.zhihu.com/question/20799706)

[你最讨厌微信什么？](https://www.zhihu.com/question/320876465)

略

## 同性交友类

Blued

[Blued官方网站-上小蓝倡导健康生活](https://blued.cn/)

Github(大雾)

豆瓣

## 综述

[陌生人社交业务的冰与火](https://zhuanlan.zhihu.com/p/352422530)

[00后社交：兴趣，荷尔蒙，与交友的秘密](https://36kr.com/p/1724671377409)

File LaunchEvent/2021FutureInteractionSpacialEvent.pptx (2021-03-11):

## Future Interaction Special Event

π - Wiktionary

## 硬件 软件 生态

## 硬件

- NFC加持
- 多样化封装可供选择
  - PCB基板卡片
  - 塑封标签（方卡或圆卡）
  - 贴纸
  - 手机壳
  - 美甲芯片
- 内置电纸屏，显示二维码等信息
- 表面触摸按键，支持录入并切换不同卡片，门卡、水卡、会员卡
- 定制款及联名款卡片

## 软件

- 多端自适应网页（安卓、苹果）
- 更多功能的APP（Google Store、Apple Store）
- 自然交互，接续自动弹出的提示框
- 好友Follow系统，查看Follower共享给你的TA的信息吧~
- 内置文字/视频/语音聊天，还有兴趣广场，一起攒事儿
- 自定义主页预设，可当场选择想给TA看的信息，真正做到千人千面
- 和不同社交软件联动，在其他软件里面展示自己不同角度的闪光点吧

## 服务

- 组织线下主题兴趣小聚，给有共同兴趣话题的人提供机会
- 免费提供服务，无广告

## 问题提出

- 友商们已经做了很多陌生人社交软件，但是探探下架了，陌陌搞直播了，主打灵魂交友的Soul变味了，连微信附近的人也差不多凉了。
- 想要交到好朋友、拓展自己社交圈子、想之后认真谈恋爱的用户，其实并不会去使用这些被打上约炮标签的地理位置服务交友软件，这些软件不具有可持续性，用户粘性和商业潜力都有限
- 另一边，婚恋网站充斥着婚托和骗子，平台服务费也动辄上万。世纪佳缘、百合网上丑闻频出，甚至有程序员被骗婚自杀。

## 社交流程

- 相比于约炮应用，我们提供相识机会，但更注重引导关系的发展。
- 相识：线下见面认识，真实的你们给双方增加信任，生活在你身边的人，为以后的关系发展提供更多的机会
- 了解：除了两人见面聊天，平台联动的其他社交帐号也给你提供了多面展示自己和寻求共同话题的机会。比如咱俩都是UP主。
- 发展：兴趣小组聚会，进一步提供见面的机会

## 信息安全和心理负担

- LBS应用普遍存在的问题，海量个人信息（特别是位置信息）泄露的可能性
- 不再要求用户提供位置权限
- 用户不必向公网公布个人信息，如照片，也不必给平台提供任何信息
- 卡片加密，每张卡都有UID，丢卡可随时锁定卡片

## Slogan

- iTag-从见面开始的微微熟社交生态

## 产品视频

- DEMO视频
- 兴趣小聚，见面，聊两句，碰一碰。
- 浏览，找到兴趣共同点
- 再次相见，约咖啡
- 产品宣发三个视频

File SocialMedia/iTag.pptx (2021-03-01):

## iTag

一款从线下开始的陌生人社交应用
Designed By Tingliang

## 陌生人社交的定义

- 我司要重新定义陌生人社交！（手动狗头）

Ref 陌生人社交业务的冰与火 https://zhuanlan.zhihu.com/p/352422530

## 陌生人社交的定义

- 互联网语境下的社交是用户间的信息交流和互动，最典型的社交产品是早期的微信和QQ，但现在微信和QQ已不仅仅是社交产品，更是生活方式。
- 在社交的分类中，按用户关系距离来分，可分为熟人社交（QQ、微信）和陌生人社交（探探、陌陌、Soul、她说等婚恋交友软件）。
- 从社交的定义可以得到陌生人社交指陌生用户间的信息交流和互动，社交整体过程归纳总结起来就是以下两点：关系的建立+关系的沉淀（维系和发展）。而陌生人社交的重点会更偏关系的建立，特点是：它是对现实的补充，具有很大的虚拟性。

preview

## 陌生人社交的目的

preview

## 陌生人社交市场分析

- 市场容量几个亿呀？

## 陌生人社交市场分析

preview

## 陌生人社交的困境

- 划卡匹配导致的流量中心化——少数颜值高的用户获取了大部分的社交机会。
- 在东亚，带有色情味道的陌生社交产品大家使用时会有一定压力，会在意主流社会的眼光。
- 无法保证能找到一个聊得来的朋友或者伴侣，这种不确定性让用户退缩，尤其在概率过低时，随着用户使用成本的提高，用户更不愿意使用。
- 网络空间的陌生人社交中行为成本低，骚扰行为频发，极其伤害用户的体验，导致用户的流失
- 由于恶意用户的存在，用户之间的信任度较低，而这又进一步地导致了优质用户不愿意使用陌生人社交软件，形成恶性循环。
- 触及色情诈骗等灰色地带，遭到监管部门打击

## 陌生人社交应用分类及举例

- 庭梁分类法，仅供参考，本人对其科学性不负任何责任。

## 陌生人社交应用分类

- LBS社交 主打sex without relationships
  - Tinder
  - 微信附近的人
  - 探探
  - 陌陌
- 婚恋市场系
  - 世纪佳缘
  - 珍爱网
- 兴趣交友类
  - Soul
  - Summer

## 基于地理位置的社交应用程序

- 主要基于地理位置和大数据平台，向用户提供个性化推荐。
- 其在交互方式上采用了简单的动作设置：如果喜欢某一对象，就往右滑，不喜欢则往左滑。
- 之后，系统自动进行配对，如果双方互相喜欢，系统会明确告知给两个用户，双方才能开始聊天，否则彼此不会收到任何消息。

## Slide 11


Ref 维基百科 https://en.wikipedia.org/wiki/Tinder_(app)

## Tinder

- 左滑右滑
- 配对机制
- 和Facebook Instagram等社交软件的联动
- 付费版本可以Like更多的人，甚至在Like之前看这个人有没有Like你
- SOS报警功能

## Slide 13


Ref 维基百科 https://en.wikipedia.org/wiki/Tinder_(app)

## 信息安全问题和隐患

- 每次打开和进行匹配的精确地理位置甚至聊天视频内容的泄露漏洞
- 卫报记者单人长达800页的用户数据历史，包括时间、地点、个人喜好、受众人群、每个照片浏览时间。
- 连自己都不知道的私密信息泄露的可能性

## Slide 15


陷入招嫖争议、市值跌去六成，陌陌到底怎么了？
https://www.jiemian.com/article/5703382.html

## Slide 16


Ref 维基百科 https://en.wikipedia.org/wiki/Tinder_(app)

## 陌陌（以及被其收购的探探）

- 大量虚假信息、骗子、甚至聊天机器人。
- 打擦边球构筑的不健康的商业模式。
- 用户粘性有限，商业潜力有限。
- 软件缺乏加密措施，因此，稍有技术的黑客即可获取用户的用户名、密码、电话号码，甚至对话。

## 相亲应用和婚恋市场

- 婚恋市场更加功利
- 主要玩家包括世纪佳缘&百合网、珍爱网等
- 用户普遍为30-40岁，有更高的收入，追求相亲的效率
- VIP服务收费较高，从几万到几十万不等

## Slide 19


Ref 像某缘，某合这些相亲网站靠谱吗？https://www.zhihu.com/question/30901217/answer/929176711

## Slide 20


Ref https://zh.wikipedia.org/wiki/%E4%B8%96%E7%BA%AA%E4%BD%B3%E7%BC%98

## 相亲网站的问题

- 信息不实，婚介和外包合伙骗人，婚介收费按人来，越难的越贵，VIP费用一万起步，甚至有更贵的。金融理财诈骗、传销组织奔现。知乎上有大量的关于平台或代理商请的托恶意骗钱行为的例子
- 存在大量不实个人信息，但是过于严格的筛查审核机制会劝退很多用户，用户不愿意一次性上传过多真实个人信息和照片，如学位证身份证等
- 盈利主要靠VIP或一对一红娘收费，收费普遍极高，条件差距大的收费更高，甚至于几十万的天价中介费。

## 兴趣交友类

- Summer主打高校市场：分享校园欢乐日常、大学生专属身份认证、面向全国高校开放、答题交友
- Soul则主打匿名性的轻松感，不用上传头像、视频露脸或者实名。

## Soul APP

- Soul App通过“智能匹配算法”一键推荐用户可能喜欢的人和内容
- 灵魂匹配，属于你的灵魂伴侣。匹配的依据是用户在上面做的测试结果，测试结果会包括三观，感情，喜好，品位等多个维度。Soul会根据测试得出的个人特征，选择match率高的对象和用户聊天。
- 语音匹配 实时社交
- 开启视频脸基尼，保护隐私，视频不露脸
- 瞬间广场，分享类型丰富的瞬间。还有随机电台，精彩瞬间边听边刷。
- 推荐理由：不用看脸也能聊天。这款app主打灵魂社交的路线，匹配的方式是通过性格测试，甚至连头像都不能用自己的照片。可以当成匿名树洞使用

Ref soul官网介绍 https://www.soulapp.cn/

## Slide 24


Ref 现在的soul让你感觉恶心吗？https://www.zhihu.com/question/385963024

## SOUL目前的问题

- SOUL开始的模式很吸引人，类似树洞的匿名，个人信息的自由，和探探等应用区分开了。
- 但是屏蔽词过多，甚至其他网站链接都会屏蔽。
- 匿名下的乱象丛生令这个平台鱼龙混杂，广场变为寻求满足感的匿名微博式平台。

## iTag的构想

- 此章节纯属虚构，具体请以实物为准
- 如有雷同，他抄我的

## 痛点

- 信息安全问题：LBS应用普遍存在的问题，海量个人信息（特别是位置信息）泄露的可能性
- 用户人身安全问题
- 荷尔蒙导向应用的不可持续性和用户留存率低
- 很多人不愿意不希望自己的真实照片被公开，被挑选。
- 关键词审核过于严格，实名信息审查过于敷衍了事
- 大量虚假用户和骗子，平台鱼龙混杂
- 平台收费过高，线下分店通过和代理商和托儿一起蒙骗客户盈利
- 流量中心化：少数用户获得多数资源——社交资本太单一，基本就只以颜值为主

## 提出

- 不再要求用户提供位置权限
- 用户不必向公网公布个人信息，也不必给平台提供任何信息
- 提倡长期关系，而非荷尔蒙驱动关系
- 多元的社交资本，避免流量中心化
- 安全的兴趣广场
- 可持续发展，高的用户留存度
- 全免费平台，无广告环境

## 解决

- 一款从线下开始的陌生人社交应用：
- NFC卡片加持，只有刷卡才能加好友哦
- 自定义主页预设，可当场选择想给TA看的信息，真正做到千人千面
- 和不同社交软件联动，在其他软件里面展示自己不同角度的闪光点吧
- 组织线下主题兴趣小聚，给有共同兴趣话题的人提供机会
- 定制联名款卡片，你就是人群中最亮的崽
- 好友Follow系统，查看Follower共享给你的TA的信息吧~
- 免费提供服务，无广告

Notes: 什么叫良心企业，这就叫良心企业——清美交互

## 说明

- 真实世界中见过，甚至能验证身份（比如看看学生证），大大增加了安全感，妈妈再也不用担心我被假人骗的团团转啦~
- 路上碰见合适的，就大胆去给TA你的卡片吧~
- 从不同角度寻找共同兴趣和话题，增加做朋友的可能性

## 谢谢!

- 可参考Github上可超链接报告
- https://github.com/TingliangZhang/girlsday2021/blob/main/SocialMedia/SocialMedia.md

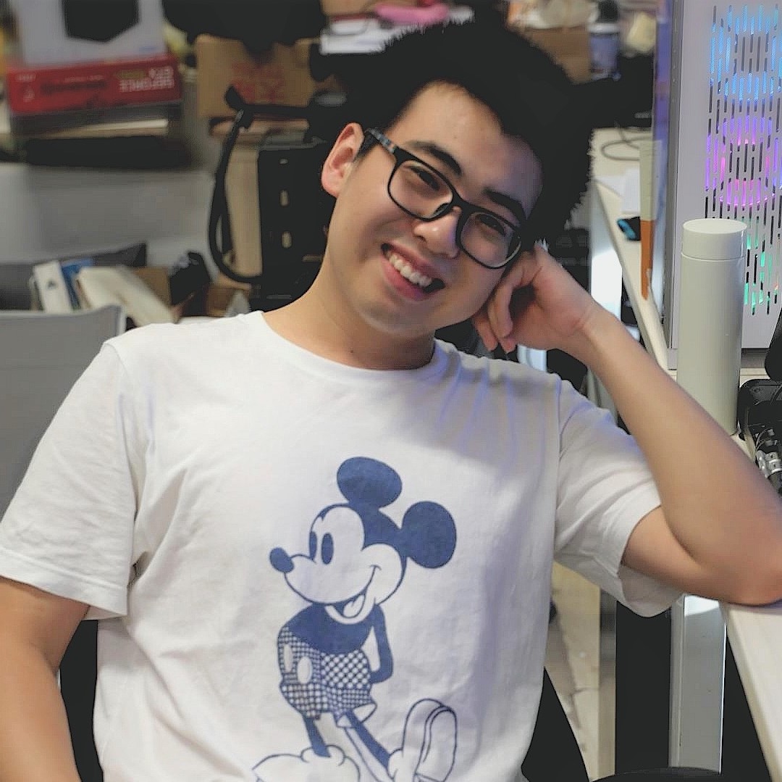
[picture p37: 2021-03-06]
Blog/assets/images/Tina.jpg

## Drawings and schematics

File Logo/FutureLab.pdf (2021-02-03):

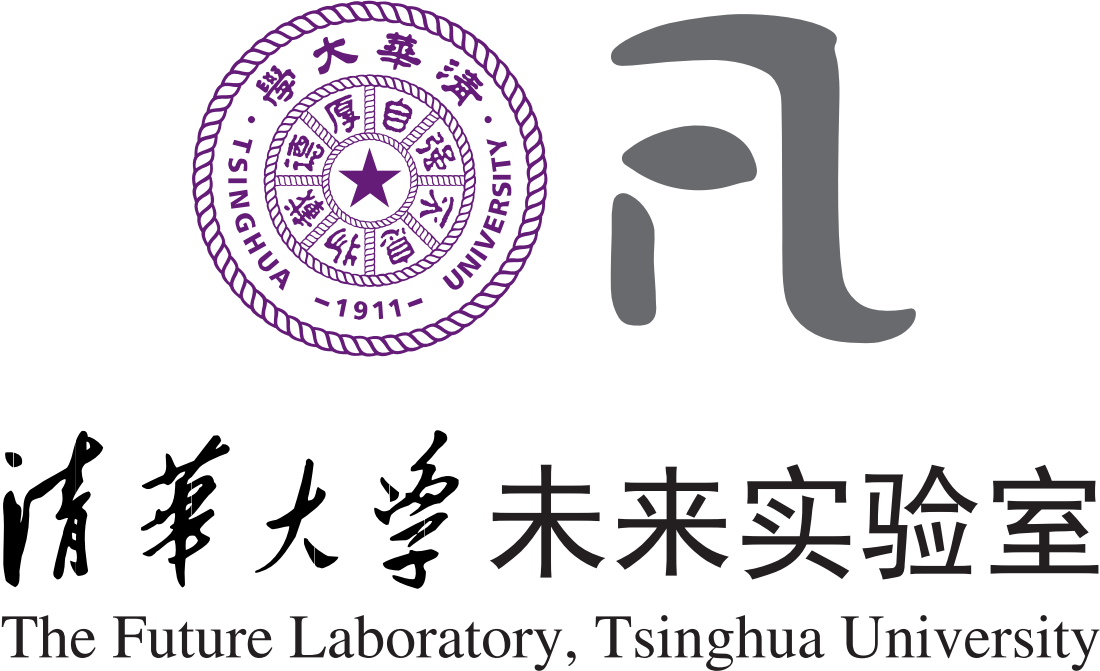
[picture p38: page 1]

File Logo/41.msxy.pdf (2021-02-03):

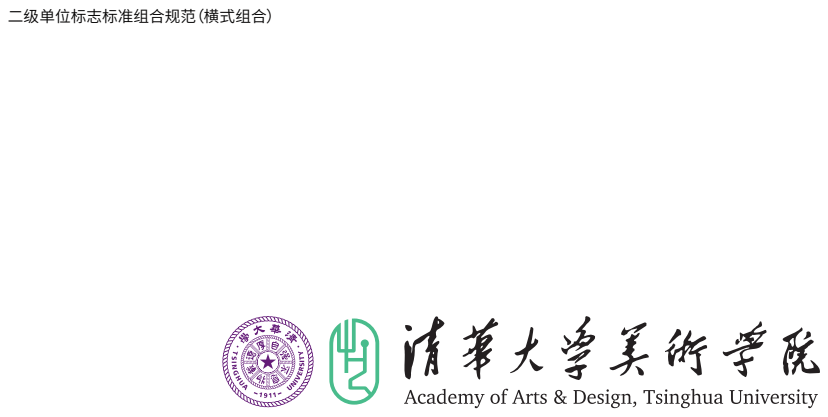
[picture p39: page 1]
二级单位标志标准组合规范（横式组合）

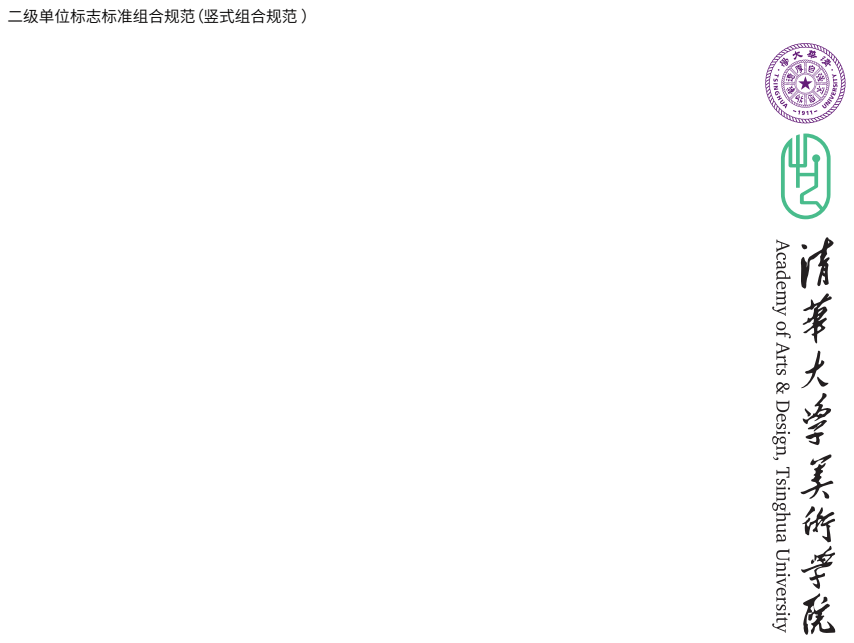
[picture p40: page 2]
二级单位标志标准组合规范（竖式组合规范 ）

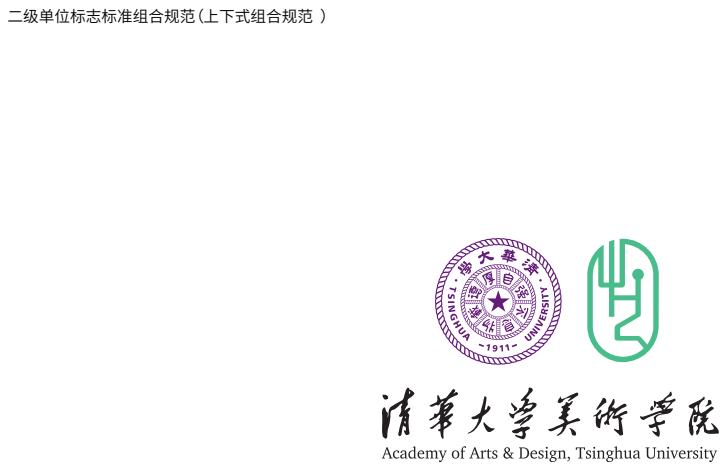
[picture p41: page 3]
二级单位标志标准组合规范（上下式组合规范 ）

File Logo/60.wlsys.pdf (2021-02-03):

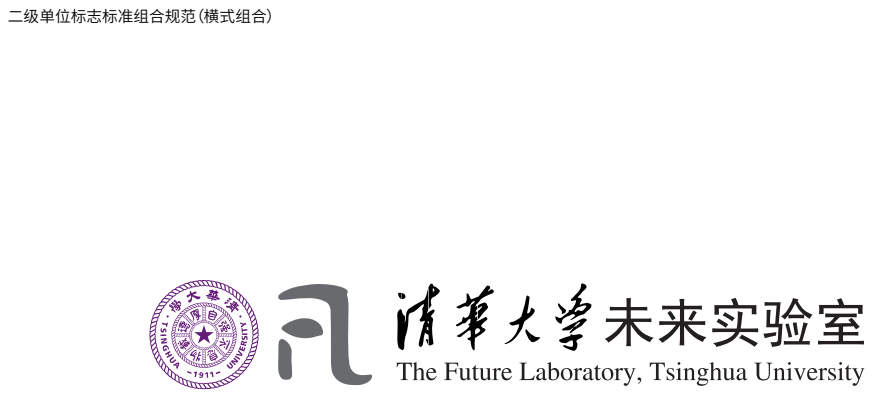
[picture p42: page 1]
二级单位标志标准组合规范（横式组合）

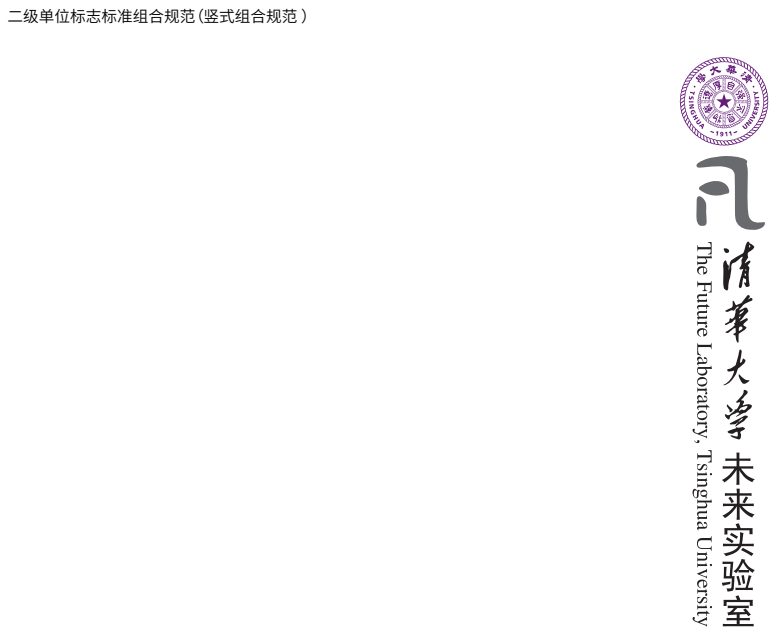
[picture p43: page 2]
二级单位标志标准组合规范（竖式组合规范 ）

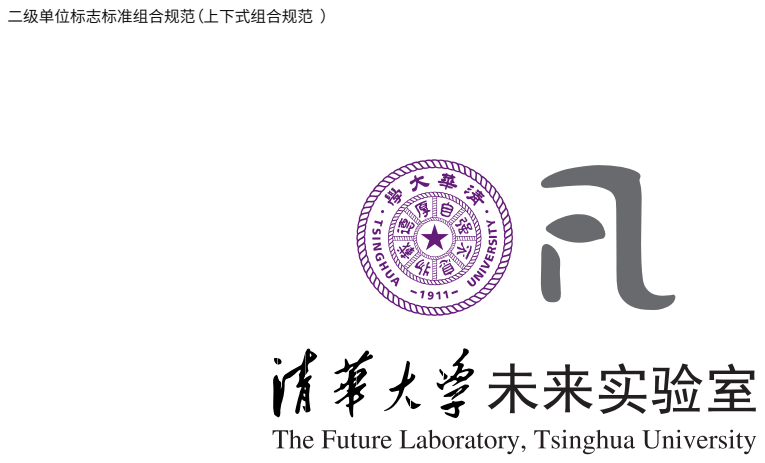
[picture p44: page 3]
二级单位标志标准组合规范（上下式组合规范 ）

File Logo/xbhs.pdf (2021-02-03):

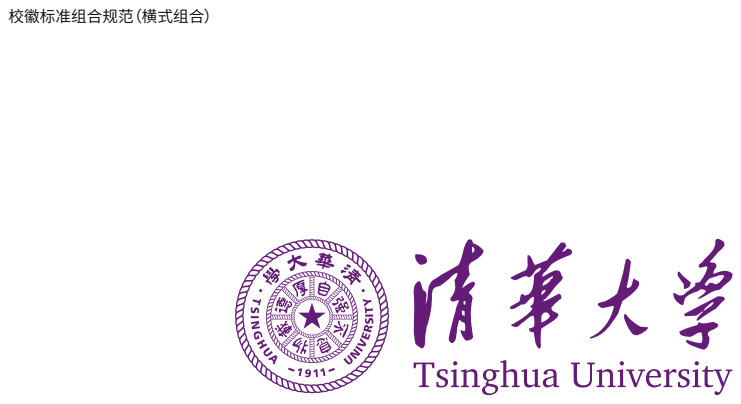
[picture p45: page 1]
校徽标准组合规范（横式组合）

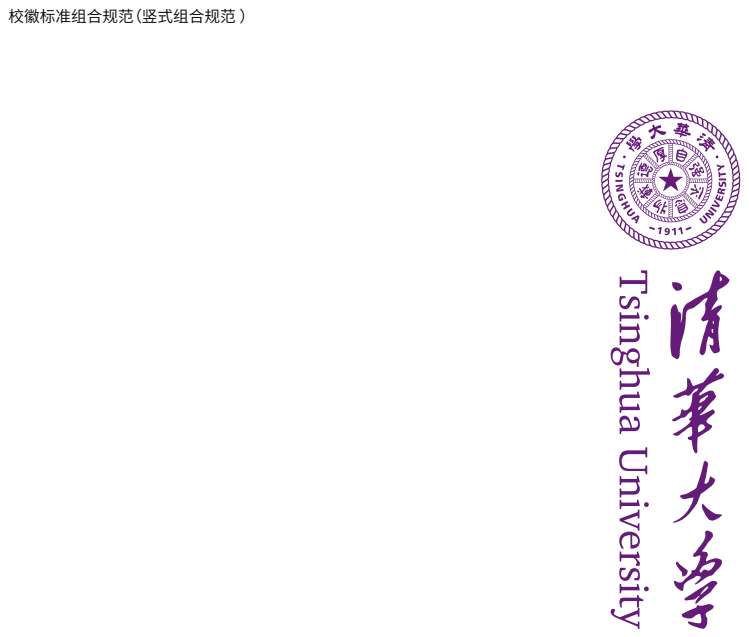
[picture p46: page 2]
校徽标准组合规范（竖式组合规范 ）

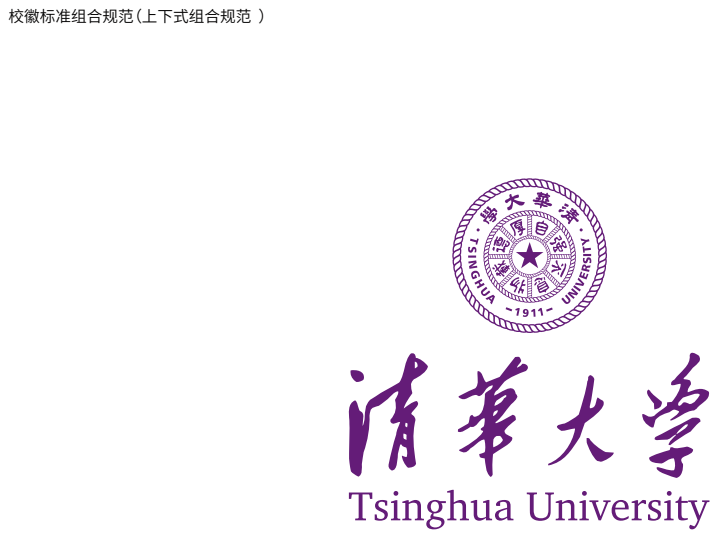
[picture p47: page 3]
校徽标准组合规范（上下式组合规范 ）

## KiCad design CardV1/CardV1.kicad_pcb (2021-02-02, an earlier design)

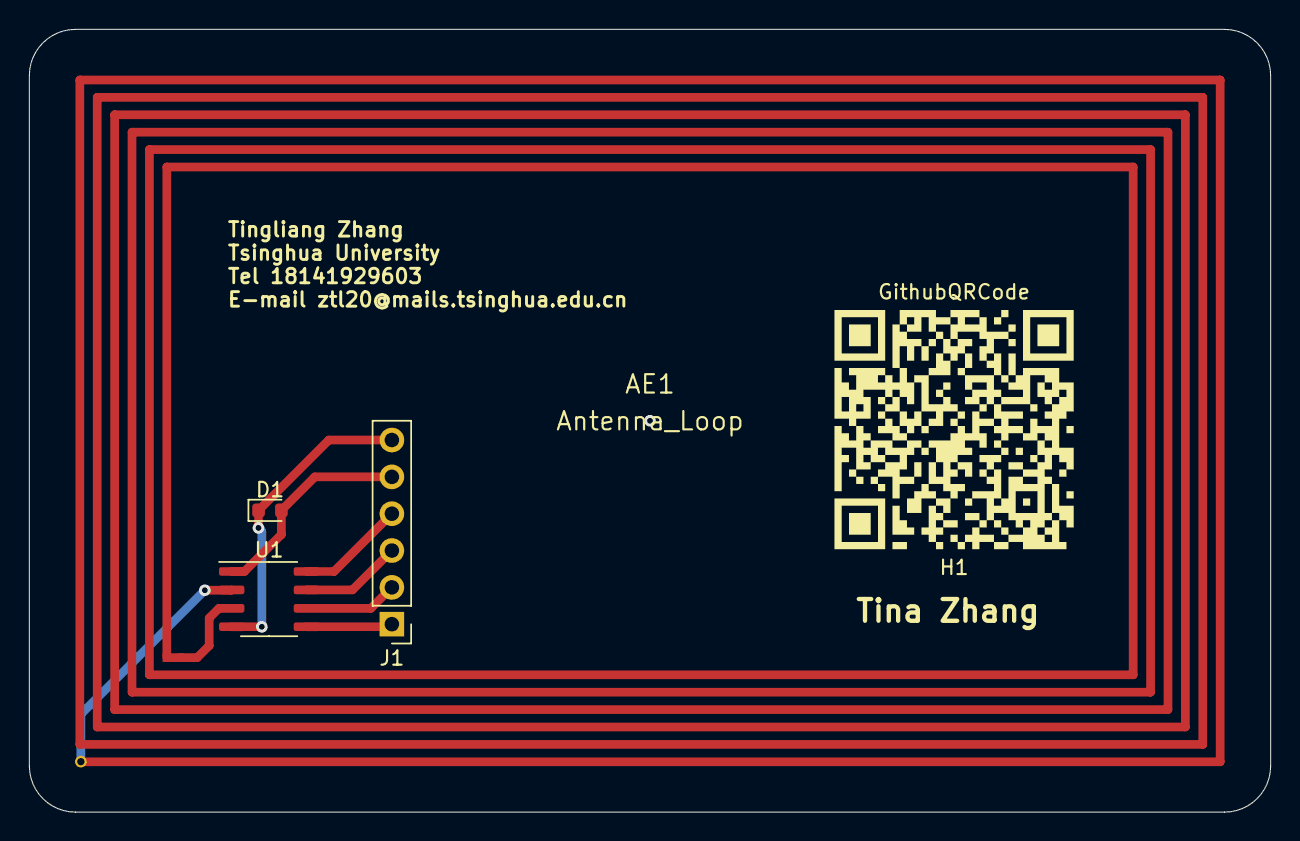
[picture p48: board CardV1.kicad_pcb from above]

Board: 2 copper layers, 85.6 x 54.0 mm, 5 parts (0 on the bottom side), 8 nets.

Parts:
AE1: Antenna_Loop; NFC-Antenna_6_79.24x47.62_0.6x0.6mm
D1: LED; LED_0603_1608Metric
H1: GithubQRCode; tingliangzhang-github-io
J1: Conn_01x06_Male; PinHeader_1x06_P2.54mm_Vertical
U1: M24LR04E-R; SO-8_3.9x4.9mm_P1.27mm

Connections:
+5V: D1.2, J1.5, U1.1
GND: D1.1, J1.6, U1.4
unnamed: AE1.1, U1.3
unnamed: AE1.2, U1.2
unnamed: J1.1, U1.5
unnamed: J1.2, U1.6
unnamed: J1.3, U1.7
unnamed: J1.4, U1.8

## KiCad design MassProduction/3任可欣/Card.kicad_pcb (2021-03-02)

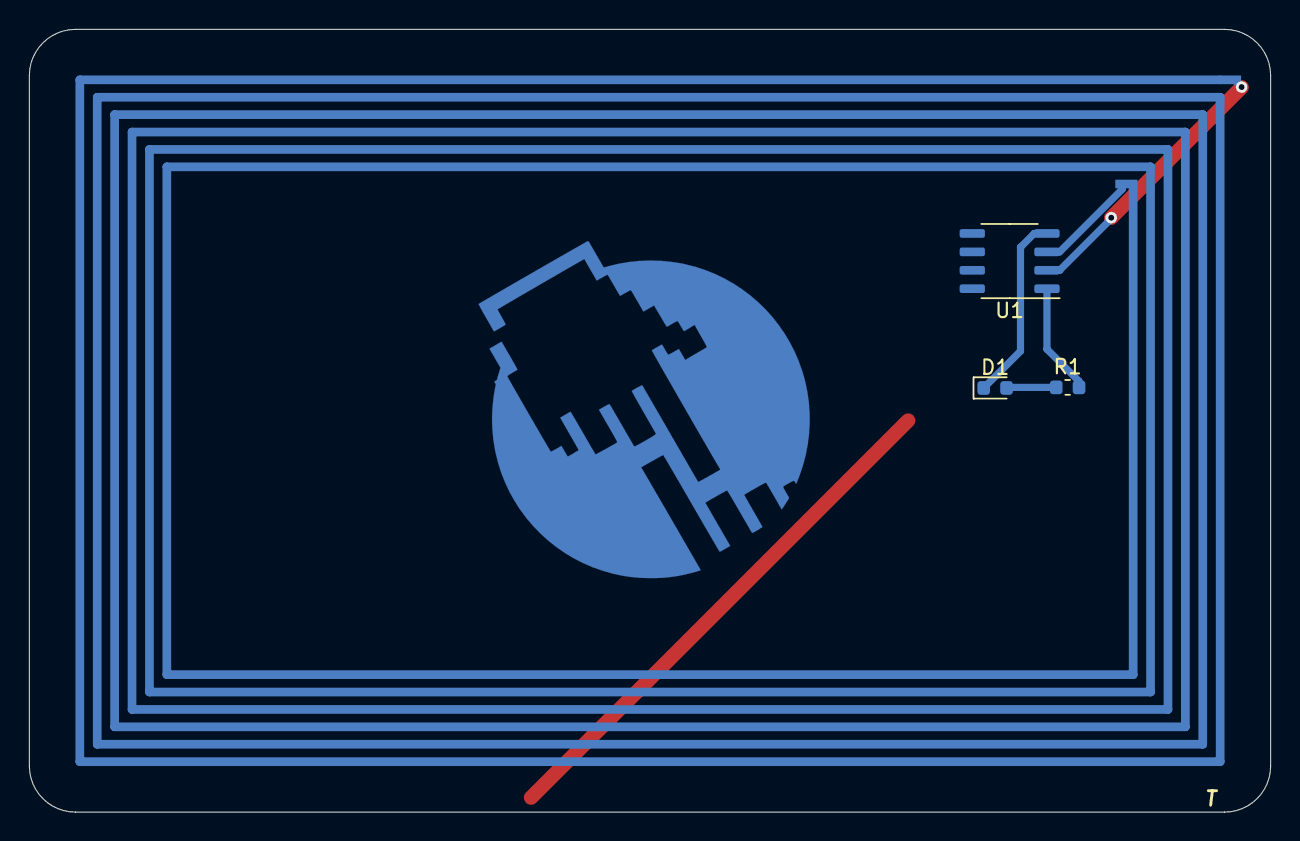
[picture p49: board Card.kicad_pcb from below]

Board: 2 copper layers, 85.6 x 54.0 mm, 5 parts (4 on the bottom side), 5 nets.

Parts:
AE1: Antenna_Loop; NFC-Antenna_6_79.24x47.62_0.6x0.6mm
D1: LED; LED_0603_1608Metric
QR: https://interact.cool/; interact.cool
R1: R; R_0603_1608Metric
U1: M24LR04E-R; SO-8_3.9x4.9mm_P1.27mm

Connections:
+3V3: R1.2, U1.1
GND: D1.1, U1.4
unnamed: AE1.1, U1.3
unnamed: AE1.2, U1.2
unnamed: D1.2, R1.1

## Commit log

2021-01-30 使用本地照片
2021-01-31 Begin Antenna Drawing
    [CardV1.kicad_pcb]
2021-02-01 nfc-antenna-generator HTML
2021-02-01 Update NFCAntenna.py
    终于能画出线啦
2021-02-02 Almost Finish
    [CardV1.kicad_pcb, CardV1.sch]
2021-02-02 V1打样
2021-02-02 Tile大小版本设计
2021-02-02 ST25 lib
    [CardV2.kicad_pcb, CardV2.sch]
2021-02-03 Almost Finish V2
    [CardV2.kicad_pcb, NFC_N-Mark_Logo.dxf]
2021-02-03 失败的拼版
    [CardV2.kicad_pcb]
2021-02-03 拼板总结
2021-02-03 拼板完成
    [CardV2.kicad_pcb]
2021-02-03 改为单板
    [CardV2.kicad_pcb]
2021-02-07 V1和V2调试
2021-02-11 NFC 墨水屏 测试
2021-02-12 V3 Update
    [Card.kicad_pcb]
2021-02-18 备案总结
2021-02-18 安Ubuntu虚拟机
2021-02-19 Jekyll成功运行
2021-02-21 先试试Debian 10.8.0 (amd64, Live CD with gnome and non-free firmware)
2021-02-23 装服务器总结
2021-02-23 在Debian之上安装PVE
2021-02-24 R720上Proxmox的问题
2021-02-26 R720上Proxmox的问题solve
2021-02-26 mount ssd
2021-02-26 上传iso的大坑
2021-03-01 Import PCB Ruler Lib
2021-03-01 我枯了，大家觉得这一版本不好看，改
    [Card.kicad_pcb, Card.sch]
2021-03-01 V3.2 ini
    [Card.kicad_pcb, Card.sch]
2021-03-01 Finish 3.1 ?
    [Card.kicad_pcb]
2021-03-02 Add Interaction LOGO
    [Card.kicad_pcb]
2021-03-02 断掉LOGO回路
    [Card.kicad_pcb]
2021-03-02 批量产出
    [102603232_2_交叉学科同学通讯录_20_20.xlsx, 108567976_2_交叉班女生节礼物信息填写_8_8.xlsx, Card.kicad_pcb]
2021-03-08 V4 ini
    [Card.kicad_pcb, Card.sch]
2021-03-08 Finish and Print V4
    [Card.kicad_pcb, Card.sch]
2021-03-14 del swiss
    [Swiss.kicad_pcb]
